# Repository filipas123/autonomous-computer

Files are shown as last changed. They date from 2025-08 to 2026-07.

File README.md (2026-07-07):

# Time to build your own Personal AI Computer

https://github.com/user-attachments/assets/36f7aa02-42ac-4b35-b757-a5dd3b43ef1a

## The future of AI is local

AI in 2026 looks like computing in 1975: the intelligence lives in a few mainframes, owned by a few companies, and you rent it by the token. Everyone knows how that movie ends. The machine moves onto the desk — and the people who own their machines build everything that comes next.

The Personal AI Computer is that machine. The models are good, the GPUs are affordable, and homes and businesses are reaching the same answer: bring it in-house. Three reasons:

1. **No one can switch you off.** In June 2026 the US government took Fable 5 offline for most of a month and gated GPT-5.6 behind an approved-partner list. Weights on your own disk can't be revoked.
2. **Your business is their training data.** Every prompt you send OpenAI or Anthropic carries your product, your process, your edge. They will turn your secret sauce into their product.
3. **Inference becomes free.** Open weights on a cloud API already cut the bill 20–30×. On your own machine there is no bill at all. No API, no meter.

## The end-to-end open-source local AI stack

Open software lets you run and shape your AI; open hardware lets you build, repair, and improve the machine it runs on. With both in your hands — the code, the CAD, the BOM, the BIOS settings — you can build the whole thing end to end. So we open-source both:

- **Open Source Hardware — this repo.** Your Personal AI Computer in four sizes, below: every part, every bracket, every BIOS setting, every assembly photo.
- **Open Source Software — your choice.** The easiest way is [Grid](https://github.com/autonomous-ai/autonomous-grid), the open orchestrator for local AI — but any local AI engine works: vLLM, Ollama, llama.cpp.

## 2× NVIDIA RTX 5090

The entry-level build, for personal use. Enough for Llama, Qwen, and DeepSeek with quantization — run OpenClaw, Hermes Agent, or your own LangChain stack locally.

- **2× NVIDIA RTX 5090** — 64 GB VRAM · 3,584 GB/s · 419 FP32 TFLOPS
- **Intel Xeon W5** (ASUS W790 ACE) · 96 GB RAM · 1 TB NVMe
- **PCIe Gen 5 ×16** per GPU · 10 GbE + 2.5 GbE
- **1,550 W draw** · 1,600 W PSU
- **12.5″ × 12.5″ × 16″** · 33 lb

**[Build the 2× 5090 →](2x-5090/README.md)**

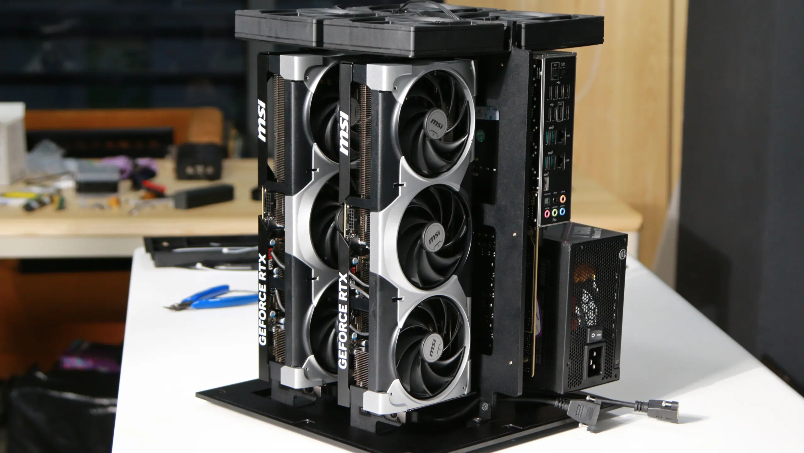
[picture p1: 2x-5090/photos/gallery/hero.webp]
The 2× 5090 build — two RTX 5090s on the open frame


<table>
<tr>
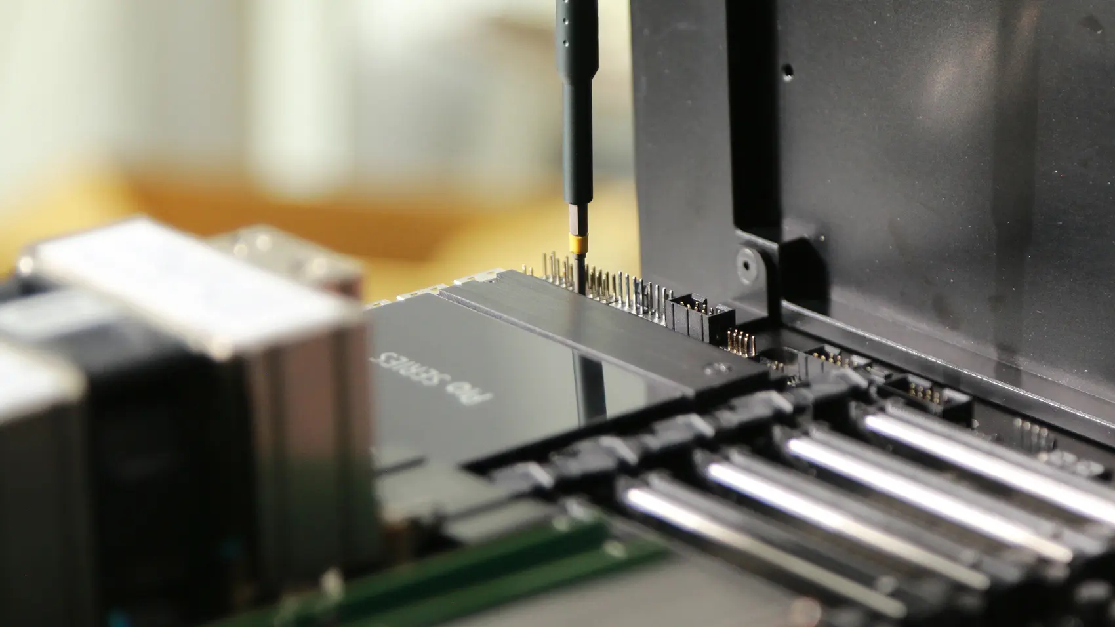
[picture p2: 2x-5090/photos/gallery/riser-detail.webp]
Seating the PCIe riser
<td width="50%"></td>
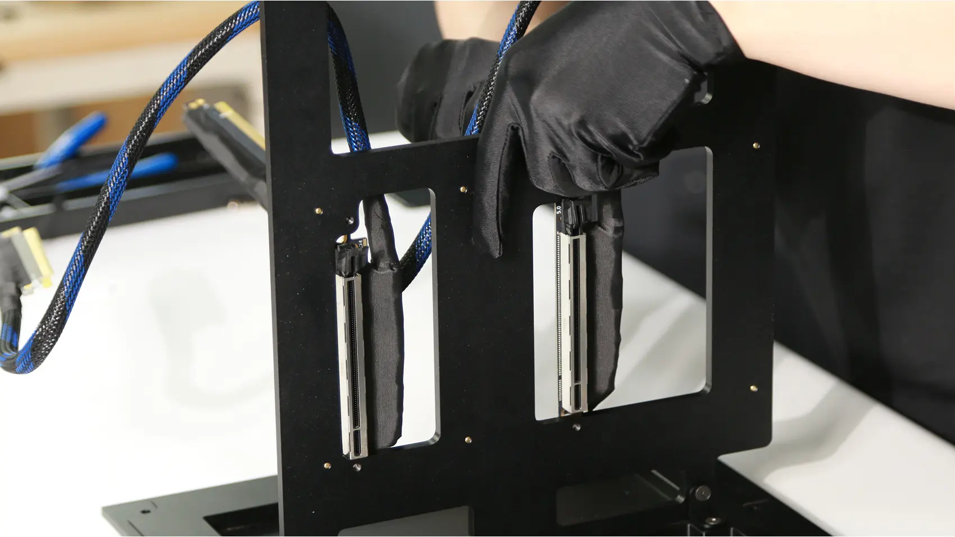
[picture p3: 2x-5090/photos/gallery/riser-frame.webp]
Mounting the PCIe 5.0 risers
<td width="50%"></td>
</tr>
<tr>
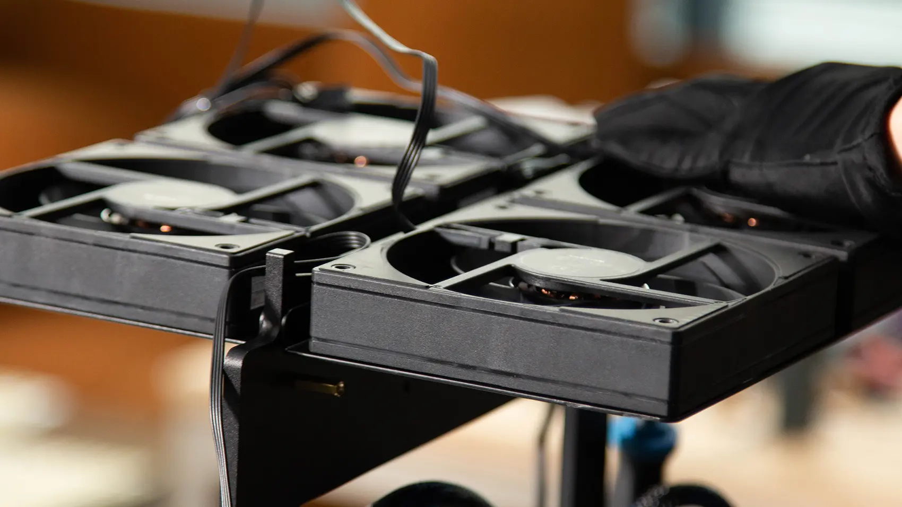
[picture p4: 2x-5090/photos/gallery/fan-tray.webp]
The fan tray
<td width="50%"></td>
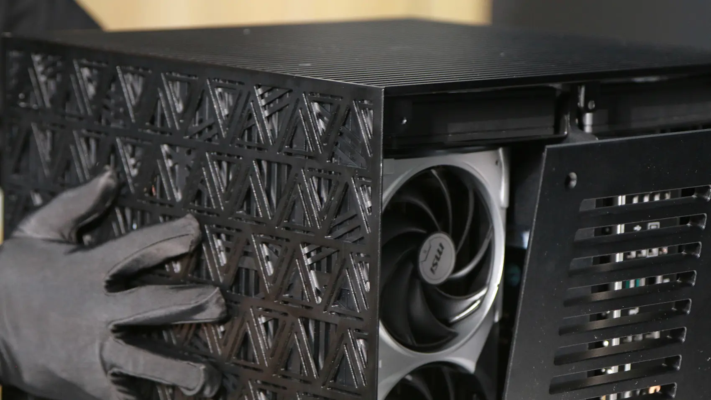
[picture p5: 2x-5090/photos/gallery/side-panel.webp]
Closing the side panel
<td width="50%"></td>
</tr>
</table>

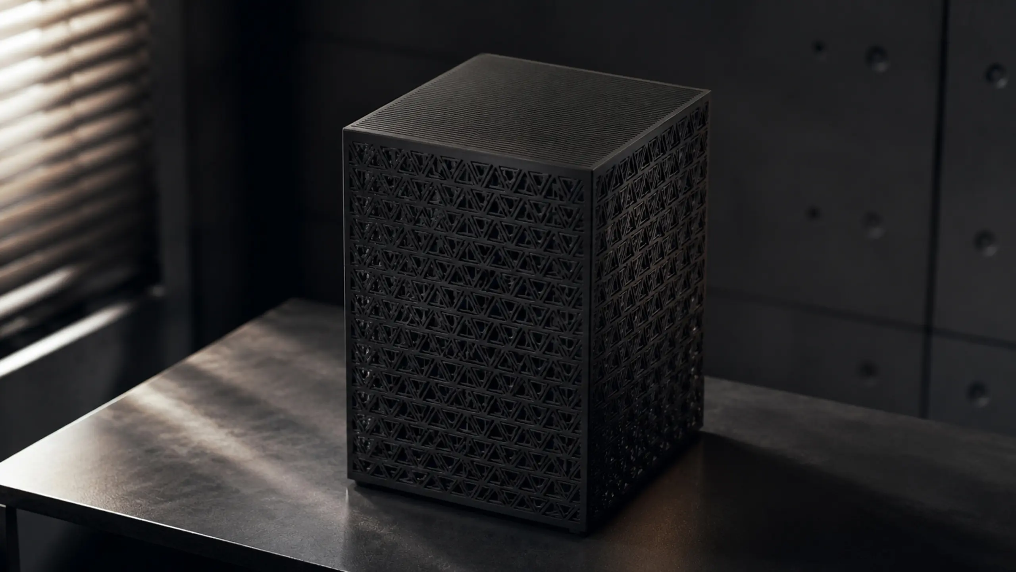
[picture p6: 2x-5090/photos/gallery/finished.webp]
The finished 2× 5090


## 4× NVIDIA RTX 5090

The team build. Larger open models like Kimi, MiniMax, and GLM. No API bills. Low latency. Private data.

- **4× NVIDIA RTX 5090** — 128 GB VRAM · 7,168 GB/s · 838 FP32 TFLOPS
- **AMD Ryzen Threadripper Pro** · 96 GB RAM · 1 TB NVMe
- **PCIe Gen 5 ×16** per GPU · 2× 10 GbE · BMC
- **2,750 W draw** · 4,000 W PSU
- **20″ × 20″ × 24″** · 66 lb

**[Build the 4× 5090 →](4x-5090/README.md)**

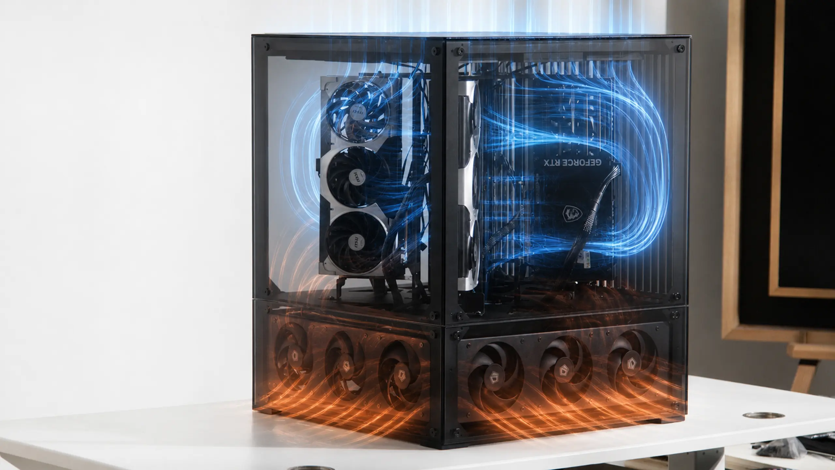
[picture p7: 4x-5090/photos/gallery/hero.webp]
The 4× 5090 build — four RTX 5090s in the cube housing


<table>
<tr>
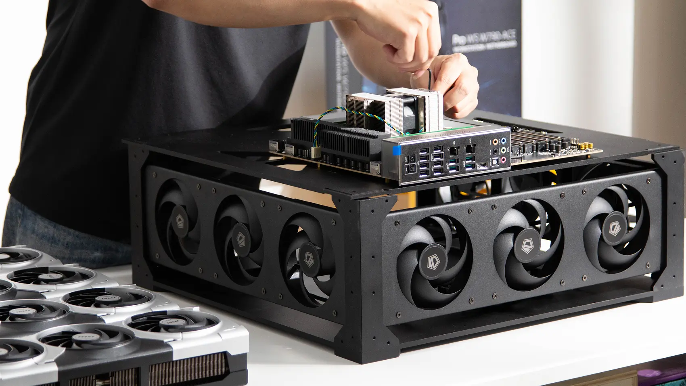
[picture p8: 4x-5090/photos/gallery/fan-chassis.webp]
Motherboard on the fan chassis
<td width="50%"></td>
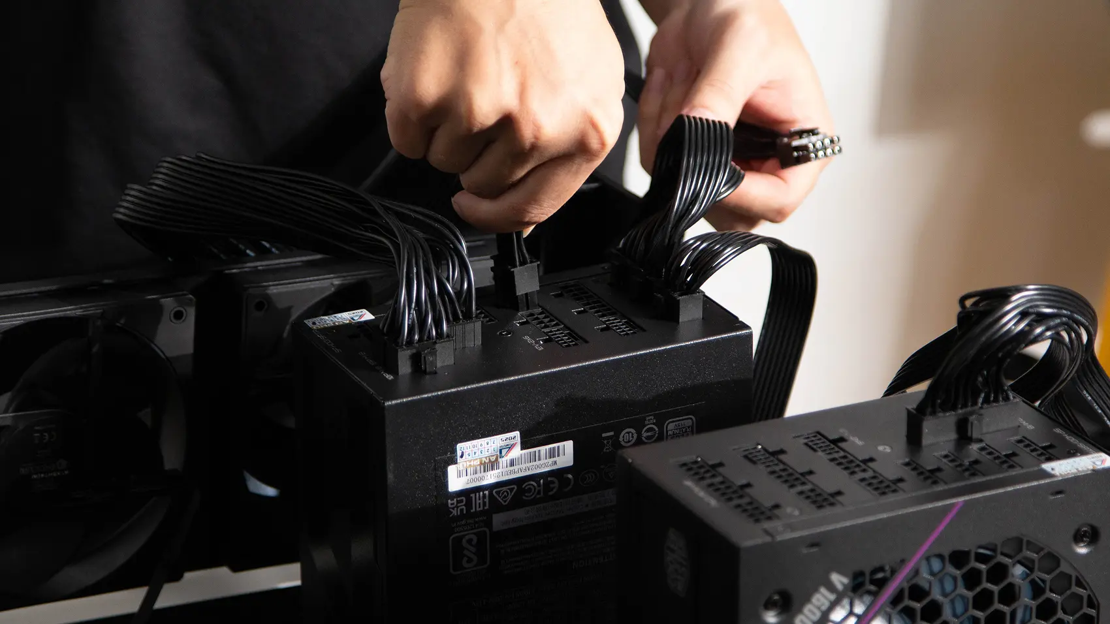
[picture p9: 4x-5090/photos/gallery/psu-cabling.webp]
Cabling the power supplies
<td width="50%"></td>
</tr>
<tr>
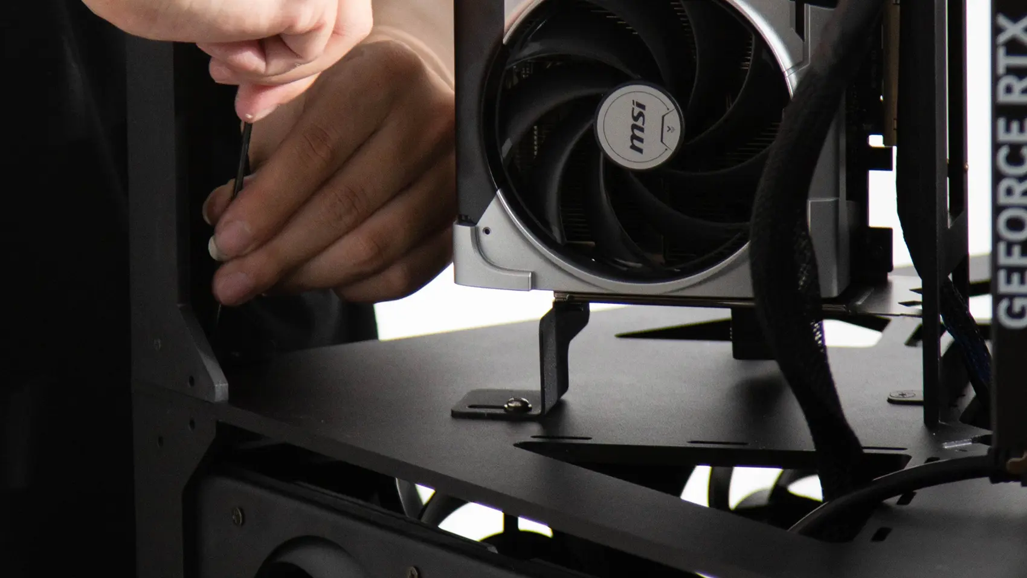
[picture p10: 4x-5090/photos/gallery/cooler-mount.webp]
Mounting a GPU to the frame
<td width="50%"></td>
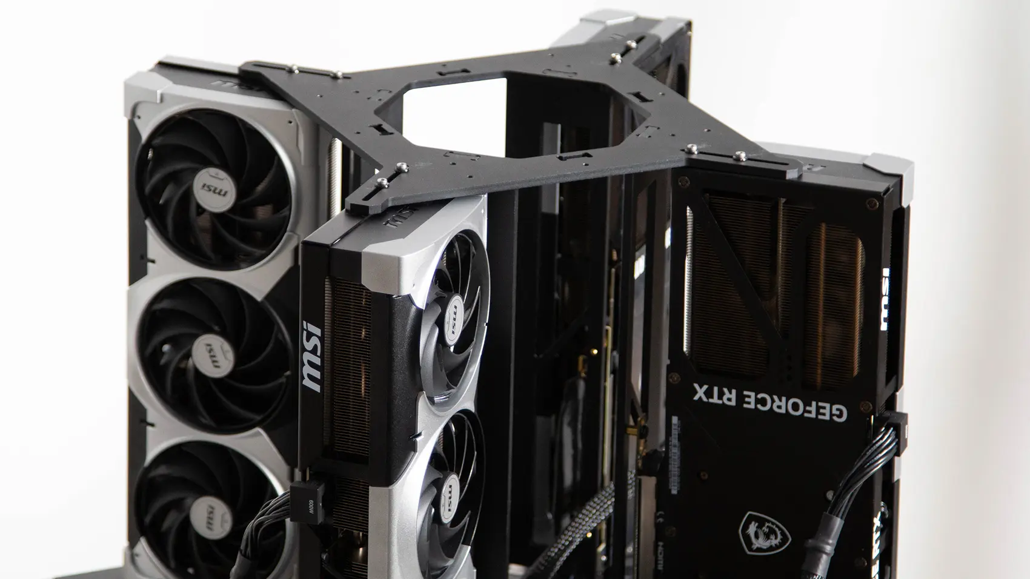
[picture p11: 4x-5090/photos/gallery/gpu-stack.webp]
All four RTX 5090s on the frame
<td width="50%"></td>
</tr>
</table>

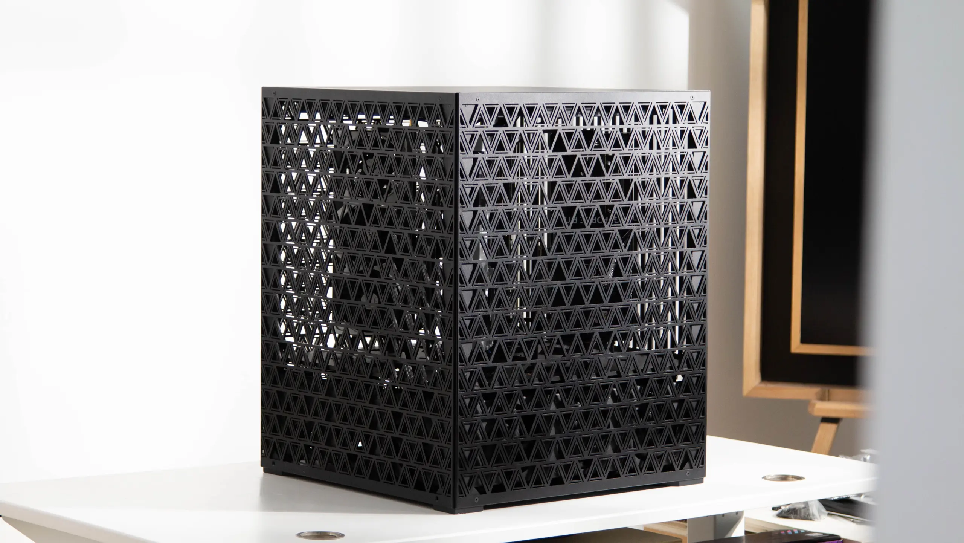
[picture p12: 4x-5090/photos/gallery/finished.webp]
The finished 4× 5090


## 8× NVIDIA RTX 5090

The on-prem build, for business. Develop, serve, and fine-tune with open models — the work that should never leave your floor.

- **8× NVIDIA RTX 5090** — 256 GB VRAM · 14,336 GB/s · 1,676 FP32 TFLOPS
- **2× AMD EPYC 9004** (ASRock Rack GENOA2D24G-2L+) · 192 GB RAM · 1 TB NVMe
- **PCIe Gen 5 ×16** per GPU, over MCIO · 2× 1 GbE · BMC
- **5,100 W draw** · 8,000 W PSU
- **15.5″ × 15.5″ × 24″** · 110 lb · CNC-milled anodized aluminum housing

**[Build the 8× 5090 →](8x-5090/README.md)**

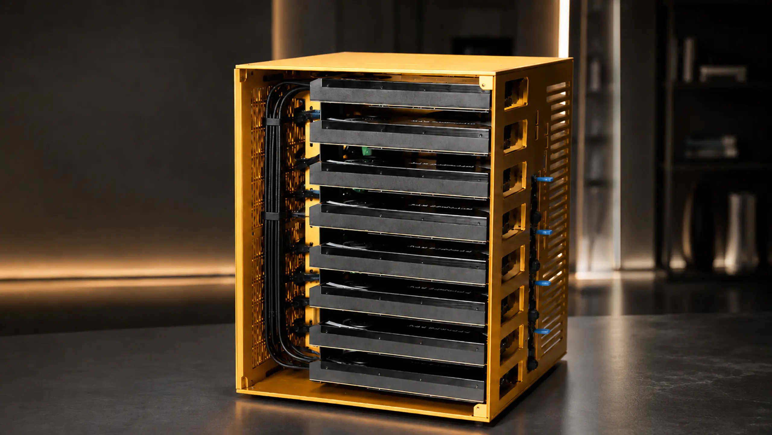
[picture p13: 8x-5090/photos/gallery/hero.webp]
The 8× 5090 build — eight GPUs in the anodized aluminum housing


<table>
<tr>
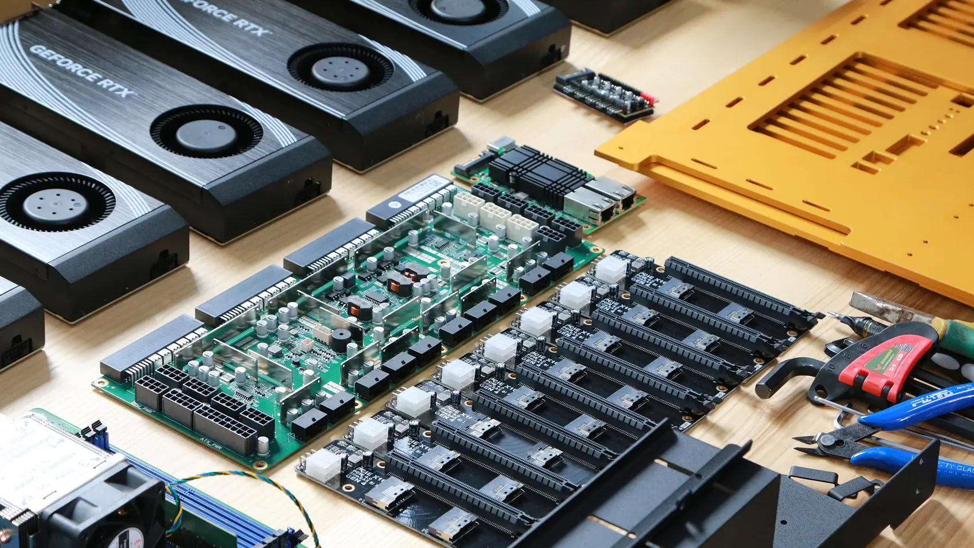
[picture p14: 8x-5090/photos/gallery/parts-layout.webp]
Every part laid out before assembly
<td width="50%"></td>
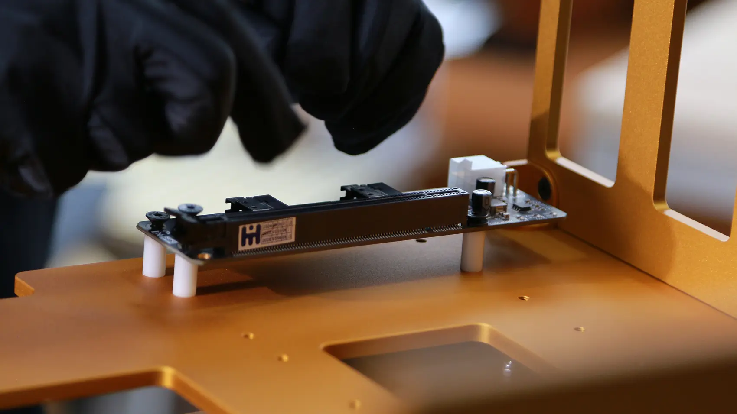
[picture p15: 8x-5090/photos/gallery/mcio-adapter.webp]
Placing an MCIO adapter
<td width="50%"></td>
</tr>
<tr>
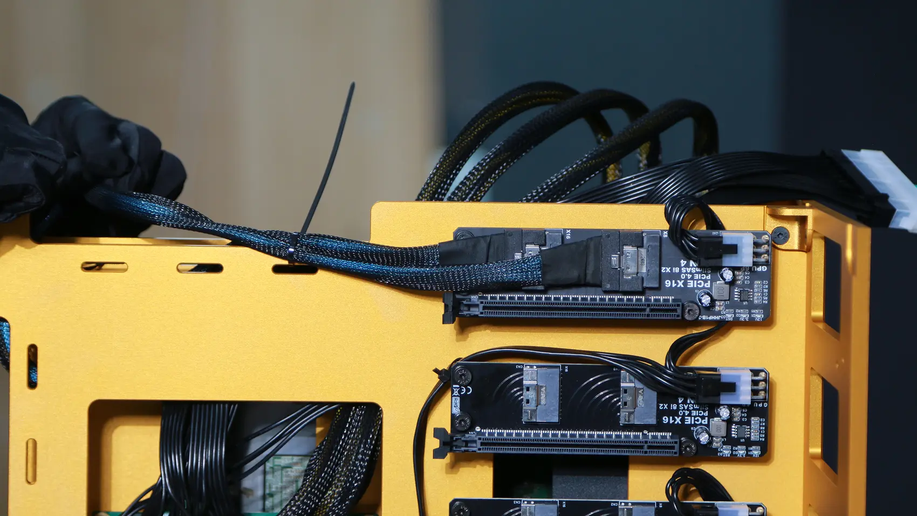
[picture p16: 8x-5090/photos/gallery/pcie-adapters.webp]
Cabling the PCIe adapters
<td width="50%"></td>
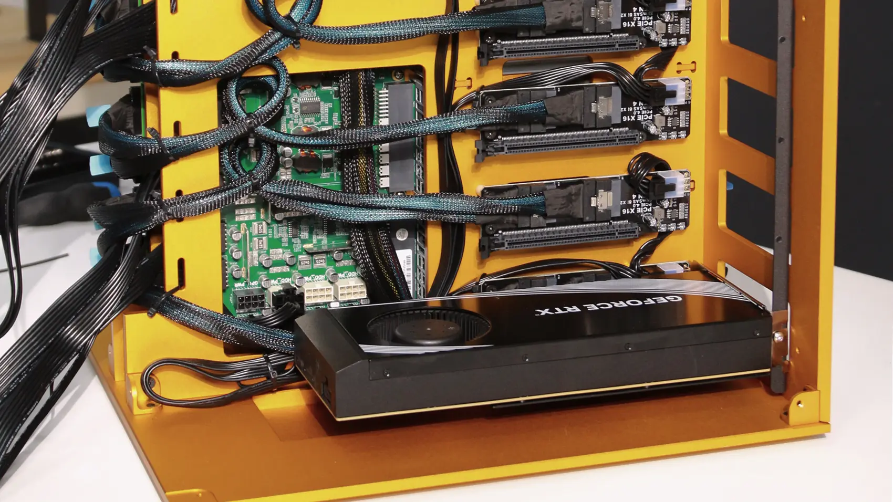
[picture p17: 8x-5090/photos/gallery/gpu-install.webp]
Installing the GPUs
<td width="50%"></td>
</tr>
</table>

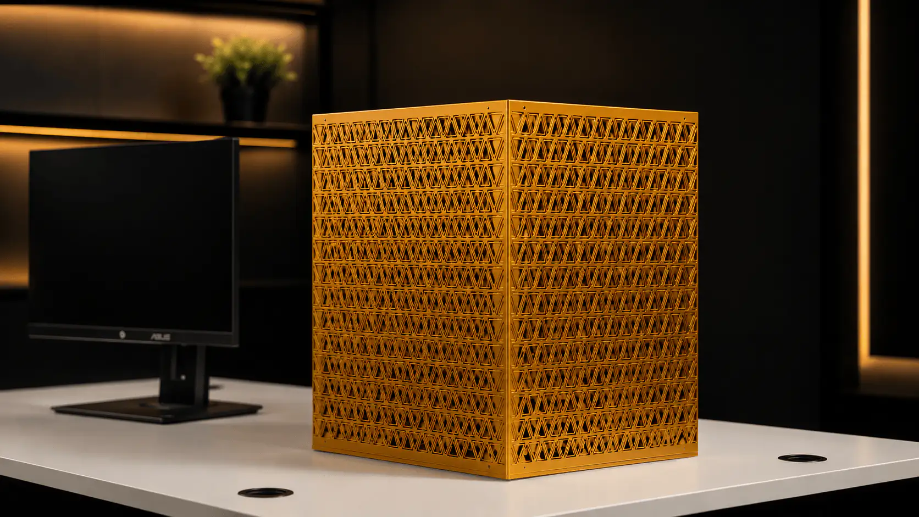
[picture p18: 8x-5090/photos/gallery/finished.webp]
The finished 8× 5090


## 4× NVIDIA RTX PRO 6000

The server build — rack-ready for on-prem and the data center. 384 GB of VRAM: fine-tune and serve the biggest open models.

- **4× NVIDIA RTX PRO 6000 Blackwell** — 384 GB GDDR7 ECC · 7,168 GB/s (96 GB per card)
- **AMD EPYC 9124** (ASRock Rack TURIN2D24G-2L+) · 384 GB DDR5 ECC · 1 TB NVMe
- **PCIe Gen 5 ×16** per GPU, over MCIO · BMC
- **3× 2,000 W** CRPS
- **5U rack chassis**

**[Build the 4× 6000 →](4x-6000/README.md)**

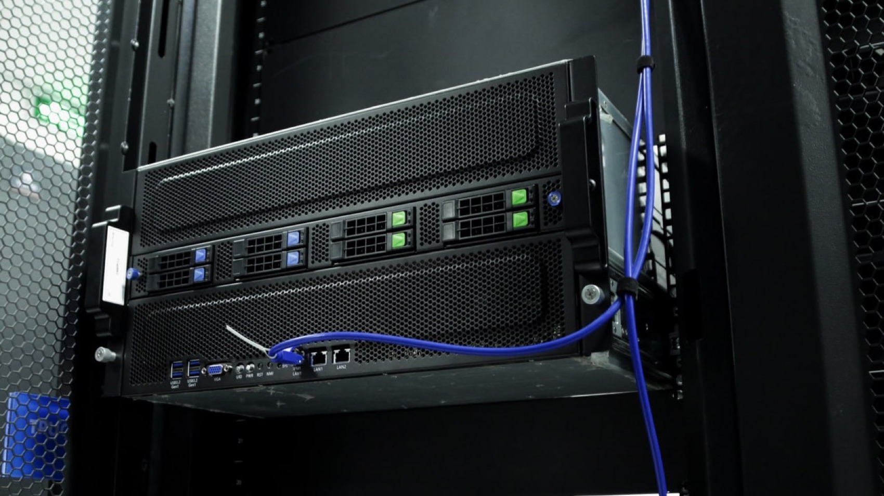
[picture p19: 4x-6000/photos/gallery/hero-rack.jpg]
The 4× 6000 build racked — 5U chassis in the server rack


<table>
<tr>
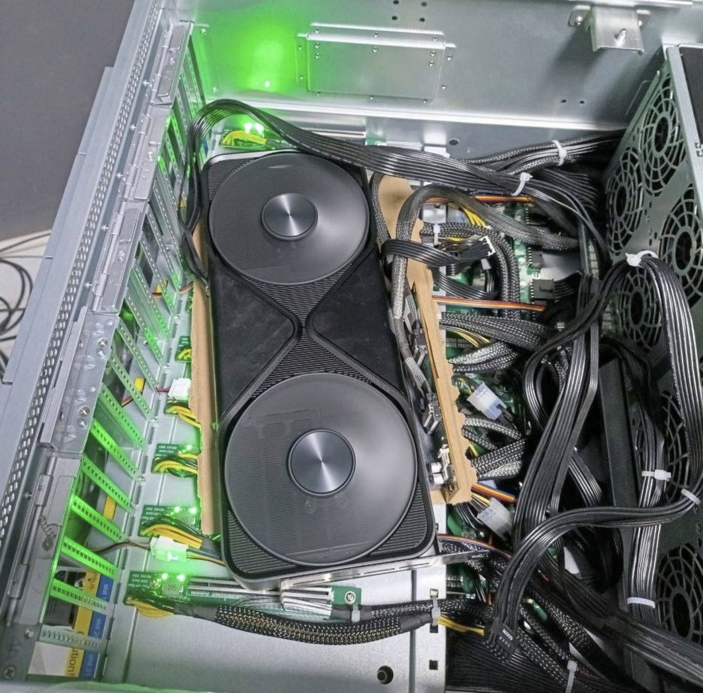
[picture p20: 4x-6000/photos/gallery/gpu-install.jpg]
Installing the RTX PRO 6000s
<td width="50%"></td>
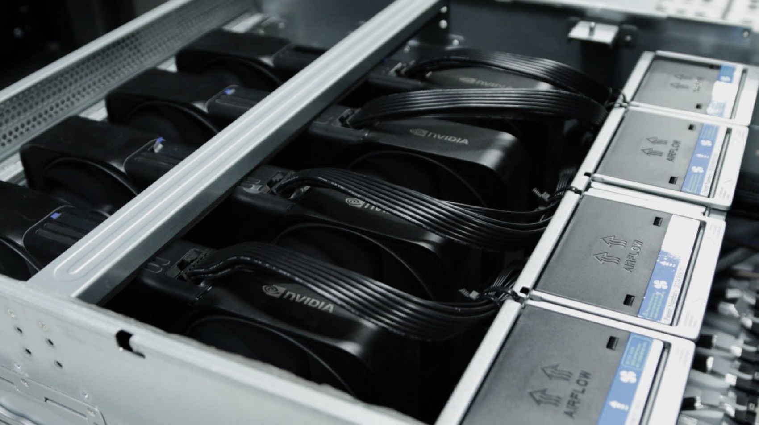
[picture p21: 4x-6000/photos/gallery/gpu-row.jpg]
Four flow-through RTX PRO 6000s over the airflow modules
<td width="50%"></td>
</tr>
<tr>
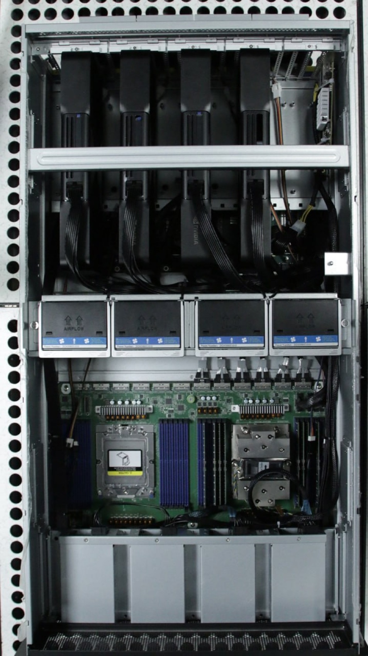
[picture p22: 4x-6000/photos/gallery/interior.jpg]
Full chassis interior — GPUs, fan wall, dual-SP5 board
<td width="50%"></td>
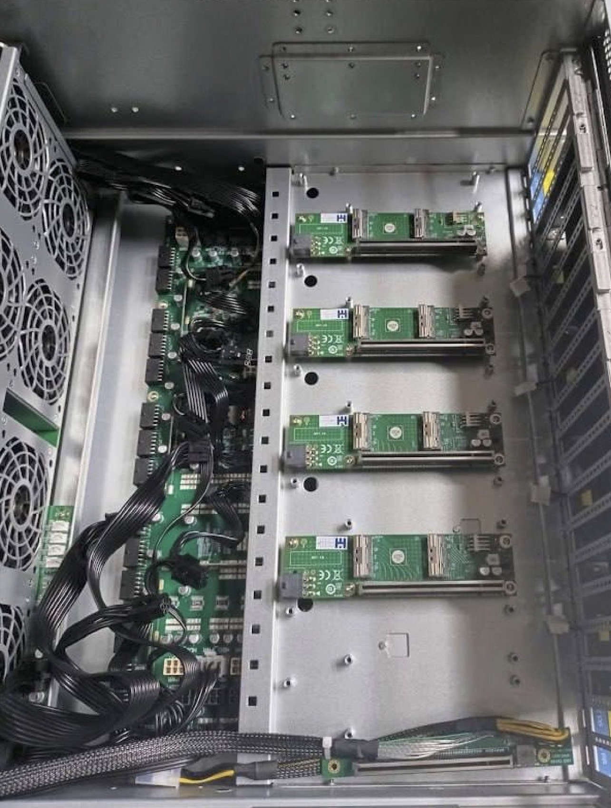
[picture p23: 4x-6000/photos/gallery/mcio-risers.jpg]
MCIO riser boards before the GPUs go in
<td width="50%"></td>
</tr>
</table>

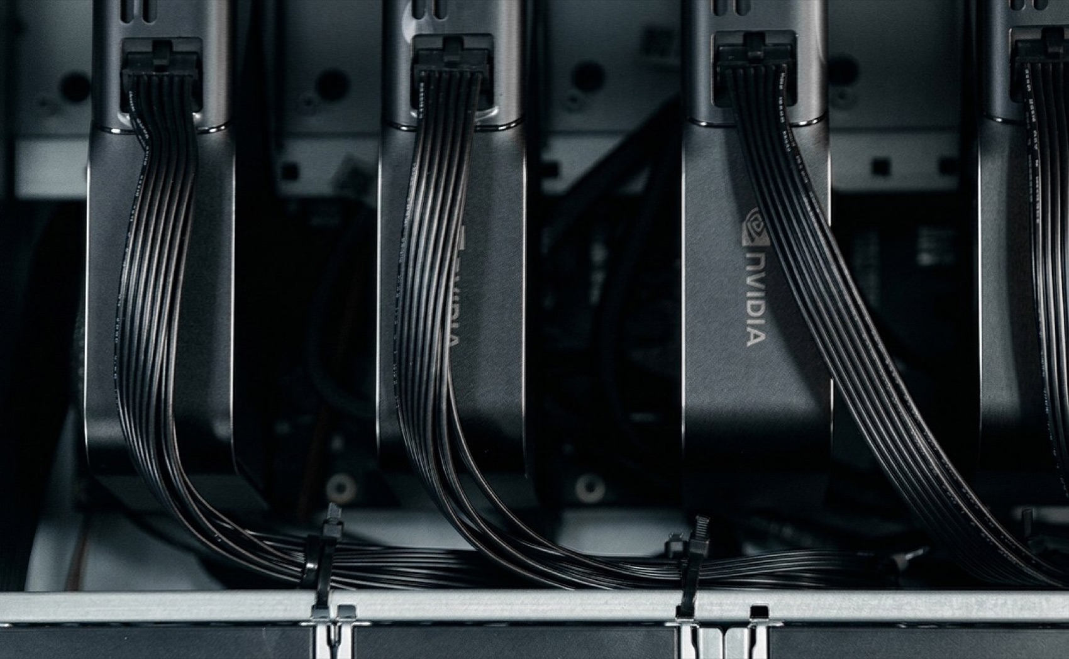
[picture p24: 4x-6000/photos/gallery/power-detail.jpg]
GPU power cabling detail


## Software

1. **[BIOS tuning and GPU testing](setup.md)** — after you build the rig, run this to make sure it actually works: BIOS settings for multi-GPU, NVIDIA drivers, then confirm every GPU is detected, linked at full PCIe width, and stable under load.

gpu-testing

2. **Serve your models** — the rig runs, now put it to work. The easiest way is [Grid](https://github.com/autonomous-ai/autonomous-grid), the open orchestrator for local AI: it pools your machines into one local AI network. Or run any local AI engine — vLLM, Ollama, llama.cpp.

   ```bash
   curl -fsSL https://grid.autonomous.ai/install.sh | bash
   ```

home-grid (1)

## Contributing

Built one? Improved a part? Found a better component? See [**CONTRIBUTING.md**](CONTRIBUTING.md) — and [share your build](https://github.com/autonomous-ai/autonomous-computer/issues/new?template=share-your-build.md). The best community builds get featured.

## License

Open source under the [MIT License](LICENSE). Fork it, change it, build your own and sell it — we just want it built.

---

<div align="center">
<b>Autonomous</b> — the AI hardware company.<br>
Questions? <a href="https://github.com/autonomous-ai/autonomous-computer/issues">Open an issue.</a>
</div>

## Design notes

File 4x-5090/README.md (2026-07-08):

# 4× NVIDIA RTX 5090

The 4× 5090 build — four RTX 5090s in the cube housing

The team build: four RTX 5090s in a cube housing on an AMD Ryzen Threadripper PRO platform. Built for larger open models like Kimi, MiniMax, and GLM. No API bills. Low latency. Private data.

- **4× NVIDIA RTX 5090** — 128 GB VRAM · 7,168 GB/s · 838 FP32 TFLOPS
- **AMD Ryzen Threadripper PRO** · 96 GB RAM · 1 TB NVMe
- **PCIe Gen 5 ×16** per GPU · 2× 10 GbE · BMC
- **2,750 W draw** · 4,000 W PSU
- **20″ × 20″ × 24″** · 66 lb

> **Draft guide** — component photos are representative and a few specs are still being confirmed; the real build photos, the board manual, and a testing screenshot are landing soon.

## Build it

1. **Parts** — the [bill of materials](bom/bom.md), with a [photo of every part](docs/prepare-ee.md); lay them all out and check them off.
2. **Housing** — the [STL files](stl-models) and the [STEP files](step_models).
3. **Assemble** — the [step-by-step assembly guide](docs/assembly.md), 23 steps from bare housing to closed box.
4. **BIOS, drivers, testing** — the shared [BIOS tuning and GPU testing](../setup.md) guide. Board-specific notes below.
5. **Serve your models** — [Grid](https://github.com/autonomous-ai/autonomous-grid), the open orchestrator for local AI, or any local AI engine: vLLM, Ollama, llama.cpp.

<table>
<tr>
<td width="50%">Motherboard on the fan chassis</td>
<td width="50%">Cabling the power supplies</td>
</tr>
<tr>
<td width="50%">Mounting a GPU to the frame</td>
<td width="50%">All four RTX 5090s on the frame</td>
</tr>
</table>

## BIOS notes and testing

The 4× runs on an AMD Ryzen Threadripper PRO (WRX90) board. The settings that matter (the general list is in [the setup guide](../setup.md)):

```
Enable Above 4G Decoding
Enable Re-size BAR support
Set every GPU slot to PCIe Gen 5 (with bifurcation as the board requires)
```

Exact menu paths depend on the motherboard — the board model and manual are being finalized.

Then make sure all four cards are detected, report full VRAM, and link at full PCIe width — the checklist is in [the setup guide](../setup.md#gpu-testing). A verification screenshot from this build is coming.

## Serve your models

The rig runs, now put it to work. The easiest way is [Grid](https://github.com/autonomous-ai/autonomous-grid), the open orchestrator for local AI: it pools your machines into one local AI network. Or run any local AI engine — vLLM, Ollama, llama.cpp.

```bash
curl -fsSL https://grid.autonomous.ai/install.sh | bash
```

Grid — your machines pooled into one local AI network

## The finished machine

The finished 4× 5090

## Other builds

The [2× 5090](../2x-5090/README.md) (start tonight), the [4× 6000](../4x-6000/README.md) (384 GB VRAM), and the [8× 5090](../8x-5090/README.md) (on-prem scale) round out the family.

## License

Open source under the [MIT License](../LICENSE).

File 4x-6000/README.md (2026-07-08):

# 4× NVIDIA RTX PRO 6000

GPU power cabling detail on the 4× 6000

The server build — rack-ready for on-prem and the data center: four RTX PRO 6000 Blackwell GPUs on an AMD EPYC platform in a 5U chassis. 384 GB of VRAM: fine-tune and serve the biggest open models to a whole team.

- **4× NVIDIA RTX PRO 6000 Blackwell** — 384 GB GDDR7 ECC · 7,168 GB/s (96 GB per card)
- **AMD EPYC 9124** (ASRock Rack TURIN2D24G-2L+) · 384 GB DDR5 ECC · 1 TB NVMe
- **PCIe Gen 5 ×16** per GPU, over MCIO · BMC
- **3× 2,000 W** CRPS
- **5U rack chassis**

## Build it

1. **Parts** — the [bill of materials](bom/bom.md), with a photo of every part; lay them all out and check them off.
2. **Housing** — the [5U chassis kit](docs/prepare-me.md) ships complete.
3. **Assemble** — the [step-by-step assembly guide](docs/assembly.md), 13 steps from bare chassis to first boot.
4. **BIOS, drivers, testing** — the shared [BIOS tuning and GPU testing](../setup.md) guide. Board-specific notes below.
5. **Serve your models** — [Grid](https://github.com/autonomous-ai/autonomous-grid), the open orchestrator for local AI, or any local AI engine: vLLM, Ollama, llama.cpp.

<table>
<tr>
<td width="50%">Installing the RTX PRO 6000s</td>
<td width="50%">Four flow-through RTX PRO 6000s over the airflow modules</td>
</tr>
<tr>
<td width="50%">Full chassis interior — GPUs, fan wall, dual-SP5 board</td>
<td width="50%">MCIO riser boards before the GPUs go in</td>
</tr>
</table>

## Inside the machine

<table>
<tr>
<td width="50%">An RTX PRO 6000 Blackwell Workstation card — flow-through cooler, 'RTX PRO 6000' shroud</td>
<td width="50%">Top-down — the dual-SP5 board, populated socket, RAM, the AIRFLOW fan wall, and the four GPUs</td>
</tr>
<tr>
<td width="50%">The four GPUs over the airflow modules, power cabling routed to the board</td>
<td width="50%">12VHPWR power cabling into the RTX PRO 6000s</td>
</tr>
</table>

## BIOS notes and testing

The TURIN2D24G-2L+ feeds the GPUs over MCIO, so link width is the setting that matters most (the general list is in [the setup guide](../setup.md)):

```
Advanced -> Chipset Configuration -> PCIE link width
  -> set the MCIO pairs feeding the 4 GPUs to Gen5 x16
Advanced -> PCI Subsystems Settings -> Enable Re-size BAR support
```

Above 4G Decoding is typically enabled by default on this platform — verify it. For exact menu locations, see ASRock Rack's motherboard and BMC manuals for the TURIN2D24G-2L+.

Then make sure all four cards are detected, report full VRAM, and link at full PCIe width — the checklist is in [the setup guide](../setup.md#gpu-testing).

## Serve your models

The rig runs, now put it to work. The easiest way is [Grid](https://github.com/autonomous-ai/autonomous-grid), the open orchestrator for local AI: it pools your machines into one local AI network. Or run any local AI engine — vLLM, Ollama, llama.cpp.

```bash
curl -fsSL https://grid.autonomous.ai/install.sh | bash
```

Grid — your machines pooled into one local AI network

## The finished machine

<table>
<tr>
<td width="50%">The 4× 6000 build racked — 5U chassis in the server rack</td>
<td width="50%">Racked in the data center — on-prem, where the data never leaves the building</td>
</tr>
</table>

## Discussion

Alternative build options brainstormed before settling on this baseline — Turin upgrade path, single-socket variants, and a 3× H100 PCIe alternative — with verification notes: [brainstorm & discussion](docs/discussion.md).

## Other builds

The [2× 5090](../2x-5090/README.md) (start tonight), the [4× 5090](../4x-5090/README.md) (the team build), and the [8× 5090](../8x-5090/README.md) (on-prem scale) scale the same idea down and up.

## License

Open source under the [MIT License](../LICENSE).

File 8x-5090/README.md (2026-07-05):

# 8× NVIDIA RTX 5090

https://github.com/user-attachments/assets/36f7aa02-42ac-4b35-b757-a5dd3b43ef1a

The on-prem build, for business: eight GPUs on a dual-EPYC (Genoa) platform in a CNC-milled, anodized aluminum housing. A team's AI on your own floor, where your IP and data never leave the building.

- **8× NVIDIA RTX 5090** — 256 GB VRAM · 14,336 GB/s · 1,676 FP32 TFLOPS
- **2× AMD EPYC 9004** (ASRock Rack GENOA2D24G-2L+) · 192 GB RAM · 1 TB NVMe
- **PCIe Gen 5 ×16** per GPU, over MCIO · 2× 1 GbE · BMC
- **5,100 W draw** · 8,000 W PSU
- **15.5″ × 15.5″ × 24″** · 110 lb

## Build it

1. **Parts** — the [bill of materials](bom/bom.md).
2. **Housing** — the [STEP files](step_models) (STL versions in [stl-models](stl-models)).
3. **Lay out the electronics** — the [component checklist](docs/prepare-ee.md), with a photo of every part.
4. **Assemble** — the [photo-by-photo assembly guide](docs/assembly.md), 39 steps from bare plates to a running machine.
5. **BIOS, drivers, testing** — the shared [BIOS tuning and GPU testing](../setup.md) guide. Board-specific notes below.
6. **Serve your models** — [Grid](https://github.com/autonomous-ai/autonomous-grid), the open orchestrator for local AI, or any local AI engine: vLLM, Ollama, llama.cpp.

<table>
<tr>
<td width="50%">Every part laid out before assembly</td>
<td width="50%">Placing an MCIO adapter</td>
</tr>
<tr>
<td width="50%">Cabling the PCIe adapters</td>
<td width="50%">Installing the GPUs</td>
</tr>
</table>

## BIOS notes for this board

The GENOA2D24G-2L+ feeds the GPUs over MCIO, so link width is the setting that matters most (the general list is in [the setup guide](../setup.md)):

```
Advanced -> Chipset Configuration -> PCIE link width
  -> set MCIO2/1, MCIO4/3, MCIO6/5, MCIO8/7, MCIO12/11, MCIO14/13, MCIO16/15, MCIO18/17 to x16
Advanced -> PCI Subsystems Settings -> Enable Re-size BAR support
```

Above 4G Decoding is typically enabled by default on this platform — verify it.

Board references: [motherboard manual](docs/um-motherboard.pdf) · [BMC manual](docs/um-bmc.pdf)

## Testing

Make sure all eight cards are detected, report full VRAM, and link at full PCIe width — the checklist is in [the setup guide](../setup.md#gpu-testing).

<table>
    <tr>
        <td align="center">
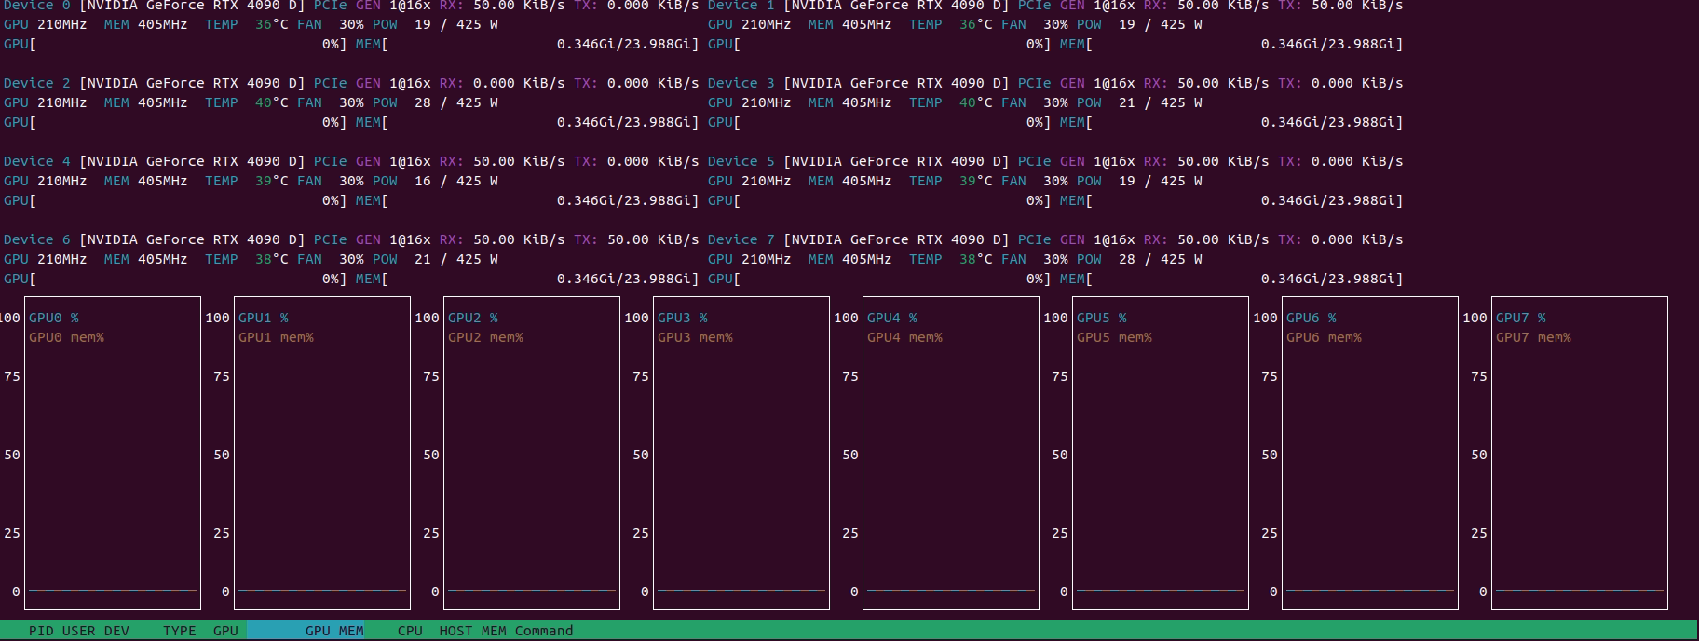
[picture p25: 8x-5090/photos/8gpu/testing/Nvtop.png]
nvtop with all eight GPUs live
            
        </td>
        <td align="center">
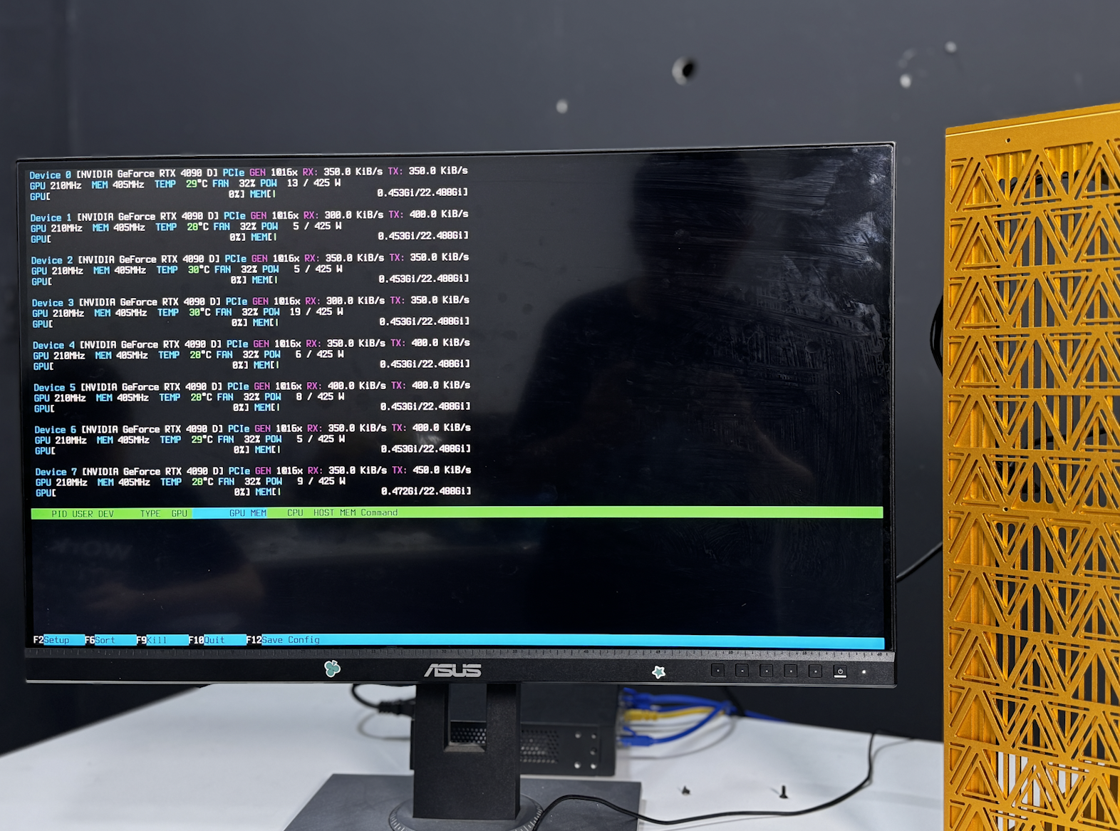
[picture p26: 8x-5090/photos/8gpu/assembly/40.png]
The assembled 8× 5090
            
        </td>
    </tr>
</table>

## Serve your models

The rig runs, now put it to work. The easiest way is [Grid](https://github.com/autonomous-ai/autonomous-grid), the open orchestrator for local AI: it pools your machines into one local AI network. Or run any local AI engine — vLLM, Ollama, llama.cpp.

```bash
curl -fsSL https://grid.autonomous.ai/install.sh | bash
```

Grid — your machines pooled into one local AI network

## The finished machine

The finished 8× 5090 on a desk

## Other builds

Smaller footprint? The [2× 5090](../2x-5090/README.md) (start tonight), the [4× 5090](../4x-5090/README.md), and the [4× 6000](../4x-6000/README.md) (384 GB VRAM) use the same playbook.

## License

Open source under the [MIT License](../LICENSE).

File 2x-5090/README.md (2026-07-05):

# 2× NVIDIA RTX 5090

The 2× 5090 build — two RTX 5090s on the open frame

The entry-level Personal AI Computer: two RTX 5090s on an Intel Xeon W platform. Desk-sized, runs on a normal wall outlet, and enough VRAM for Llama, Qwen, and DeepSeek with quantization — run OpenClaw, Hermes Agent, or your own LangChain stack with zero API spend.

- **2× NVIDIA RTX 5090** — 64 GB VRAM · 3,584 GB/s · 419 FP32 TFLOPS
- **Intel Xeon W5** (ASUS W790 ACE) · 96 GB RAM · 1 TB NVMe
- **PCIe Gen 5 ×16** per GPU · 10 GbE + 2.5 GbE
- **1,550 W draw** · 1,600 W PSU
- **12.5″ × 12.5″ × 16″** · 33 lb

## Build it

1. **Parts** — the [bill of materials](bom/bom.md).
2. **Housing** — the [STL files](stl-models) and the [STEP files](step_models).
3. **Lay out the electronics** — the [component checklist](docs/prepare-ee.md), with a photo of every part.
4. **Assemble** — the [photo-by-photo assembly guide](docs/assembly.md), 23 steps from bare housing to closed box.
5. **BIOS, drivers, testing** — the shared [BIOS tuning and GPU testing](../setup.md) guide. Board-specific notes below.
6. **Serve your models** — [Grid](https://github.com/autonomous-ai/autonomous-grid), the open orchestrator for local AI, or any local AI engine: vLLM, Ollama, llama.cpp. Details below.

<table>
<tr>
<td width="50%">Seating the PCIe riser</td>
<td width="50%">Mounting the PCIe 5.0 risers</td>
</tr>
<tr>
<td width="50%">The fan tray</td>
<td width="50%">Closing the side panel</td>
</tr>
</table>

## BIOS notes for this board

The two settings that matter on the W790 (the general list is in [the setup guide](../setup.md)):

```
Advanced -> PCI Subsystems Settings -> Enable Above 4G Decoding
Advanced -> PCI Subsystems Settings -> Enable Re-size BAR support
```

Board references: [motherboard manual](docs/um-motherboard.pdf) · [BIOS manual](docs/um-bios.pdf)

## Testing

Both cards detected, full VRAM, full PCIe width — the checklist is in [the setup guide](../setup.md#gpu-testing).

<p align="center">
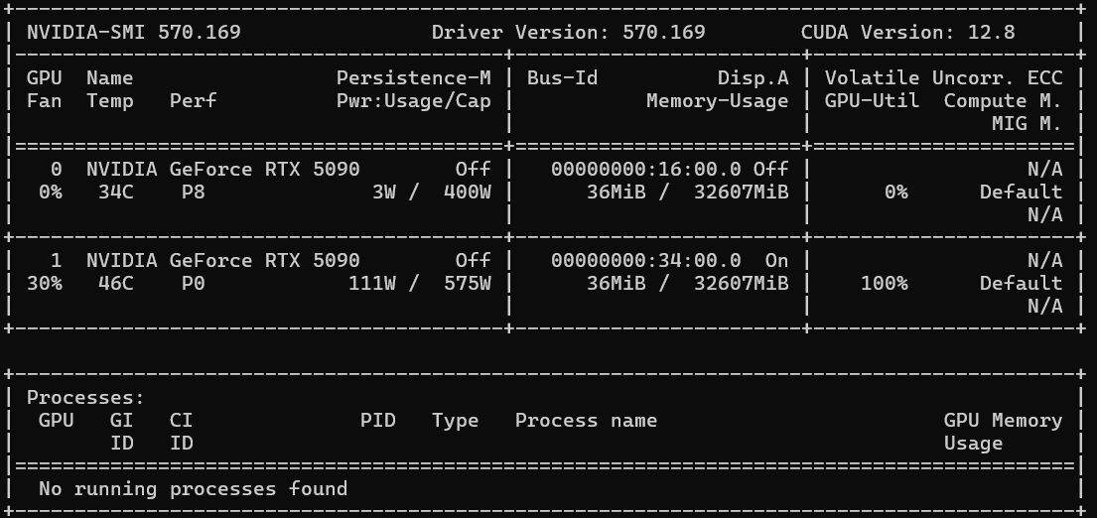
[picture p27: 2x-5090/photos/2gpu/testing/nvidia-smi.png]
nvidia-smi with both RTX 5090s detected
    
</p>

## Serve your models

The rig runs, now put it to work. The easiest way is [Grid](https://github.com/autonomous-ai/autonomous-grid), the open orchestrator for local AI: it pools your machines into one local AI network. Or run any local AI engine — vLLM, Ollama, llama.cpp.

```bash
curl -fsSL https://grid.autonomous.ai/install.sh | bash
```

Grid — your machines pooled into one local AI network

## The finished machine

The finished 2× 5090 on a desk

## Other builds

Need more? The [4× 5090](../4x-5090/README.md), the [4× 6000](../4x-6000/README.md) (384 GB VRAM, full precision), and the [8× 5090](../8x-5090/README.md) scale the same idea up.

## License

Open source under the [MIT License](../LICENSE).

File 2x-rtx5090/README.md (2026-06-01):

<p align="center">
    <a href="https://git.io/typing-svg">
        Typing SVG
    </a>
</p>

<p align="center">
    
</p>

<div align="center">










</div>

---

<div align="center">
    <b><i>
        This guide shows you how to build a cutting-edge AI server with 2x GPUs. From hardware selection to software setup, follow each step to create a high-performance platform for deep learning, data science, and GPU-intensive workloads.
    </i></b>
</div>

---

## 📚 Table of Contents
- 🏁 Introduction 
- 🛠️ Preparation 
- 🤖 Assembly 
- ⚙️ Setup
- 🧪 Testing 
- 📦 BOM
- 📝 License

---

# 🏁 Introduction &ensp; [🔝](#-table-of-contents)

<table>
    <tr>
        <td align="center" width="55%">
            <b><i>
                This tutorial guides you through building a high-performance AI server equipped with two GPUs. Whether you're a researcher, developer, or enthusiast, you'll learn everything from selecting and assembling the right hardware to configuring your system and performing initial tests. By the end, you'll have a powerful platform ready for demanding AI workloads.
            </i></b>
        </td>
        <td align="center" width="45%">
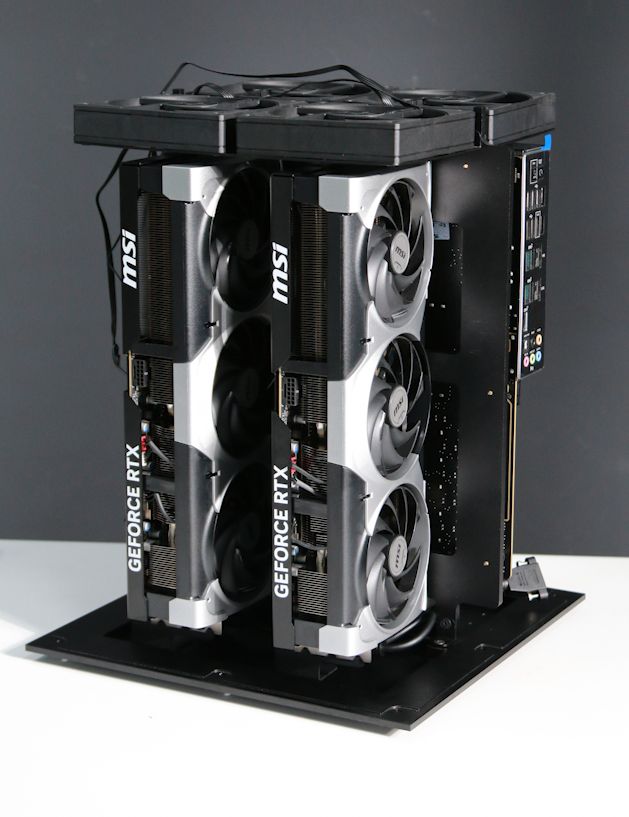
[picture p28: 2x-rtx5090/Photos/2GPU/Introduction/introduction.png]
            
        </td>
    </tr>
</table>

---

# 🛠️ Preparation &ensp; [🔝](#-table-of-contents)

### 1. [**Electronic & Electrical**](docs/Prepare_EE.md)

### 2. [**Mechanical & Housing**](step_models/)

---

# 🤖 Assembly &ensp; [🔝](#-table-of-contents)
[See detailed steps](docs/Assembly.md)

---

# ⚙️ Setup &ensp; [🔝](#-table-of-contents)
### BIOS Optimization for GPU Performance

> **Tip:** The default BIOS settings may not deliver optimal performance for multi-GPU workloads. Adjust these parameters for best results:

- **Above 4G Decoding** <br>
    🚨📢🔔⚠️
    Enable "Above 4G Decoding" to address large GPU memory.<br>
    ```
    Advanced -> PCI Subsystems Settings -> Enable Above 4G Decoding
    ```

- **Resizable BAR** <br>
    🚨📢🔔⚠️
    Activate "Resizable BAR" for improved CPU-GPU data transfer.<br>
    ```
    Advanced -> PCI Subsystems Settings -> Enable Re-size BAR support
    ```

- **Power Management**  
    Disable unnecessary power-saving features (C-states, ASPM) that may throttle GPU performance.<br>
    `Optional`

- **Memory Configuration**  
    Set RAM to rated speed and enable XMP/DOCP profiles for max bandwidth.<br>
    `Optional`

- **Fan and Thermal Controls**  
    Adjust fan curves and thermal limits for optimal cooling.<br>
    `Optional`

After saving changes, reboot and monitor GPU performance and stability.

**References:**  
- [Motherboard User Manual 💻🖱️](docs/UM_Motherboard.pdf)  
- [BMC Documents 🤖](docs/UM_BIOS.pdf)

<p align="center">
    <video src=""></video>
</p>

---

# 🧪 Testing &ensp; [🔝](#-table-of-contents)

Boot with WinPE from USB to verify hardware, or install Linux, NVIDIA drivers, and check with `nvidia-smi or nvtop`. Once confirmed, install your OS and start your AI work.

<table>
        <td align="center">
            <br>
        </td>
</table>

<p align="center">
    <video src=""></video>
</p>

---

# 📦 Bill of Materials (BOM) &ensp; [🔝](#-table-of-contents)

- [𝄜 Bill of Materials](bom/BoM.md)

---

# 📝 License &ensp; [🔝](#-table-of-contents)

This project is open source under the [MIT License](LICENSE).

---

<p align="center">
  <a href="https://git.io/typing-svg">Typing SVG</a>
</p>

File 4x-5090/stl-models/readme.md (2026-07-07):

Printable STL files for the 4× housing. CNC-ready STEP versions of the same parts are in [`../step_models`](../step_models).

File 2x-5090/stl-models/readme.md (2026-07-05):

Printable STL files for the 2× housing. CNC-ready STEP versions of the same parts are in [`../step_models`](../step_models).

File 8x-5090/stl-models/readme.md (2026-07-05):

Printable STL files for the 8× housing. CNC-ready STEP versions of the same parts are in [`../step_models`](../step_models).

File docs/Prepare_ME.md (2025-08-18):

<table>
    <tr>
        <td valign="top" align="center" width="50%">
            <b>1. CNC Mill</b><br>
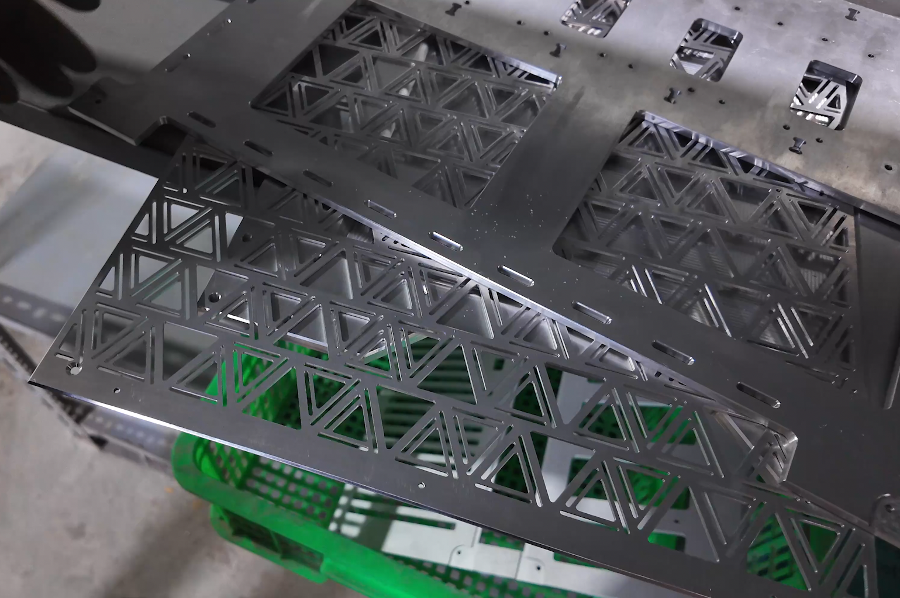
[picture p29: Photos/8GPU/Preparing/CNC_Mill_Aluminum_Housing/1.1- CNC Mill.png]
            <br>
            <b>3. Anodized</b><br>
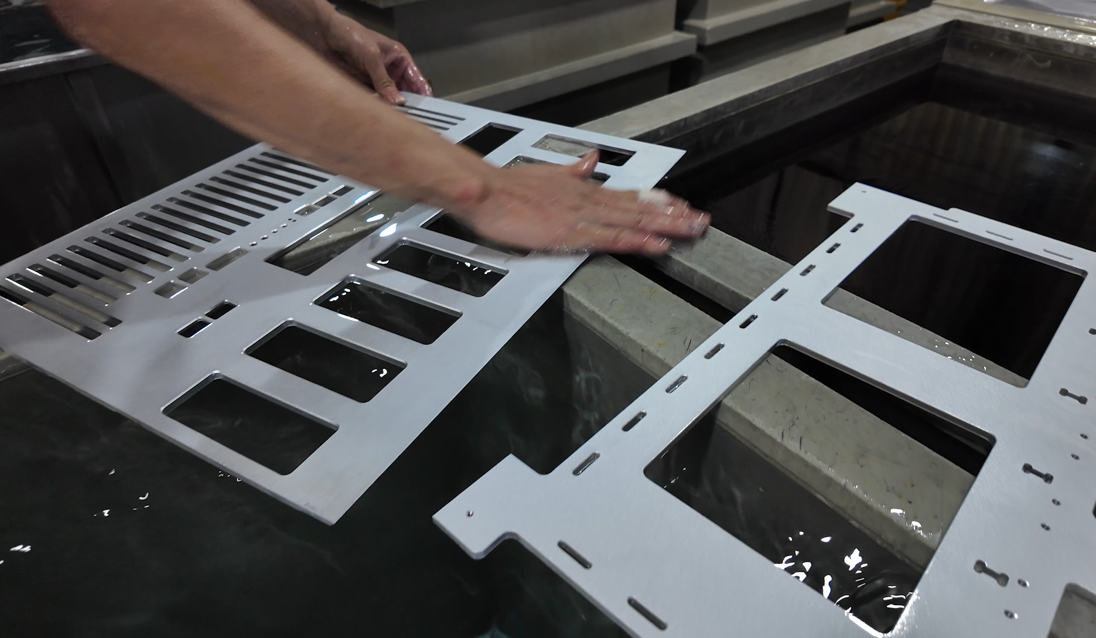
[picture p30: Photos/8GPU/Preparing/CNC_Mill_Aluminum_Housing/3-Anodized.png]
            <br>
        </td>
        <td valign="top" align="center" width="50%">
            <b>2. Sand blasting</b><br>
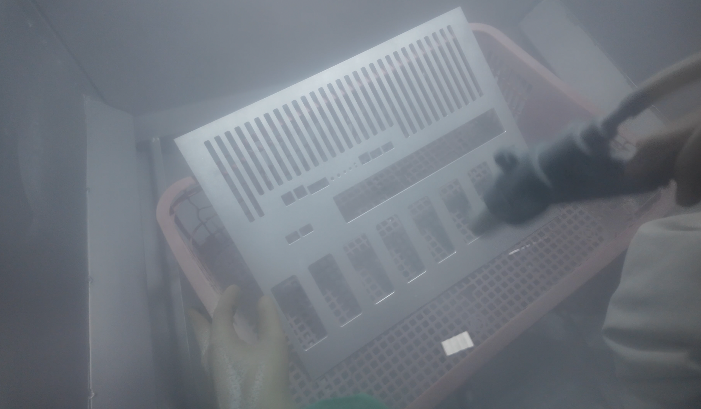
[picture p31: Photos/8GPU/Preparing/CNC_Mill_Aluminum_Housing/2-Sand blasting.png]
            <br>
            <b>4. Anodized</b><br>
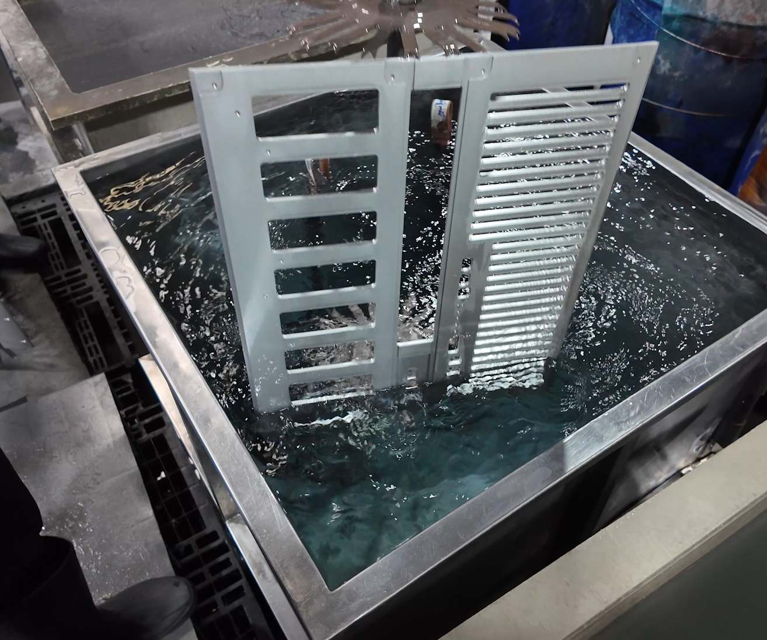
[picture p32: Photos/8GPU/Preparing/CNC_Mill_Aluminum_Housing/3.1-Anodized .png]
            <br>
        </td>
    </tr>
</table>

<p align="center">
    <video src="https://github.com/user-attachments/assets/05ee937c-a871-4809-914b-d98930b31777"></video>
</p>

---

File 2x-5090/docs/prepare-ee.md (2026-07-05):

# Preparation — Electronic & Electrical

Every part in the [bill of materials](../bom/bom.md), photographed. Lay them all out before you start assembly.

<table>
    <tr>
        <td valign="top" align="center" width="50%">
            <b>1. Motherboard — ASUS W790 ACE</b><br>
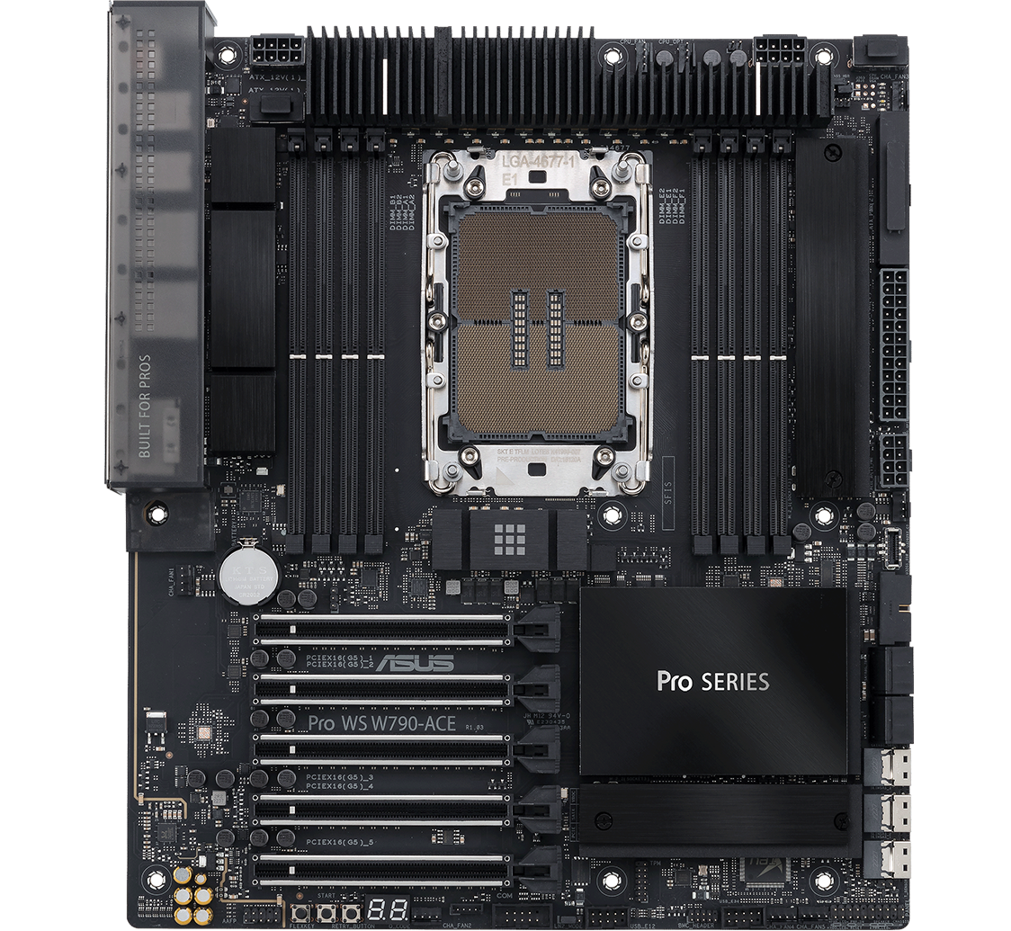
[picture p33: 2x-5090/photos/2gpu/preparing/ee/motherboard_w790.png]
            <br>
            <b>3. CPU — Intel Xeon W5</b><br>
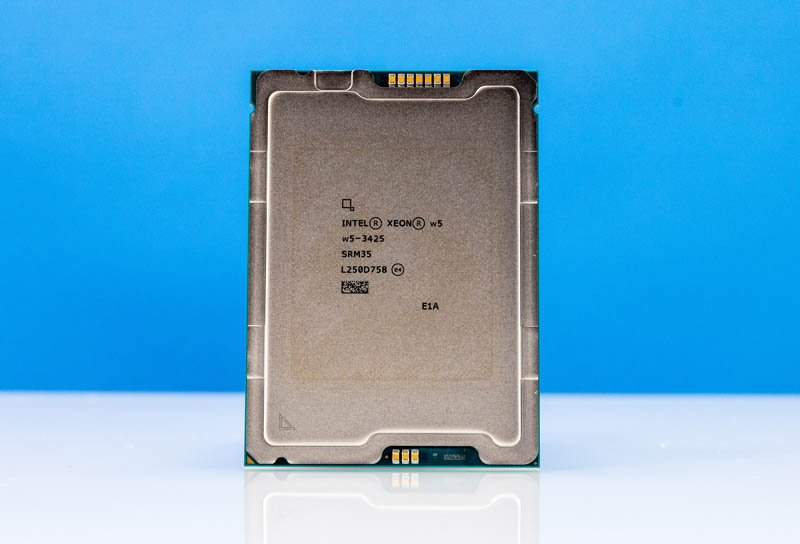
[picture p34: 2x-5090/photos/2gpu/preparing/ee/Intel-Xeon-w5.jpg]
            <br>
            <b>5. SSD — NVMe 1 TB</b><br>
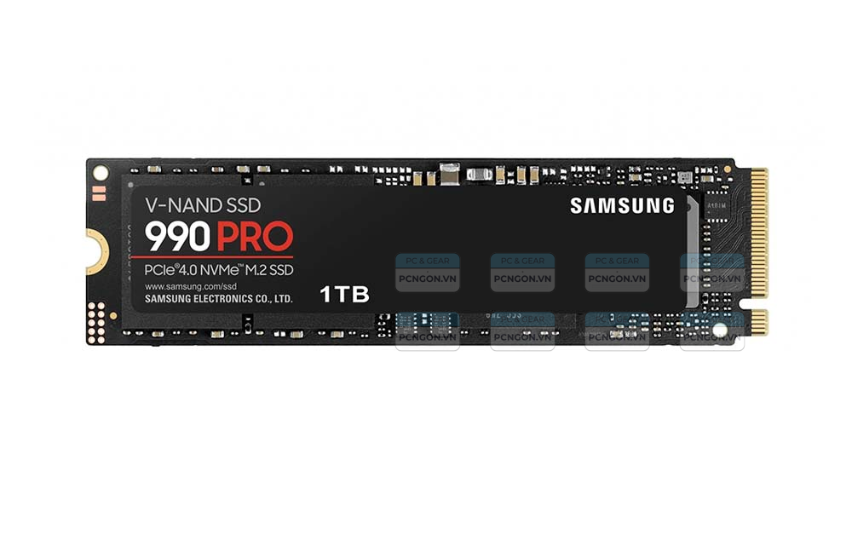
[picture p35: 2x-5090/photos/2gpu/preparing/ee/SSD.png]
            <br>
            <b>7. RAM — DDR5 48 GB</b><br>
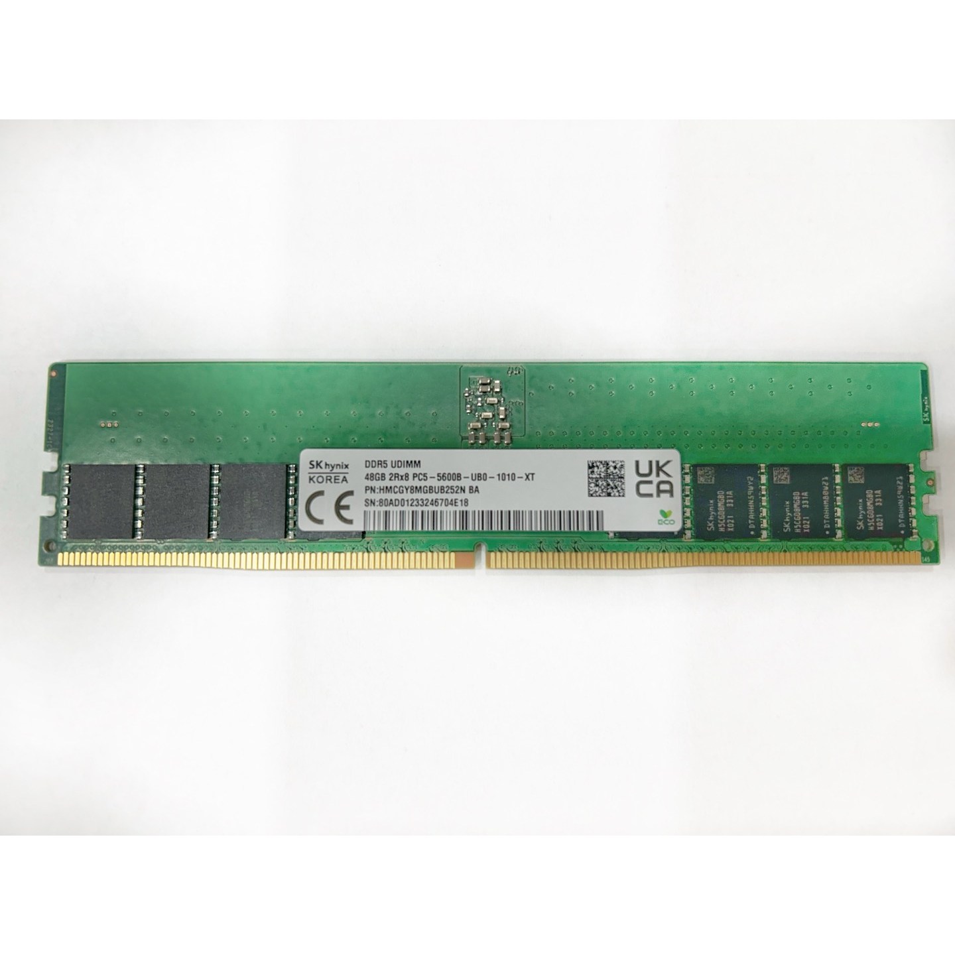
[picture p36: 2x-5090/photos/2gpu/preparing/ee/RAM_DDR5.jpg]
            <br>
            <b>9. PCIe 5.0 riser cable</b><br>
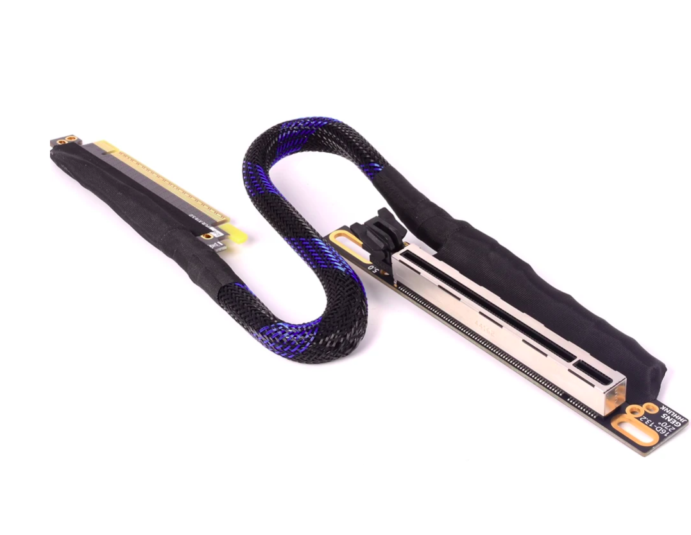
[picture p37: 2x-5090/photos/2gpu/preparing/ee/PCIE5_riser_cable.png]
            <br>
            <b>11. Fan</b><br>
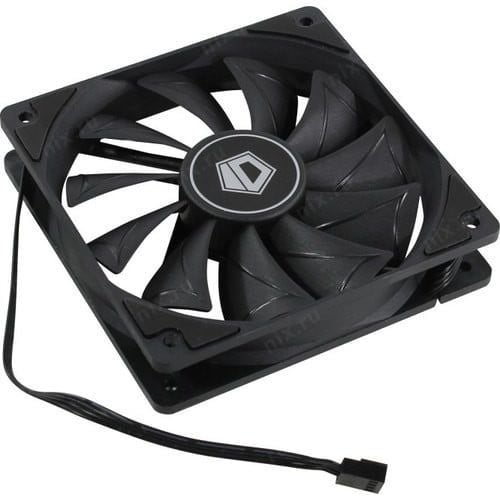
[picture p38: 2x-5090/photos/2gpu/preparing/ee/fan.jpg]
            <br>
        </td>
        <td valign="top" align="center" width="50%">
            <b>2. CPU heatsink</b><br>
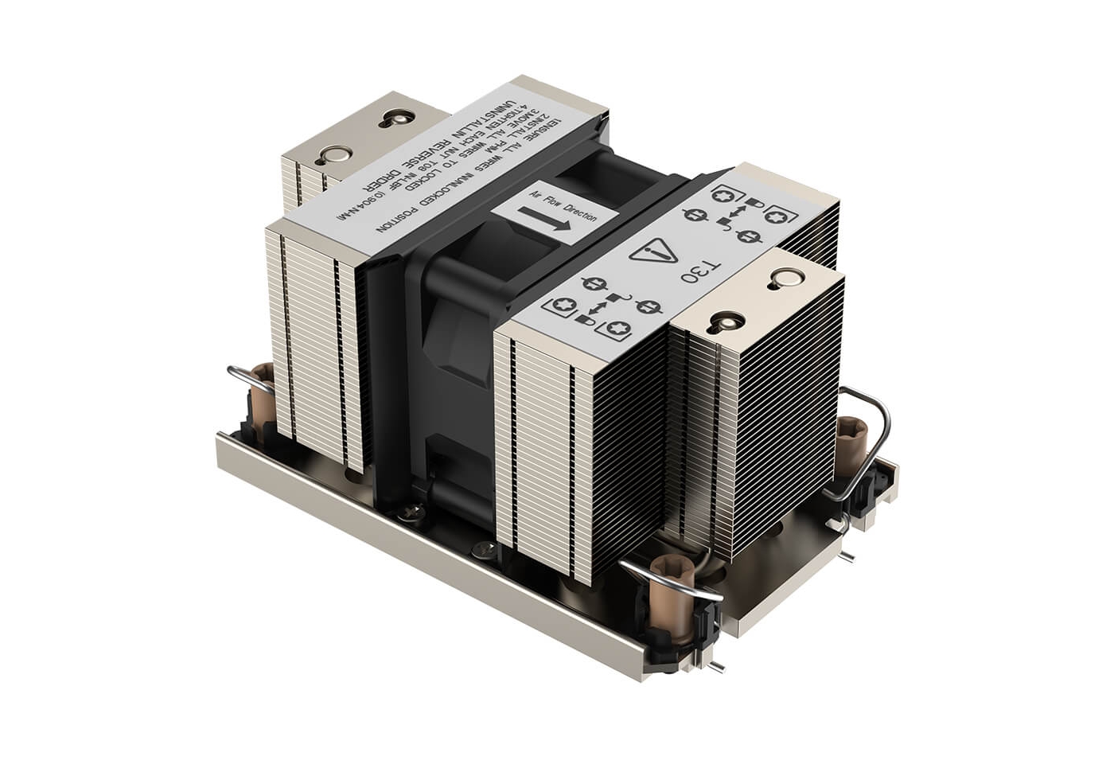
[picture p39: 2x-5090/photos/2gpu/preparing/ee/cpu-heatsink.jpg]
            <br>
            <b>4. PSU</b><br>
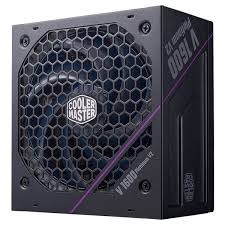
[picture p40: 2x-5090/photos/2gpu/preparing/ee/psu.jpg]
            <br>
            <b>6. Power cord</b><br>
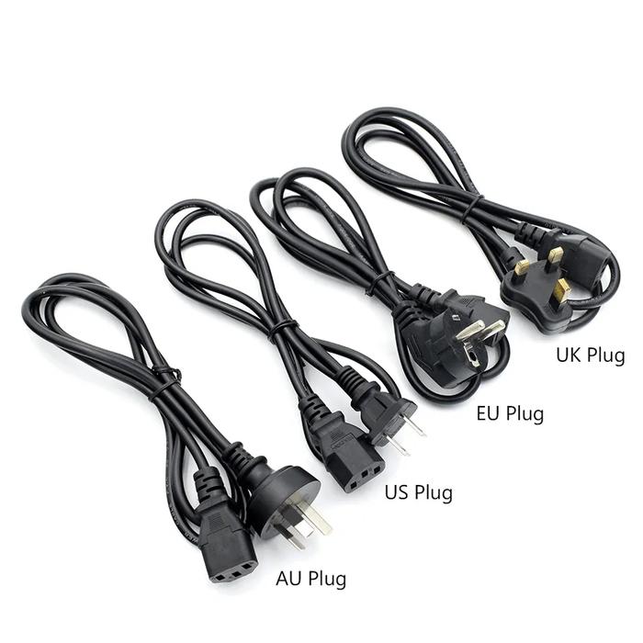
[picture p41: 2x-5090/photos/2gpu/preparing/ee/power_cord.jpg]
            <br>
            <b>8. GPU — NVIDIA RTX 5090</b><br>
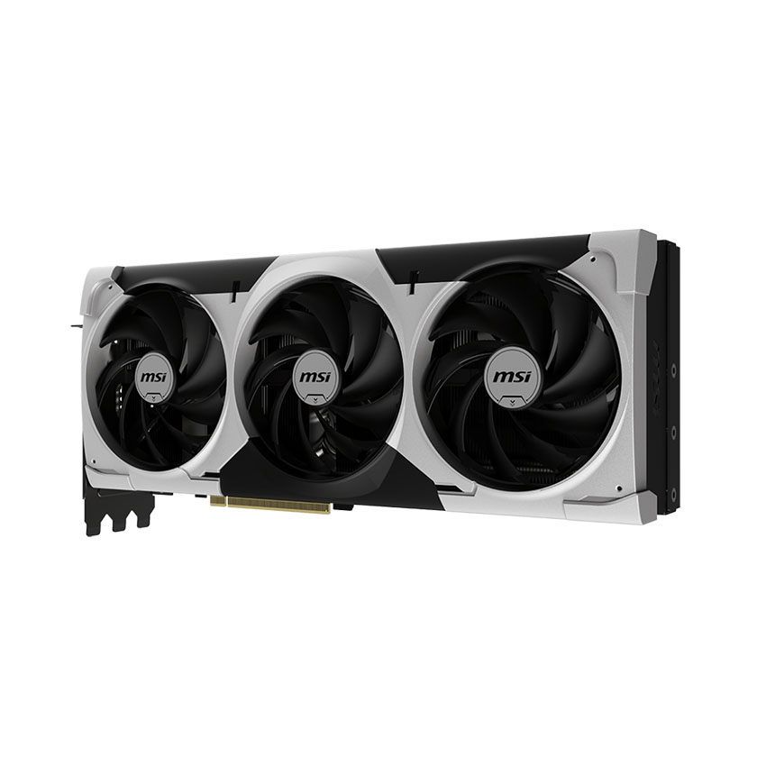
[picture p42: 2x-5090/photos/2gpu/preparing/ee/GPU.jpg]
            <br>
            <b>10. GPU power cable</b><br>
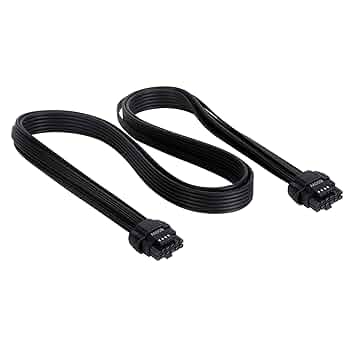
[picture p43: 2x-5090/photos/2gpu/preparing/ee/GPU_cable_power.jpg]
            <br>
        </td>
    </tr>
</table>

Next: [assembly](assembly.md).

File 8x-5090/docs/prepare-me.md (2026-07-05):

# Preparation — Mechanical & Housing

The housing is CNC-milled aluminum from the [STEP files](../step_models), then sand-blasted and anodized.

<table>
    <tr>
        <td valign="top" align="center" width="50%">
            <b>1. CNC milling</b><br>
            <br>
            <b>3. Anodizing</b><br>
            <br>
        </td>
        <td valign="top" align="center" width="50%">
            <b>2. Sand blasting</b><br>
            <br>
            <b>4. Anodized parts</b><br>
            <br>
        </td>
    </tr>
</table>

<p align="center">
    <video src="https://github.com/user-attachments/assets/05ee937c-a871-4809-914b-d98930b31777"></video>
</p>

Next: [assembly](assembly.md).

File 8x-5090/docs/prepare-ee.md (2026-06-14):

<table>
    <tr>
        <td valign="top" align="center" width="50%">
            <b>1. Motherboard GENOA2D24G-2L+</b><br>
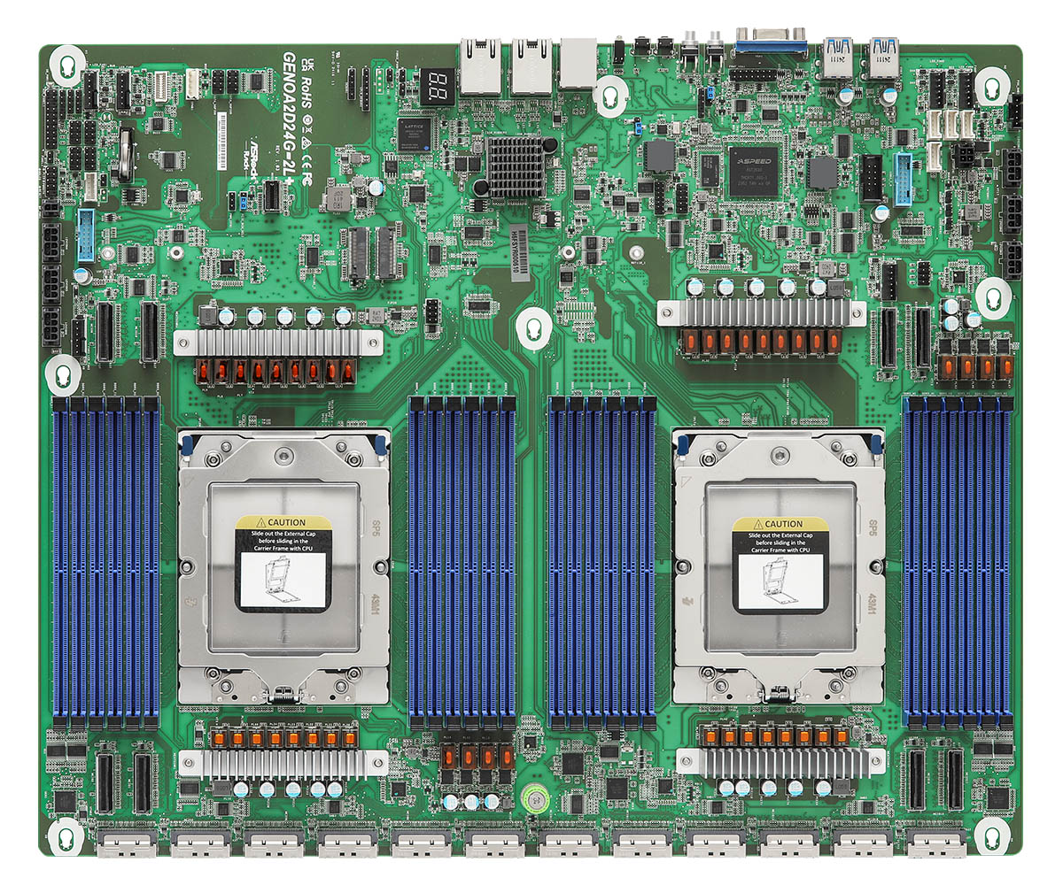
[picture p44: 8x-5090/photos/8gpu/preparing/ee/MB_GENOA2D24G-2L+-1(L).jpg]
            <br>
            <b>3. CPU AMD EPYC 9004</b><br>
            <br>
            <b>5. SSD NVME 1TB</b><br>
            <br>
            <b>7. RAM DDR5 48GB</b><br>
            <br>
            <b>9. MCIO Adapter</b><br>
            <br>
            <b>11. MCIO cable</b><br>
            <br>
            <b>13. Fan</b><br>
            <br>
            <b>15. Motherboard power cable</b><br>
            <br>
        </td>
        <td valign="top" align="center" width="50%">
            <b>2. PSU board</b><br>
            <br>
            <b>4. CPU heat sink</b><br>
            <br>
            <b>6. SSD heat sink</b><br>
            <br>
            <b>8. PSU</b><br>
            <br>
            <b>10. Power cord</b><br>
            <br>
            <b>12. GPU</b><br>
            <br>
            <b>14. Hub fan</b><br>
            <br>
            <b>16. GPU power cable</b><br>
            <br>
        </td>
    </tr>
</table>

---

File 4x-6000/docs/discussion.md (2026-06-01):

# Brainstorm & Discussion — Alternative Build Options

Three alternative builds explored before settling on the 4× RTX PRO 6000 Blackwell + EPYC 9124 baseline. Each table lists the proposed swap, the rationale, and a verification note.

---

## Option 1 — Higher-Speed Variant (RTX 5090)

| Component  | Proposed Swap | Rationale |
|:---|:---|:---|
| Mainboard  | ASRock Rack GENOAD12M-2Q (or equivalent single-socket) | Single-socket but keeps all 12 DIMM slots |
| CPU | AMD EPYC 9354 (32C) or 9454 (48C) | 2–3× the core count of 9124; higher clock to feed RTX 5090 without bottlenecking |
| RAM | 12× 64 GB DDR5-4800 / 5600 ECC RDIMM | Unchanged |
| GPU | RTX 5090 | Unchanged |
| SSD | Crucial T705 1 TB, or Samsung 990 Pro in RAID 0 | Move to PCIe 5.0 (T705) → ~14,500 MB/s read vs 7,450 MB/s on 990 Pro |
| PSU | 2000W Changcheng | Unchanged |

### Verification

| Claim | Verdict | Note |
|:---|:---:|:-----|
| `GENOAD12M-2Q` exists as ASRock Rack part number | ⚠️ | Single-socket SP5 boards from ASRock Rack exist (e.g. `GENOAD8X-2T`, `GENOAD8UD-2T/X550`). Verify the exact `GENOAD12M-2Q` SKU on ASRock Rack's site before ordering. |
| EPYC 9354 base clock (3.25 GHz) > 9124 (3.0 GHz) | ✅ | |
| EPYC 9454 has higher clock than 9124 | ❌ | 9454 base is **2.75 GHz**, *lower* than 9124. Core count is higher (48C), but the "higher clock" framing is wrong. |
| DDR5-5600 on EPYC 9004 (Genoa) | ⚠️ | Genoa is officially rated for **DDR5-4800** at 1 DPC. 5600 may run as overclock but is not guaranteed on EPYC server BIOS / QVL. |
| Crucial T705 ~14,500 MB/s vs 990 Pro ~7,450 MB/s | ✅ | Matches manufacturer specs. |

---

## Option 2 — Optimal (Single-Socket Turin + PCIe 5.0 RAID 0)

| Component  | Proposed Optimum | Why It's Faster & Cheaper |
|:---|:---|:---|
| CPU | AMD EPYC 9355 (Turin) | 32C/64T Zen 5; ~15–20% IPC uplift over Genoa; higher clock than 9354 → keeps RTX 5090 from bottlenecking |
| Mainboard  | Supermicro H13SSL-NT or Gigabyte ME03-CE0 | Dedicated single-socket SP5; Supermicro's stability is well known and pricing is friendlier than dual-socket boards |
| RAM | 12× 64 GB DDR5-6000 ECC RDIMM | **Key point:** Turin supports DDR5-6000 (vs 4800 on Genoa). Memory bandwidth improves by ~25%. |
| GPU | RTX 5090 | Unchanged |
| SSD | 2× Crucial T705 1 TB in RAID 0 | Two PCIe 5.0 drives in RAID 0 → ~28,000 MB/s sequential read. Feeds the 768 GB of RAM almost instantly. |
| Heatsink | Dynatron L31 or Noctua NH-D9 TR5-SP6 4U | Dynatron is server-grade and quieter than Coolserver; Noctua runs cooler and silent for focused work |
| PSU | FSP Cannon Pro 2000W Platinum | 80+ Platinum efficiency beats Changcheng → lower power bill and less waste heat |

### Verification

| Claim | Verdict | Note |
|:---|:---:|:-----|
| EPYC 9355 — 32C/64T Zen 5, base 3.55 GHz | ✅ | TDP 280 W. |
| Zen 5 IPC +15–20% vs Genoa | ✅ | AMD's published average is ~17% IPC. |
| 9355 clock (3.55 GHz) > 9354 (3.25 GHz) | ✅ | |
| Supermicro H13SSL-NT — single-socket SP5 | ✅ | Real product. |
| Gigabyte ME03-CE0 — single-socket SP5 | ✅ | Real product. |
| Turin supports DDR5-6000 (vs Genoa 4800), ~25% bandwidth uplift | ✅ | 6000/4800 = 1.25. |
| 2× T705 RAID 0 ~28,000 MB/s | ✅ (theoretical) | **No redundancy** — a single drive failure loses all data. Acceptable for scratch / dataset cache, not for OS / persistent state. |
| Noctua `NH-D9 TR5-SP6 4U` | ✅ | Real Noctua SKU for SP5/SP6 sockets (4U form factor). |
| Dynatron L31 for SP5 | ✅ | Real product. |
| FSP Cannon Pro 2000W Platinum | ✅ | Real; Platinum efficiency > typical Changcheng tier. |

---

## Option 3 — 3× H100 PCIe (LLM-First Build)

| Component  | Proposed Optimum | Reason |
|:---|:---|:---|
| CPU | AMD EPYC 9355 (Turin, 32C) | 2026-class build → Zen 5. Plenty of PCIe 5.0 lanes to feed 3× H100. |
| Mainboard  | Supermicro H13SSL-NT | PCIe slot spacing is wide enough for 3 thick cards |
| GPU | 3× NVIDIA H100 80GB (PCIe) | 240 GB HBM3 total. Fewer cards = fewer failure points and lower power draw than 8× RTX 5090. |
| RAM | 12× 64 GB DDR5-6000 ECC RDIMM | Keep the 768 GB RAM to stream data into the H100s |
| SSD | 2× Crucial T705 1 TB (RAID 0) | ~28 GB/s so data is never the bottleneck |
| PSU | FSP Cannon Pro 2000W Platinum | 3× H100 ≈ 1050 W + CPU/board ~400 W → 2000 W is very safe |
| Case | 4U / 7U Rackmount | H100 PCIe is **passively cooled** — needs a chassis with strong Delta/Sanyo front-to-back airflow. |

### Verification

| Claim | Verdict | Note |
|:---|:---:|:-----|
| H100 PCIe 80 GB, 350 W, HBM3, passive cooled | ✅ | |
| 3 × 80 GB = 240 GB total VRAM | ✅ | |
| Power: 3×350 + ~400 = 1450 W on a 2000 W PSU | ✅ | ~28% headroom — safe. |
| H100 PCIe requires chassis airflow (passive heatsink) | ✅ | Mandatory rackmount with high-static-pressure fans. |
| H13SSL-NT slot pitch fits 3 thick cards | ⚠️ | H13SSL-NT has 3× PCIe 5.0 x16 slots, but slot spacing isn't ideal for 3 dual-slot cards with long heatsinks. OK on paper for H100 PCIe's 2-slot passive shroud; confirm against datasheet slot pitch and chassis riser layout. |
| 4U is enough for 3× H100 + cooling | ⚠️ | 4U is tight. **5U+** or a dedicated GPU chassis is the safer envelope for sustained thermal load. |
| Fewer cards / lower power than 8× RTX 5090 | ✅ | 3×350 = 1050 W vs 8×575 = 4600 W. Also far higher memory bandwidth per dollar for LLM serving. |

---

## Summary

- **Option 1** is a moderate refresh — keep DDR5-4800, swap to a faster Genoa CPU and PCIe 5.0 SSD. Cheapest of the three. Verify the exact ASRock Rack SKU and don't claim higher clock for 9454.
- **Option 2** is the strongest single-node workstation: Turin gives both clock and a real ~25% memory bandwidth jump, RAID 0 PCIe 5.0 hits ~28 GB/s, and Platinum PSU pays itself back over time. Watch the RAID 0 redundancy story and double-check the Noctua part number.
- **Option 3** is the LLM-serving build: 3× H100 PCIe gives 240 GB of HBM3 with far better memory bandwidth than any consumer GPU stack. Plan chassis airflow carefully; 5U is the safer floor.

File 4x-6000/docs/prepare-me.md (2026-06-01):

# Preparation — Mechanical & Housing

The 5U chassis kit (case, internal cables, and power board) is supplied as a complete unit, so no separate CNC / sheet-metal preparation is required for this build.

| No  | Step | Notes |
|:---:|:---|:---|
|  1  | Unbox 5U chassis  | Verify case, cable harness, power board |
|  2  | Inspect fittings  | Standoffs, screws, fan brackets |
|  3  | Stage chassis | Place on anti-static workbench |

---

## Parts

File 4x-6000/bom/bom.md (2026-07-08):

# Bill of Materials

Quantities are **per server** — one 5U chassis with 4× RTX PRO 6000 GPUs. Lay every part out and check it off before assembly.

> Component photos are from this build; the SSD and PSU are still representative product images. Click a thumbnail to enlarge.

| No  | Item | Image | Detail | Qty | Category | Notes |
|:---:|:---|:-----:|:---|:---:|:---|:---|
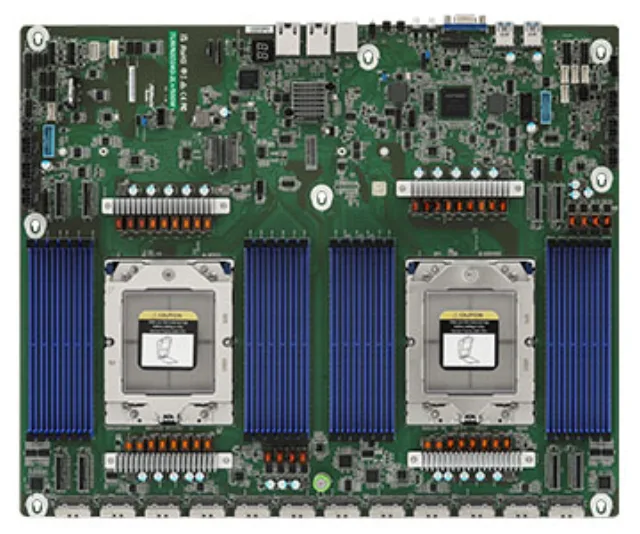
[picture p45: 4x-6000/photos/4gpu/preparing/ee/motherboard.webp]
|  1  | Mainboard |  | ASRock Rack TURIN2D24G-2L+ / 500W |  1  | Mainboard | Dual SP5; designed for EPYC 9005 (Turin) — confirm 9004 (Genoa) BIOS support for 9124 |
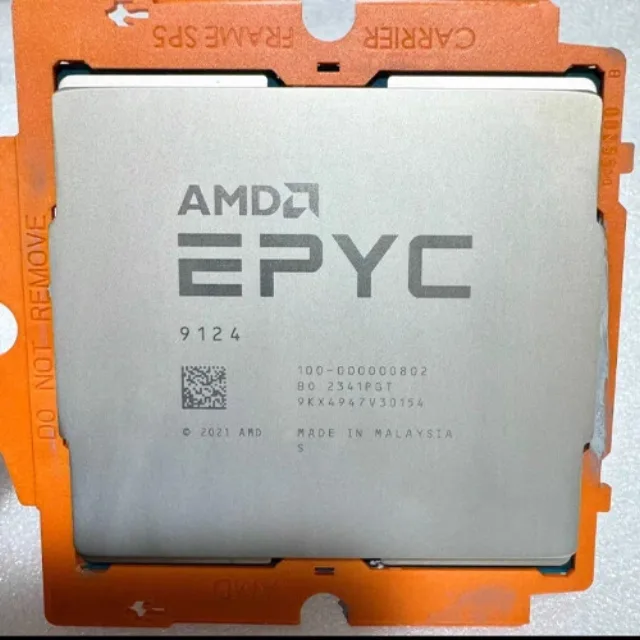
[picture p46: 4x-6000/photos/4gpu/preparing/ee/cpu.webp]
|  2  | CPU |  | AMD EPYC 9124 |  1  | Processor | 16C/32T Zen4, SP5, 200W (single-socket on a dual-socket board) |
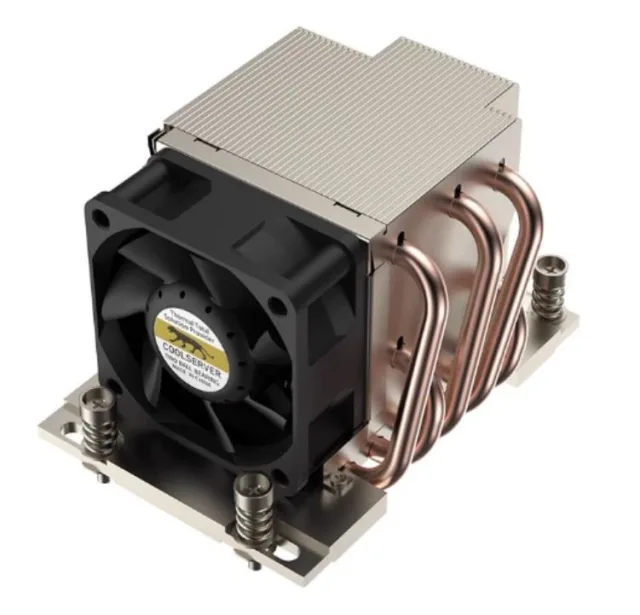
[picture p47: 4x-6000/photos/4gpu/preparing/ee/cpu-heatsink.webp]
|  3  | CPU Heatsink |  | COOLSERVER 2U AMD EPYC SP5 S22 — 6 heat pipes, L118 × W92.4 × H66.3 mm, PWM 2600–8000 RPM, 52.50 dB (max), 47.20 CFM, 4-pin PWM, 380 W |  1  | Cooling | |
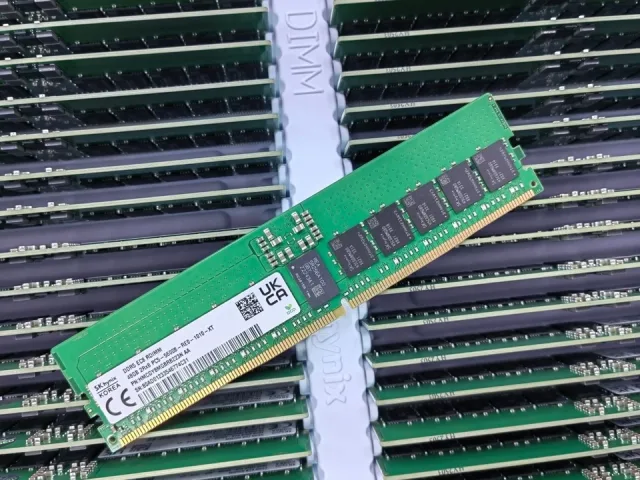
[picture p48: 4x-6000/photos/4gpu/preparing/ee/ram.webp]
|  4  | RAM |  | DDR5 ECC RDIMM 48 GB @ 5600 MT/s |  8  | Memory | 384 GB total |
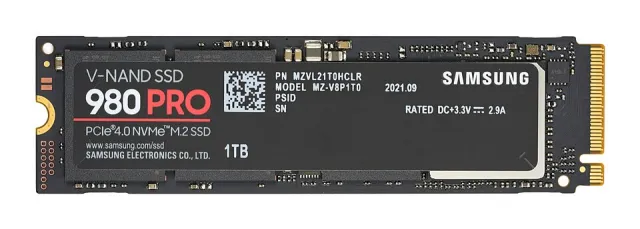
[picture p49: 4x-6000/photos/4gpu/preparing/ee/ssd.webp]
|  5  | SSD |  | Samsung 990 EVO Plus 1TB NVMe |  1  | Storage | |
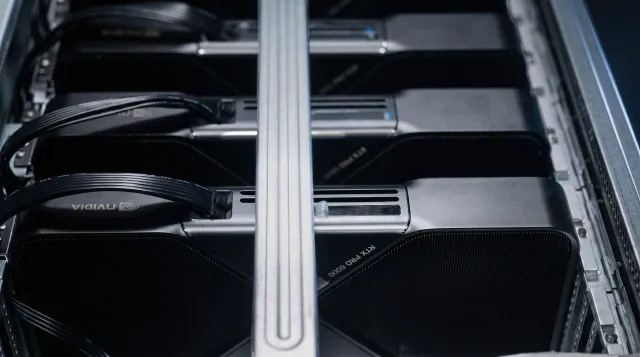
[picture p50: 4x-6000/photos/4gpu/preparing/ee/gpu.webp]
|  6  | GPU |  | NVIDIA RTX PRO 6000 Blackwell Workstation Edition (reference board 900-5G144-2200-000) |  4  | Graphics Card | |
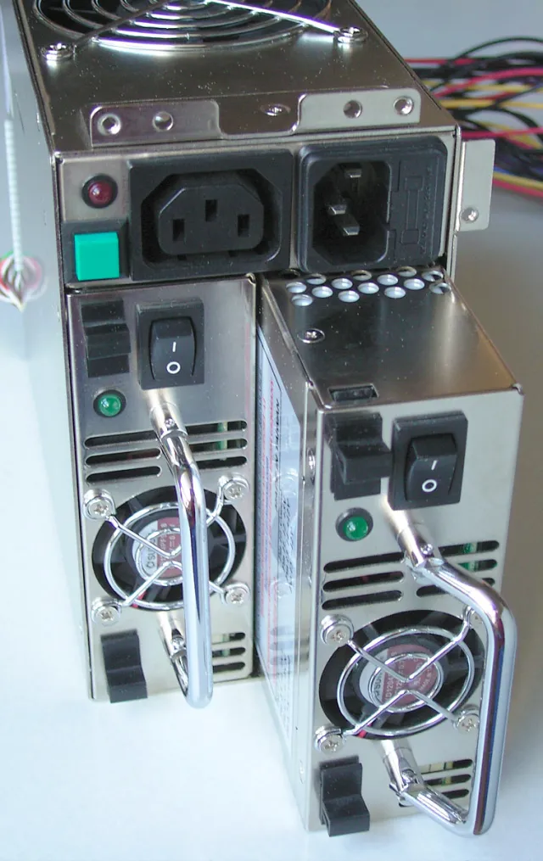
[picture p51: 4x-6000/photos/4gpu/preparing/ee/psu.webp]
|  7  | PSU |  | Changcheng (Great Wall) 2000W CRPS |  3  | Power Supply  | 6000W total |
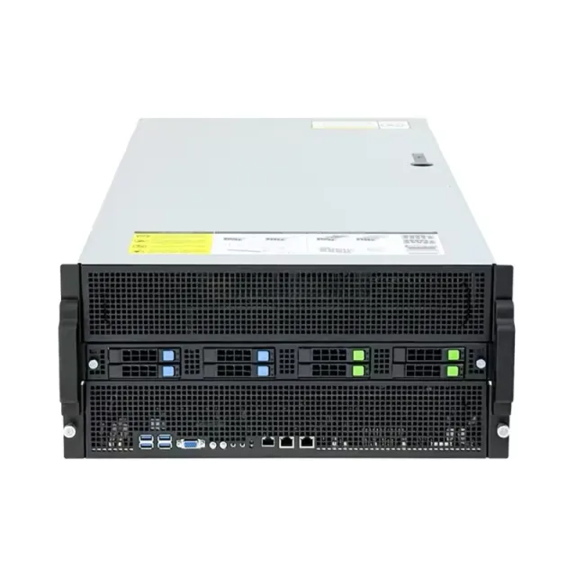
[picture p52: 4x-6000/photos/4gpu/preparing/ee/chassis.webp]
|  8  | 5U Case |  | ASRock 5U850 Gen5 chassis (case, cable harness, power board included) — supports up to 8 GPUs, populated with 4 |  1  | Housing | |

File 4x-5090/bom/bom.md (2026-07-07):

# Bill of Materials

Quantities are per machine — one 4× RTX 5090 build. Part photos are in the [component checklist](../docs/prepare-ee.md).

> Draft — exact models marked **TBD** are pending confirmation from the build team.

| No  | Item | Detail | Qty | Category | Notes |
|:---:|:---|:---|:---:|:---|:---|
|  1  | Mainboard | AMD WRX90 workstation board (model **TBD**)|  1  | Mainboard  | sTR5 socket; 2× 10 GbE + BMC per spec |
|  2  | CPU | AMD Ryzen Threadripper PRO (model **TBD**) |  1  | Processor  | sTR5 socket |
|  3  | CPU heatsink | sTR5-compatible cooler |  1  | Cooling | |
|  4  | RAM | DDR5 96 GB total |  —  | Memory | DIMM count **TBD** (per board's channel layout) |
|  5  | SSD | 1 TB NVMe |  1  | Storage | Capacity configurable |
|  6  | GPU | MSI GeForce RTX 5090 |  4  | Graphics | 32 GB each — 128 GB total |
|  7  | PCIe 5.0 riser | PCIe 5.0 x16 riser cable |  4  | Cable | One per GPU |
|  8  | PSU | 4000 W (e.g. 2× 2000 W — **TBD**) |  1  | Power | 2,750 W draw |
|  9  | GPU power cable | 12V-2x6 / 12VHPWR, 600 W rated |  4  | Cable | One per GPU |
| 10  | Power cord | Wall cord rated for the PSU |  1  | Cable | |
| 11  | Fan | Case fan |  4  | Cooling | |
| 12  | Frame housing | Full housing set (printed or CNC) |  1  | Housing | Print the [STLs](../stl-models) or CNC the [STEPs](../step_models) |

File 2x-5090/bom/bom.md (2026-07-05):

# Bill of Materials

Quantities are per machine — one 2× RTX 5090 build. Part photos are in the [component checklist](../docs/prepare-ee.md).

| No  | Item | Detail | Qty | Category | Notes |
|:---:|:---|:---|:---:|:---|:---|
|  1  | Mainboard | ASUS W790 ACE |  1  | Mainboard  | Intel W790 chipset, LGA 4677 |
|  2  | CPU | Intel Xeon W5 |  1  | Processor  | LGA 4677 socket |
|  3  | CPU heatsink | LGA 4677-compatible cooler |  1  | Cooling | |
|  4  | RAM | DDR5 48 GB |  4  | Memory | 192 GB total; configurable 1–8 DIMMs |
|  5  | SSD | 1 TB NVMe |  1  | Storage | Capacity configurable |
|  6  | GPU | NVIDIA RTX 5090 |  2  | Graphics | 32 GB each — 64 GB total |
|  7  | PCIe 5.0 riser | PCIe 5.0 x16 riser cable |  2  | Cable | One per GPU |
|  8  | PSU | 1600 W |  1  | Power | |
|  9  | GPU power cable | 12V-2x6 / 12VHPWR, 600 W rated |  2  | Cable | One per GPU |
| 10  | Power cord | Wall cord rated for the PSU |  1  | Cable | |
| 11  | Fan | Case fan |  4  | Cooling | |
| 12  | Frame housing | Full housing set |  1  | Housing | Print the [STLs](../stl-models) or CNC the [STEPs](../step_models) |

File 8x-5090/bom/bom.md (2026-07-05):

# Bill of Materials

Quantities are per machine — one 8× GPU build. Part photos are in the [component checklist](../docs/prepare-ee.md).

| No  | Item | Detail | Qty | Category | Notes |
|:---:|:---|:---|:---:|:---|:---|
|  1  | Mainboard | ASRock Rack GENOA2D24G-2L+ |  1  | Mainboard  | Dual SP5, PCIe over MCIO |
|  2  | CPU | AMD EPYC 9004 series (Genoa) |  2  | Processor  | SP5 socket |
|  3  | CPU heatsink | SP5-compatible cooler |  2  | Cooling | |
|  4  | RAM | DDR5 ECC RDIMM |  4  | Memory | Configurable 1–24 DIMMs |
|  5  | SSD | 1 TB NVMe |  1  | Storage | Capacity configurable |
|  6  | M.2 heatsink | — |  1  | Cooling | |
|  7  | GPU | NVIDIA RTX 4090 or 5090 |  8  | Graphics | 24 GB / 32 GB each — 192–256 GB total |
|  8  | MCIO cable | — | 16  | Cable | Two per GPU (x16 = 2× x8) |
|  9  | MCIO→PCIe adapter | — |  8  | Adapter | One per GPU |
| 10  | PSU | 2000 W CRPS |  4  | Power | 8000 W total |
| 11  | PSU board | Power distribution board |  1  | Power | |
| 12  | Motherboard power cable | Power-board-to-motherboard harness |  1  | Cable | 1 set |
| 13  | GPU power cable | 12V-2x6 / 12VHPWR, 600 W rated |  8  | Cable | One per GPU |
| 14  | Fan | Case fan | 12  | Cooling | |
| 15  | Fan hub | Fan control board |  1  | Cooling | |
| 16  | Frame housing | CNC-milled aluminum housing, full set |  1  | Housing | CNC the [STEPs](../step_models); [housing guide](../docs/prepare-me.md) |

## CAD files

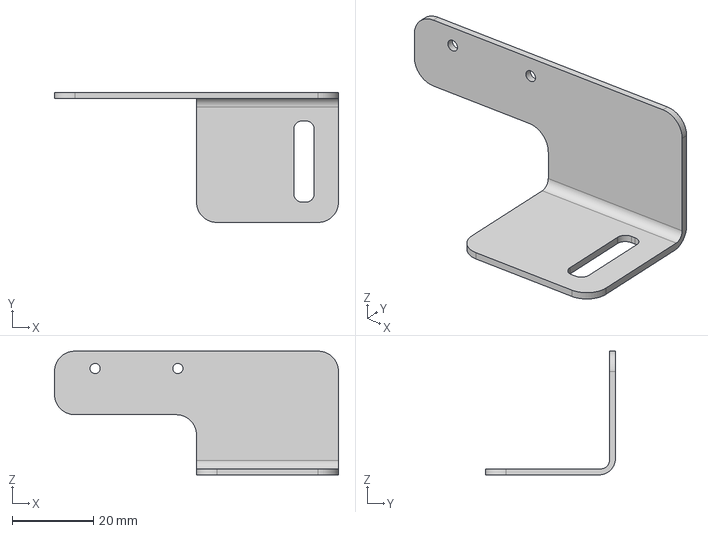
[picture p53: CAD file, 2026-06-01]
2x-5090/step_models/GPU mount 2.step
70.0 x 32.0 x 30.5 mm

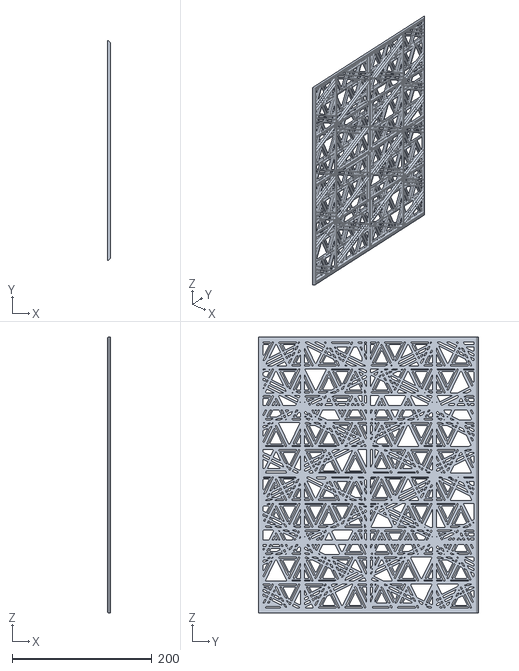
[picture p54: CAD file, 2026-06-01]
2x-5090/stl-models/Part 6 - Side cover.stl
4.00 x 315.0 x 395.0

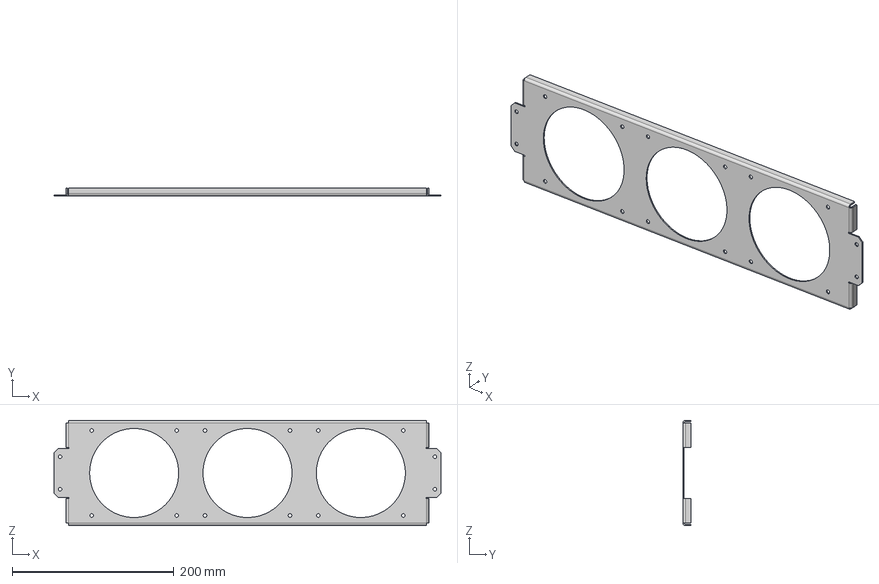
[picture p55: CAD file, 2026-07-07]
4x-5090/step_models/3 Fan mount.step
478.0 x 10.0 x 130.0 mm

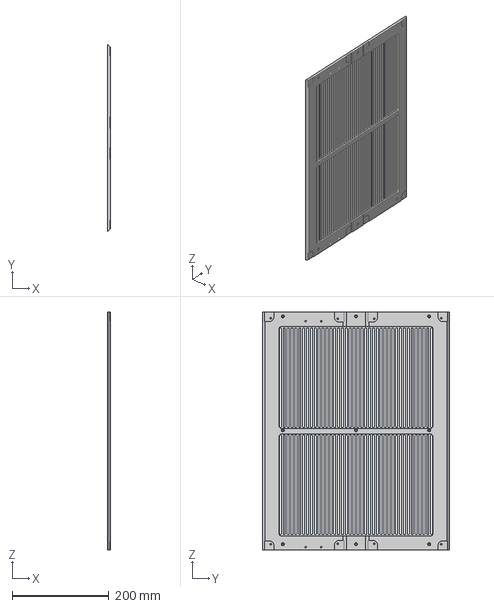
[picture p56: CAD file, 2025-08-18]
8x-5090/step_models/Part 3 - Front.step
6.00 x 386.6 x 491.0 mm

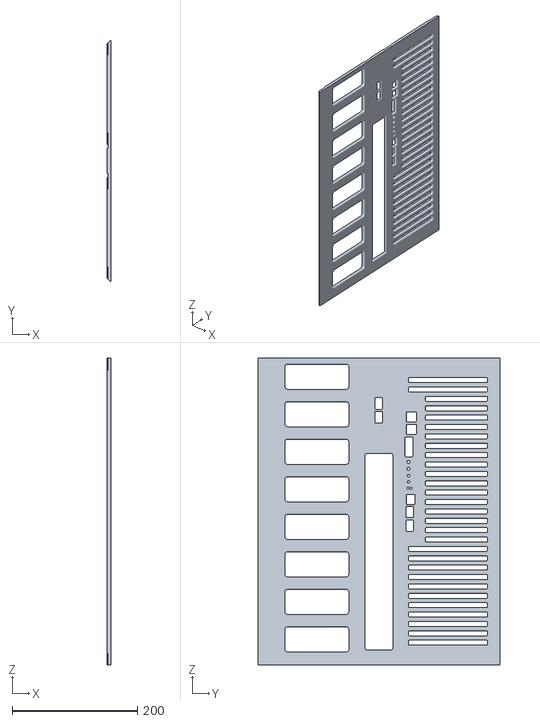
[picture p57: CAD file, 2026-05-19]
8x-5090/stl-models/Part 4 - Back.stl
6.00 x 386.6 x 491.0

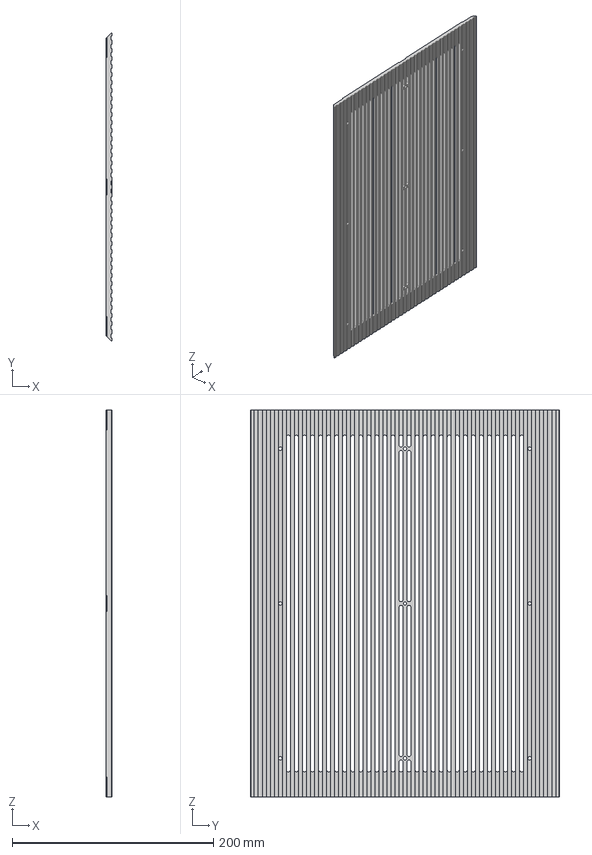
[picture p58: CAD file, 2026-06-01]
2x-5090/step_models/Part 1 - Side.step
6.00 x 307.0 x 385.0 mm

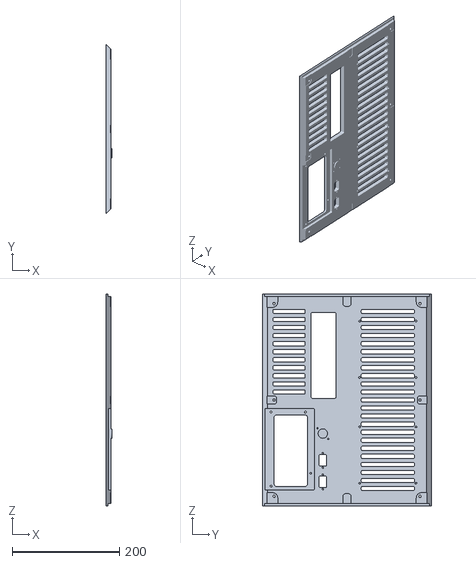
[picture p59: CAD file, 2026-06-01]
2x-5090/stl-models/Part 2 - Back.stl
12.0 x 315.0 x 395.0

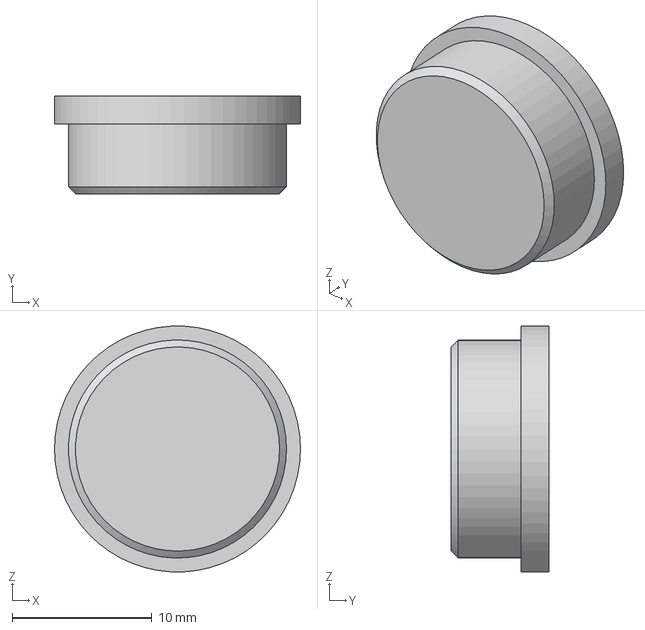
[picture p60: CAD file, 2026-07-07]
4x-5090/step_models/Part 10 - Button.step
17.6 x 7.00 x 17.6 mm

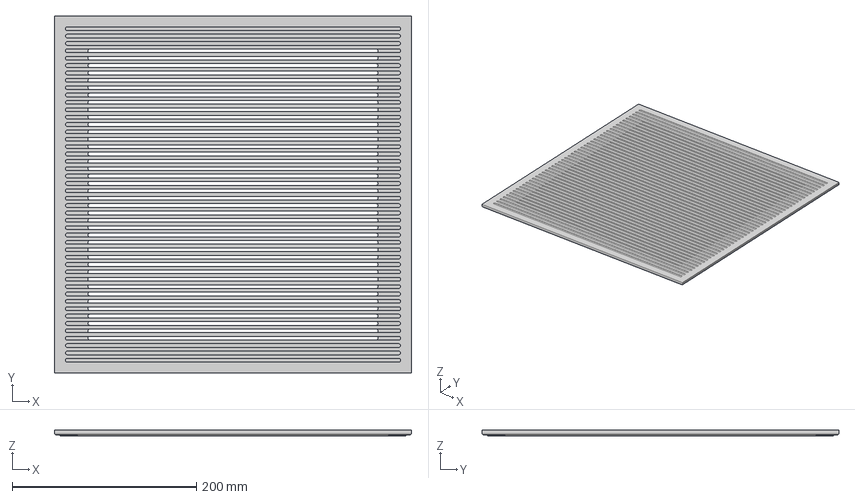
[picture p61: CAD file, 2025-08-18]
8x-5090/step_models/Part 6 - Top v1.step
387.6 x 387.6 x 6.00 mm

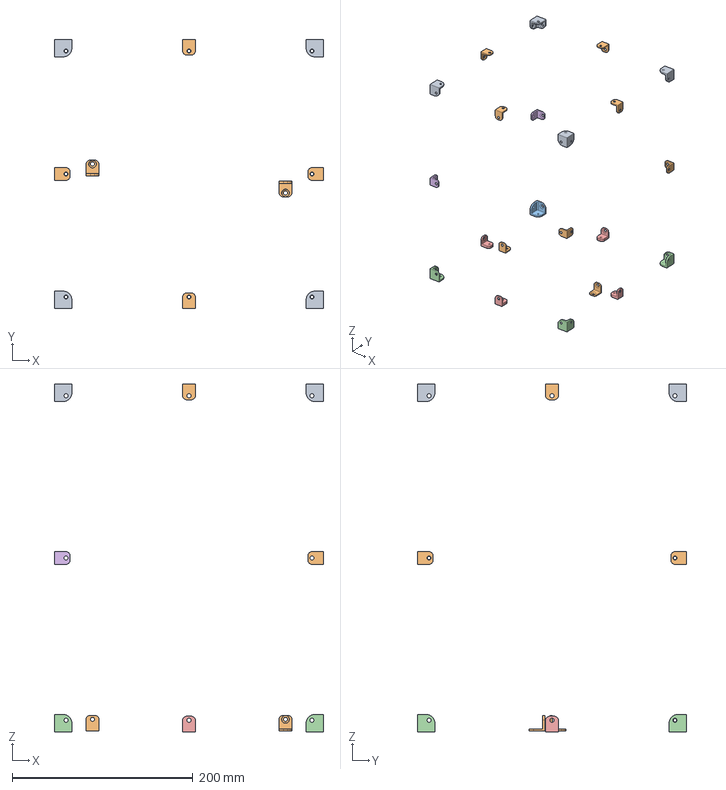
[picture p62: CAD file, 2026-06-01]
2x-5090/step_models/Support.step
298.0 x 298.0 x 385.0 mm

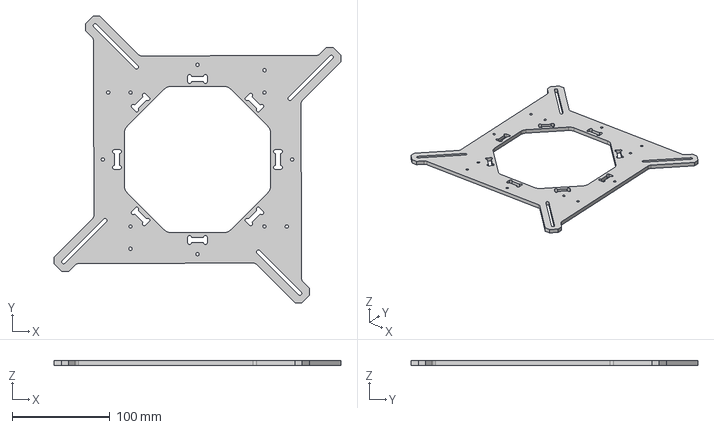
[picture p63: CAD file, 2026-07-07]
4x-5090/step_models/Part 8 - GPU Holder 2.step
294.0 x 294.0 x 5.00 mm

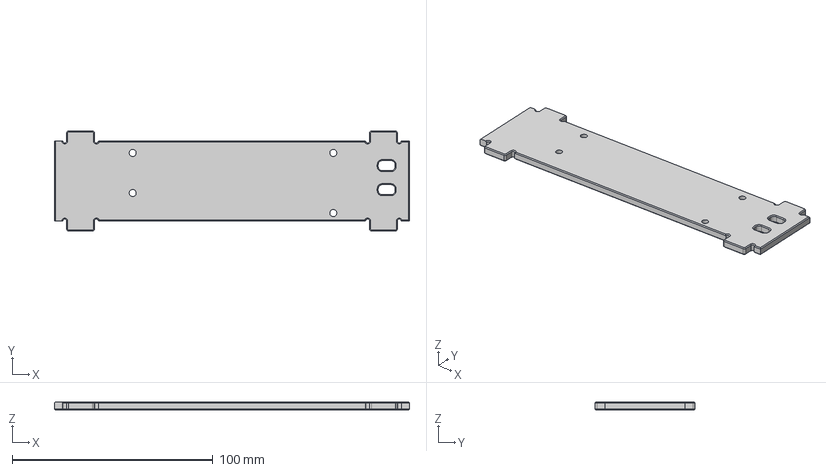
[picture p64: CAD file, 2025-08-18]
8x-5090/step_models/Part 10 - PSU mount.step
177.0 x 50.0 x 4.00 mm

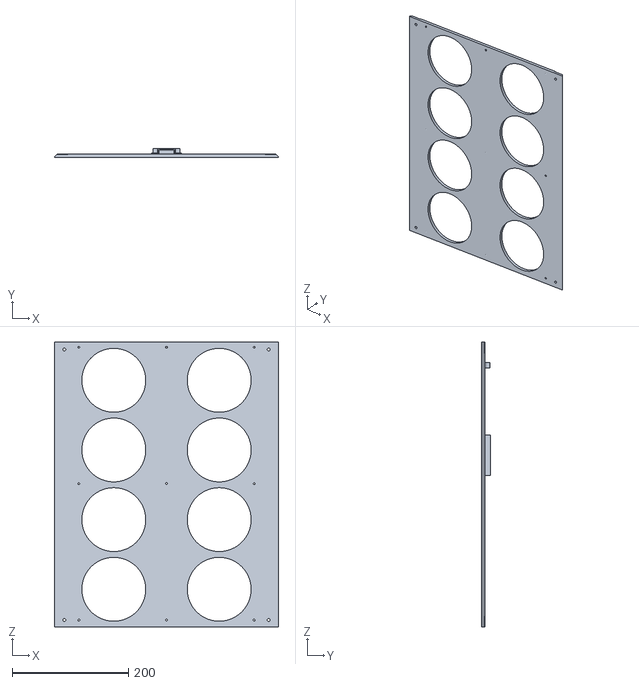
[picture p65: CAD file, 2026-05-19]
8x-5090/stl-models/Part 7 - Side.stl
386.6 x 15.0 x 491.0

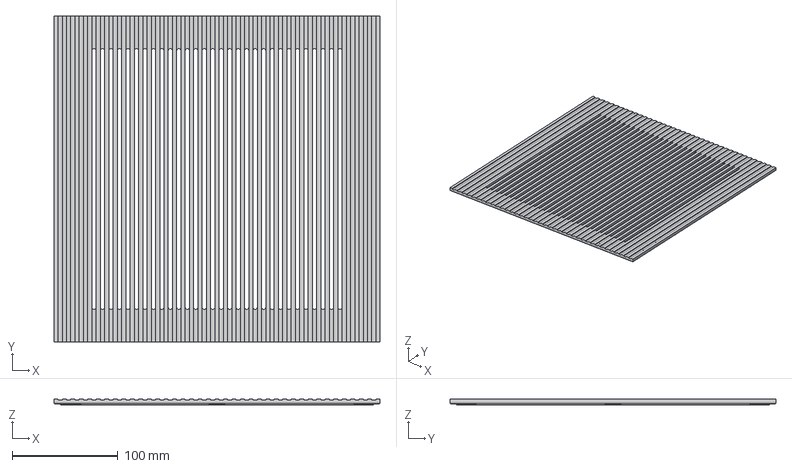
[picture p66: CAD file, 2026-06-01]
2x-5090/step_models/Part 3 - Top.step
307.6 x 307.6 x 6.00 mm

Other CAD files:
8x-5090/stl-models/Part 6 - Top.stl
4x-5090/step_models/Part 1 - Bottom.step
8x-5090/step_models/GPU mount.step
2x-5090/step_models/Part 5 - Middle.step
2x-5090/step_models/GPU mount 1.step
2x-5090/step_models/Part 4 - Bottom.step
2x-5090/stl-models/Part 1 - Side.stl
2x-5090/stl-models/Part 3 - Top.stl
2x-5090/stl-models/Part 4 - Bottom.stl
2x-5090/stl-models/Part 5 - Middle.stl
4x-5090/step_models/9 Fan mount.step
4x-5090/step_models/Corner mount.step
4x-5090/step_models/GPU mount.step
4x-5090/step_models/L mount.step
4x-5090/step_models/Part 2 - Back.step
4x-5090/step_models/Part 3 - Top.step
4x-5090/step_models/Part 4 - Middle.step
4x-5090/step_models/Part 5 - Corner 1.step
4x-5090/step_models/Part 6 - Corner 2.step
4x-5090/step_models/Part 7 - GPU Holder 1.step
4x-5090/stl-models/3 Fan mount.stl
4x-5090/stl-models/9 Fan mount.stl
4x-5090/stl-models/Corner mount.stl
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

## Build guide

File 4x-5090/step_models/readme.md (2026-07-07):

STEP files for CNC-machining the 4× housing. Printable STL versions of the same parts are in [`../stl-models`](../stl-models).

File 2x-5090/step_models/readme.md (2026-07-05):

STEP files for CNC-machining the 2× housing. Printable STL versions of the same parts are in [`../stl-models`](../stl-models).

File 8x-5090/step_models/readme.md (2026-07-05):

STEP files for CNC-machining the 8× housing. [`all-step-files.zip`](all-step-files.zip) contains every part plus the full assembled model (`Edge AI - 8 GPU.step`, 123 MB — too large to publish as a loose file on GitHub). Printable STL versions are in [`../stl-models`](../stl-models).

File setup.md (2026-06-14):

# Setup

Getting the machine ready: BIOS tuning for multi-GPU, NVIDIA drivers, and your OS. Exact BIOS menu paths vary by motherboard — check your build's `docs/` and board manual for specifics.

## BIOS optimization for GPU performance

> The default BIOS settings rarely deliver full performance for multi-GPU workloads. Adjust these:

- **PCIe settings** — *Important.* Set all GPU slots to the highest supported speed (Gen4/Gen5) and configure bifurcation for your GPUs.
  ```
  Advanced -> Chipset Configuration -> PCIE link width -> set the MCIO pairs feeding the GPUs to x16
  ```
- **Above 4G Decoding** — *Important.* Enable so the platform can map the GPUs' large memory.
  ```
  Advanced -> PCI Subsystems Settings -> Enable Above 4G Decoding   (often on by default)
  ```
- **Resizable BAR** — *Important.* Enable for faster CPU↔GPU transfer.
  ```
  Advanced -> PCI Subsystems Settings -> Enable Re-size BAR support
  ```
- **Power management** — *Optional.* Disable power-saving features (C-states, ASPM) that can throttle GPUs.
- **Memory** — *Optional.* Run RAM at rated speed (enable XMP/EXPO) for max bandwidth.
- **Fans & thermals** — *Optional.* Set fan curves and thermal limits for sustained GPU load.

Save, reboot, and confirm stability.

## NVIDIA drivers + OS

- Install Linux (Ubuntu LTS is a safe default) or your OS of choice.
- Install the current NVIDIA driver and CUDA toolkit for your cards.
- Confirm the OS sees every GPU before going further — see [Testing](testing.md).

## Board manuals

Each build ships its motherboard and BMC manuals in its `docs/` folder. Use them for the exact menu locations on your board.

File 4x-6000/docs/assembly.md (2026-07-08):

# Assembly

Order of assembly for one 5U server — the TURIN2D24G-2L+ board, one EPYC 9124, and four RTX PRO 6000 GPUs in the ASRock 5U chassis. Step photos are added as the build is documented.

| Step | Description |
|:----:|:---|
|  1 | Prepare all components — the [bill of materials](../bom/bom.md) and the [housing prep](prepare-me.md). |
|  2 | Install the CPU into the SP5 socket on the TURIN2D24G-2L+ motherboard. |
|  3 | Mount the COOLSERVER 2U SP5 S22 heatsink onto the CPU. |
|  4 | Populate the 8 DDR5 ECC RDIMMs (48 GB each, 384 GB total), following the board's DIMM population order. |
|  5 | Install the Samsung 990 EVO Plus NVMe SSD into the M.2 slot. |
|  6 | Seat the motherboard in the 5U chassis and secure it with the standoffs and screws. |
|  7 | Install the three CRPS PSUs and connect them to the power board. |
|  8 | Route the motherboard and peripheral power cables from the power board. |
|  9 | Install the four NVIDIA RTX PRO 6000 Blackwell GPUs and secure them to the support rail. |
|  10  | Connect the GPU power cables and verify the retention clips. |
|  11  | Connect the MCIO cables between the motherboard and the GPU PCIe risers. |
|  12  | Connect the chassis fans to the fan board and verify the PWM headers. |
|  13  | Close the chassis, connect the AC inlet, and perform first-boot. |

---

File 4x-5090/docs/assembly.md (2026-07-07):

# Assembly

The 4× has its own cube housing — print the [STLs](../stl-models) or CNC the [STEPs](../step_models) — built around four GPUs on a Threadripper PRO board. Step photos are added as the build is documented.

| Step | Description |
|:----:|:---|
|  1 | Prepare the housing parts. |
|  2 | Attach the first side to the base. |
|  3 | Attach the other side to the base. |
|  4 | Attach the top to the housing. |
|  5 | Attach the brass hex standoffs to the back side. |
|  6 | Mount the four PCIe risers to the mount plate. |
|  7 | Attach the fan plate to the mount. |
|  8 | Mount the fans to the fan plate. |
|  9 | Place the motherboard on the mount. |
|  10  | Screw the motherboard down to the mount. |
|  11  | Connect the four PCIe risers to the motherboard. |
|  12  | Seat the four GPUs in the riser slots. |
|  13  | Screw the GPUs down to the mount. |
|  14  | Attach the PSU to the base. |
|  15  | Connect the cables on the PSU side. |
|  16  | Connect the ATX cable to the motherboard. |
|  17  | Connect the EPS / CPU power connectors to the motherboard. |
|  18  | Connect the CPU fan to the motherboard. |
|  19  | Connect the 12VHPWR power cables to the four GPUs. |
|  20  | All electronics installed. |
|  21  | Attach one side panel of the housing. |
|  22  | Attach the other side panel. |
|  23  | Fit the final panel — done. |

---

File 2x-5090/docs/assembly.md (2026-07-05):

| Step | Description | Image |
|---|---|---|
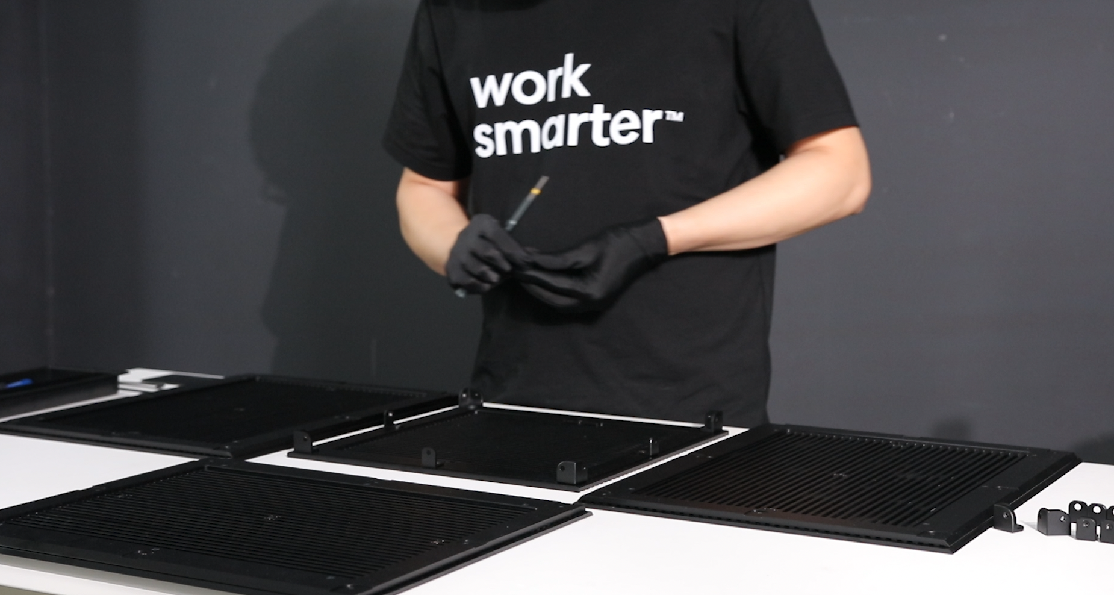
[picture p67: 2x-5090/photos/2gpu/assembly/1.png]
| 1 | Prepare the housing parts. |  |
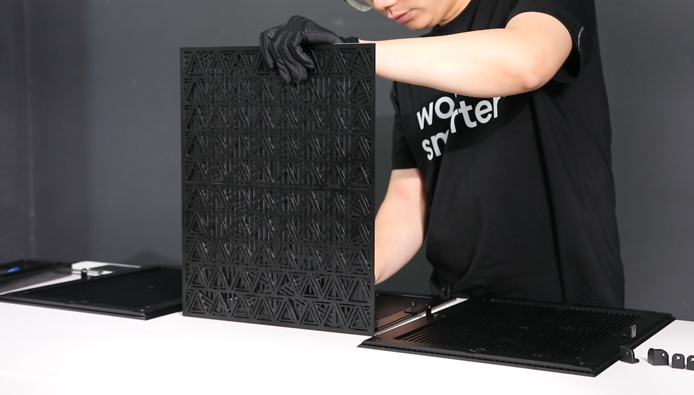
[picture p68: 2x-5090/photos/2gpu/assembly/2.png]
| 2 | Attach the first side to the base. |  |
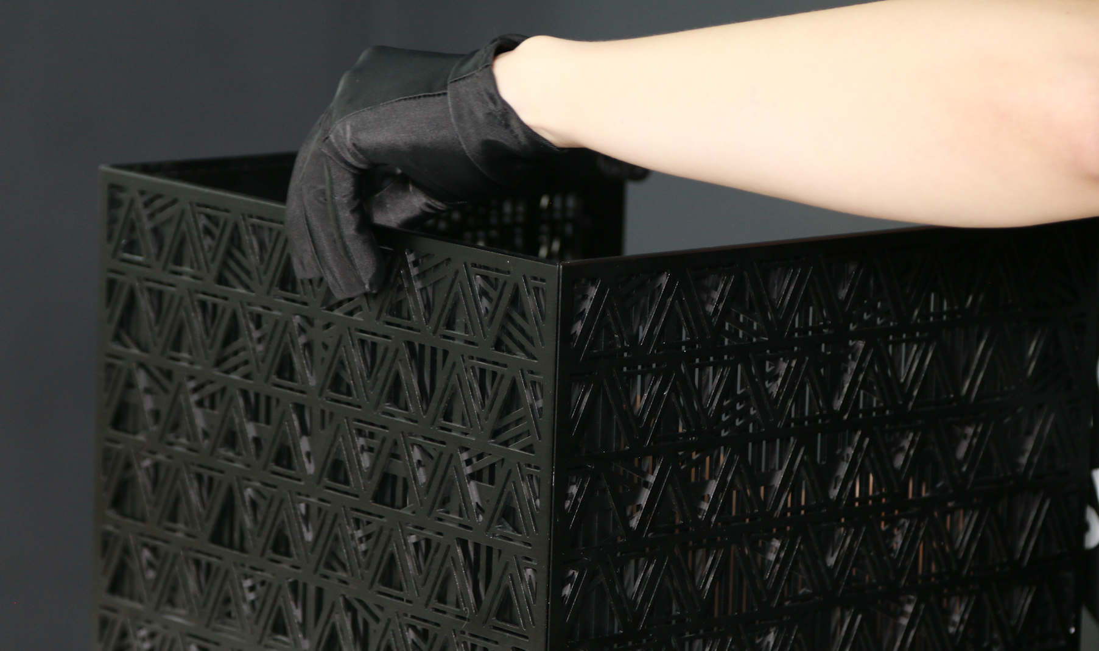
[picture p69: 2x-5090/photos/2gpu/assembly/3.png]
| 3 | Attach the other side to the base. |  |
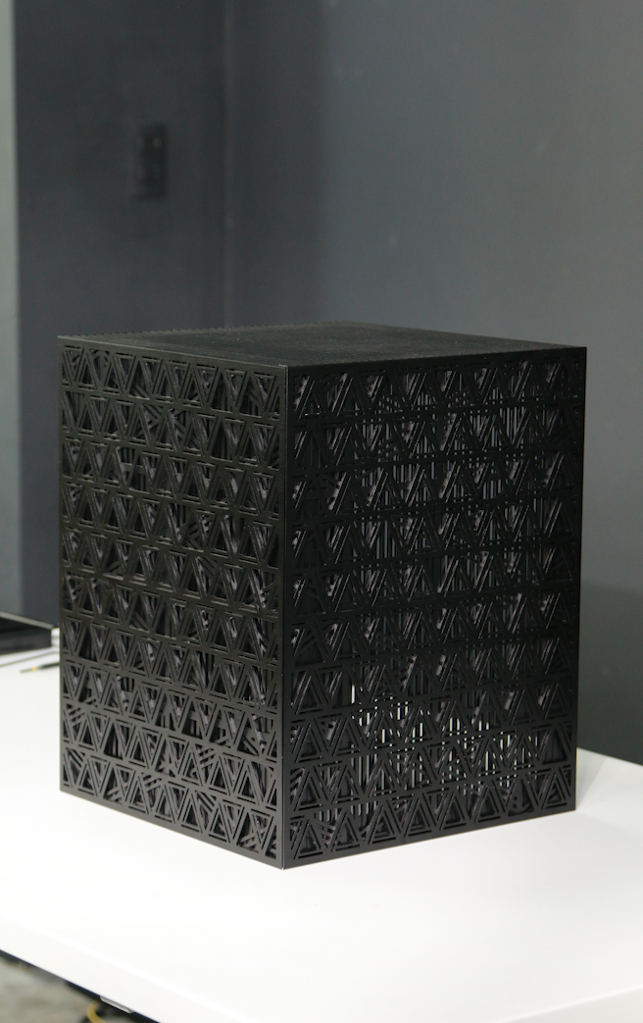
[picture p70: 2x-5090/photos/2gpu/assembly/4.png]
| 4 | Attach the top to the housing. |  |
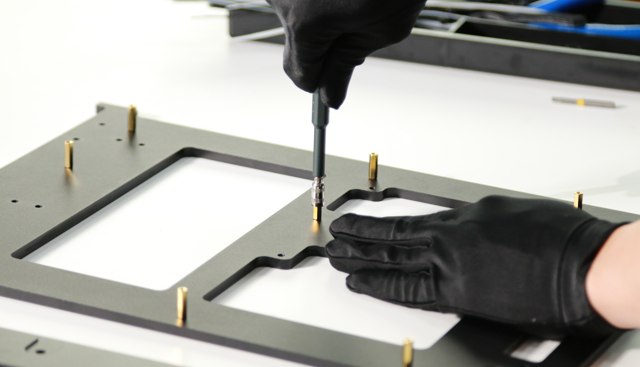
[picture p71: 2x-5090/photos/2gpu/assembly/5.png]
| 5 | Attach the brass hex standoffs to the back side. |  |
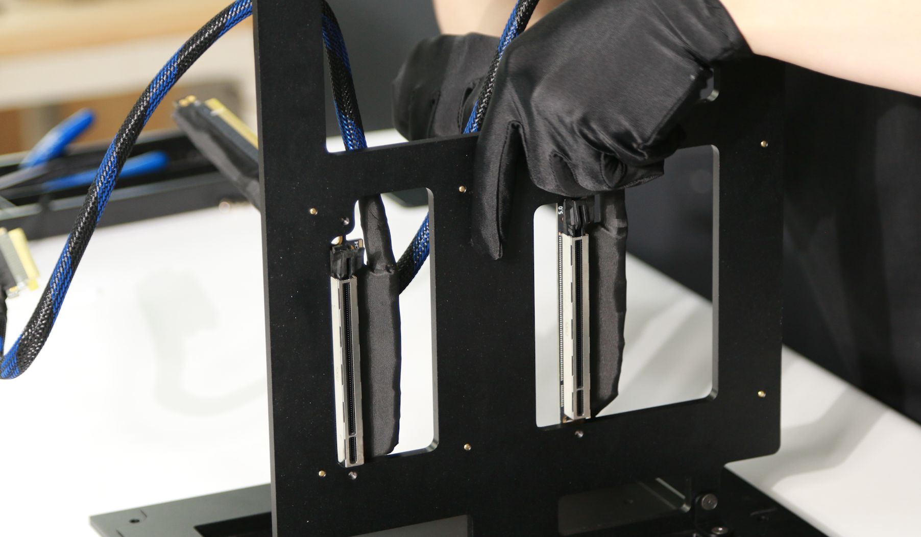
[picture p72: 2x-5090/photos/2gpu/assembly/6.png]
| 6 | Mount the PCIe risers to the mount plate. |  |
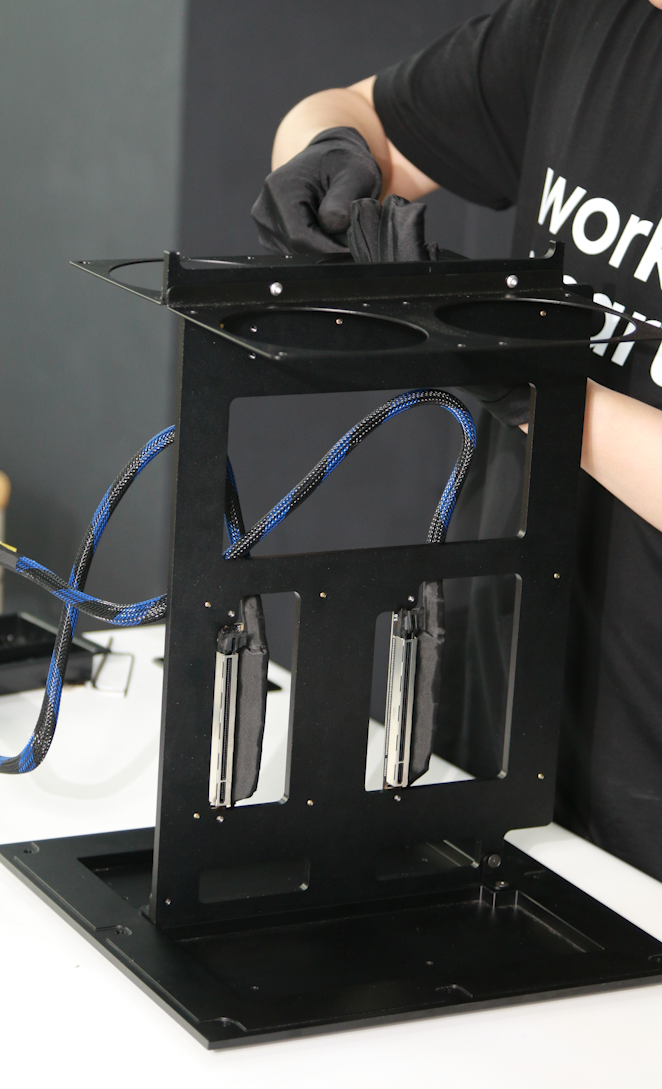
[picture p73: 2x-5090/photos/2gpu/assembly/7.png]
| 7 | Attach the fan plate to the mount. |  |
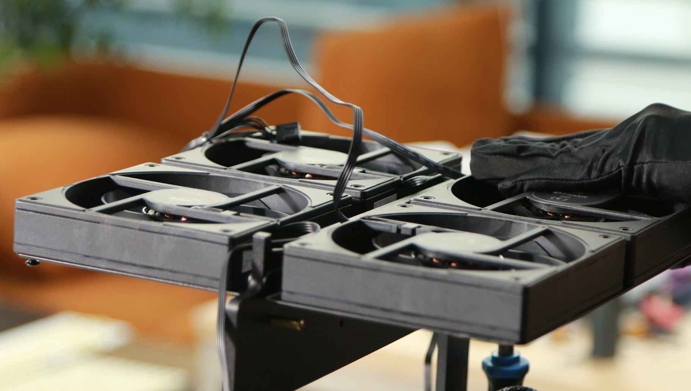
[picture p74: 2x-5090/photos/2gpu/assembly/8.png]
| 8 | Mount the fans to the fan plate. |  |
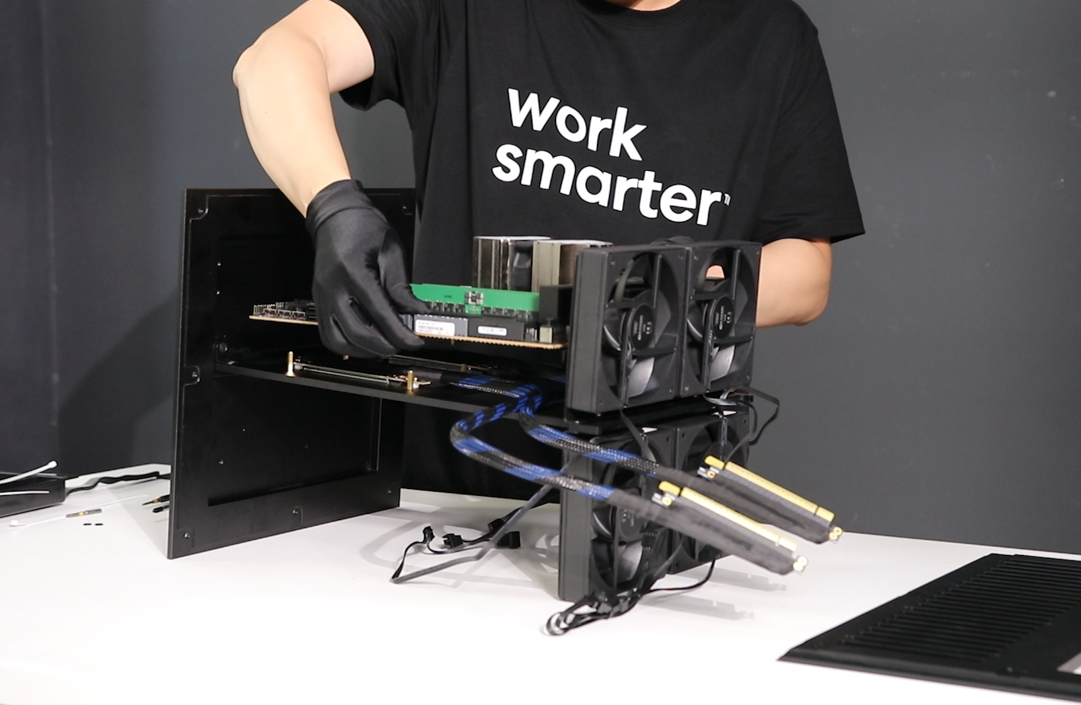
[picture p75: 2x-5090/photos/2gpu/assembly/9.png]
| 9 | Place the motherboard on the mount. |  |
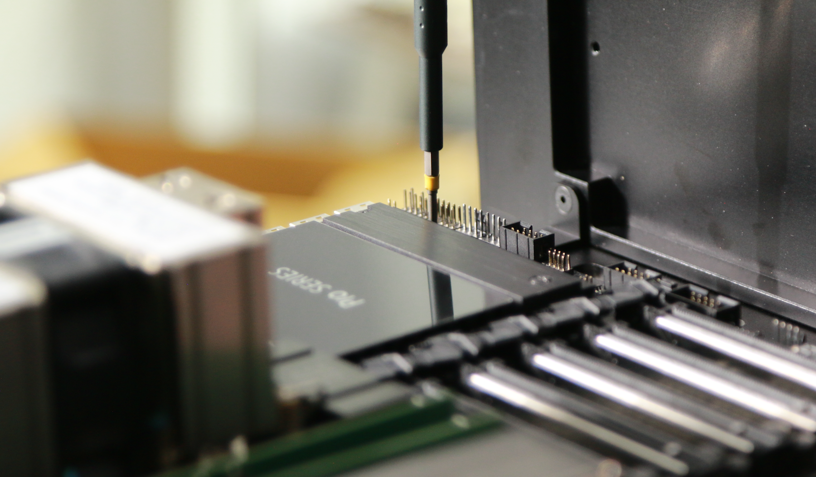
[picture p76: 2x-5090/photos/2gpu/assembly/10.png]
| 10 | Screw the motherboard down to the mount. |  |
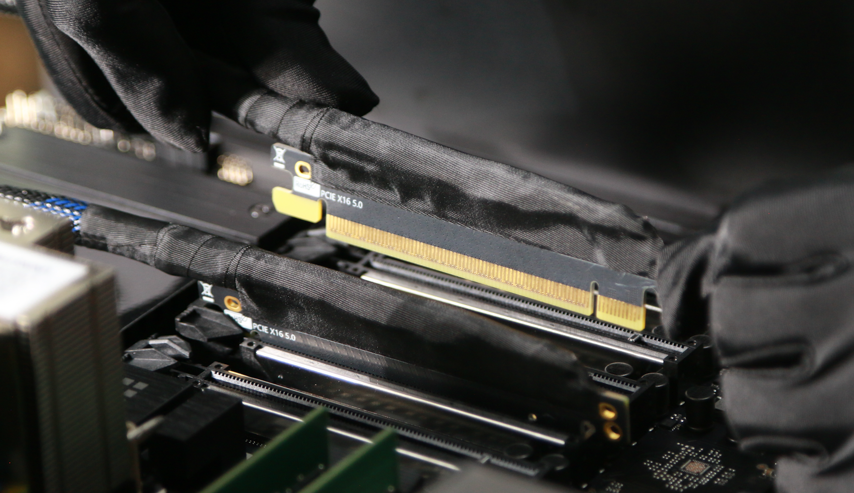
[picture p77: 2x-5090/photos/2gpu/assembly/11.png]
| 11 | Connect the PCIe risers to the motherboard. |  |
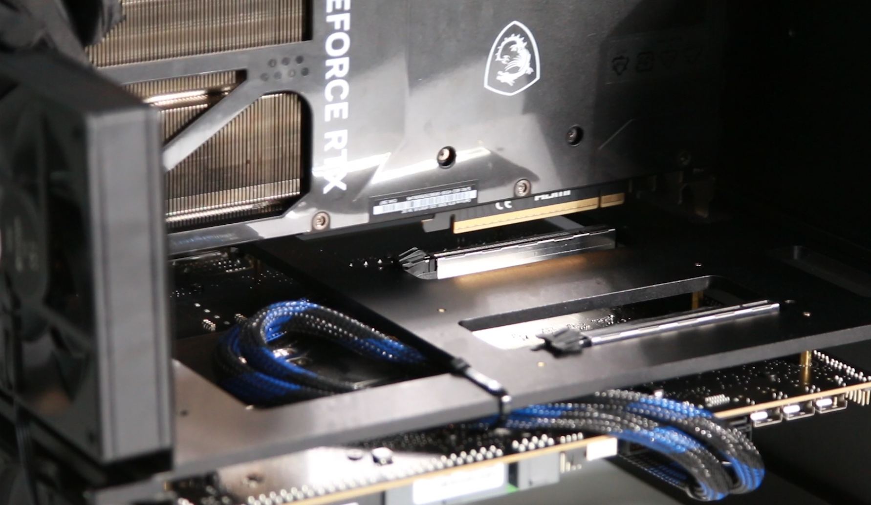
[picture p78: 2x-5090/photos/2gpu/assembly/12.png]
| 12 | Seat the GPUs in the riser slots. |  |
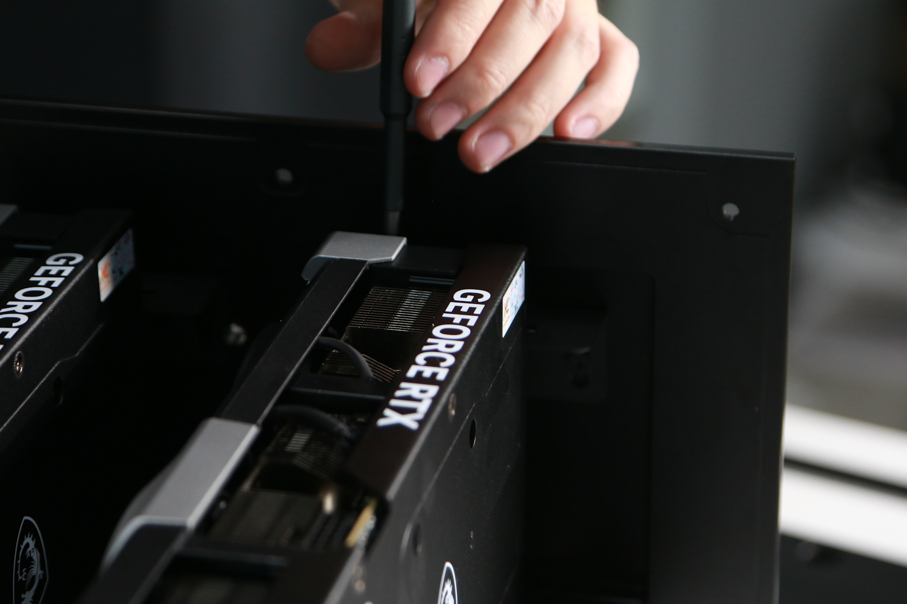
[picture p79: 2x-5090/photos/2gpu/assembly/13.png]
| 13 | Screw the GPUs down to the mount. |  |
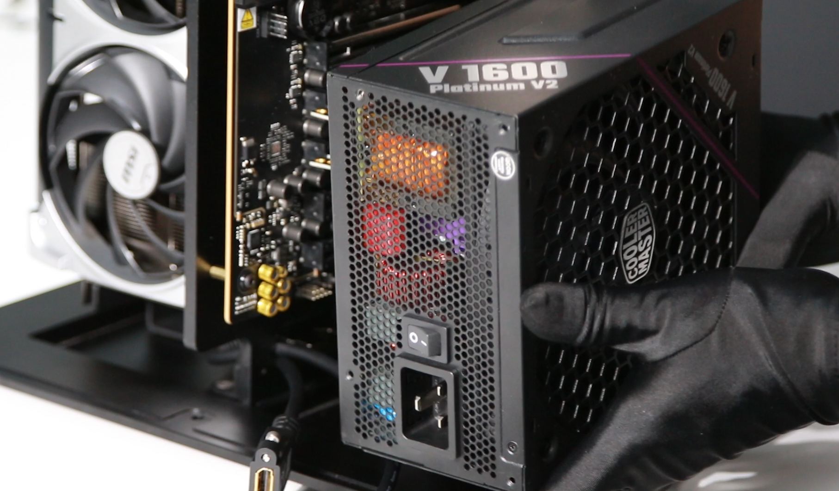
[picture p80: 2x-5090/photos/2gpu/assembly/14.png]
| 14 | Attach the PSU to the base. |  |
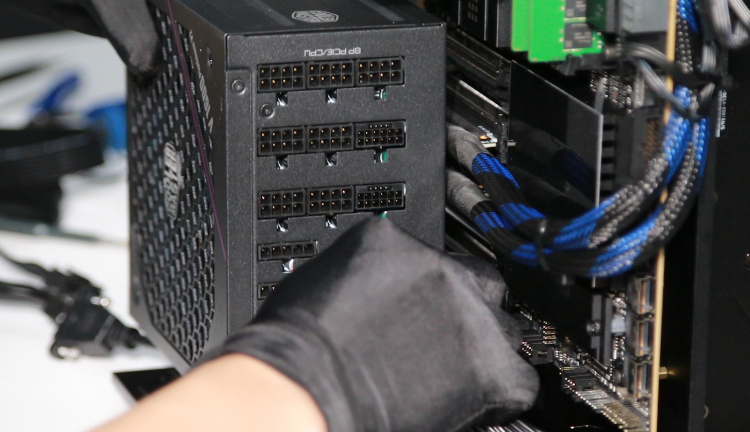
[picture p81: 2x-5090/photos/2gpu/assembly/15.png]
| 15 | Connect the cables on the PSU side. |  |
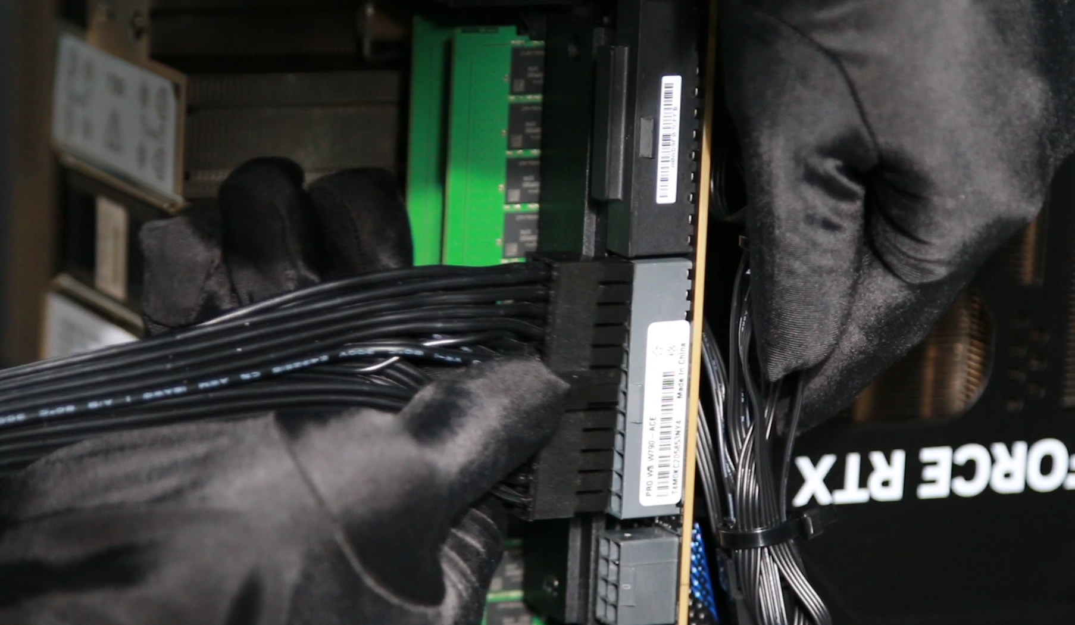
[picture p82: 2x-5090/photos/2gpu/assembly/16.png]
| 16 | Connect the ATX cable to the motherboard. |  |
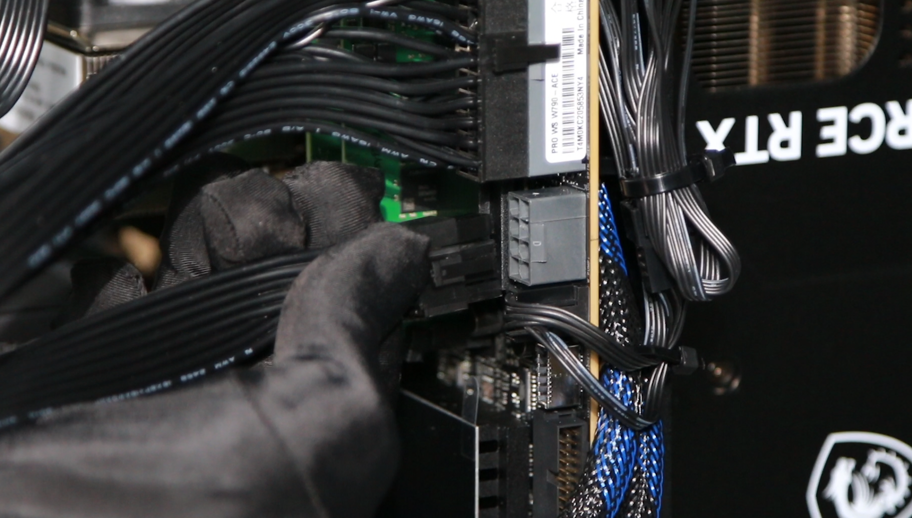
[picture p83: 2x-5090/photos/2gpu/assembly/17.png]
| 17 | Connect the 8-pin connector to the motherboard. |  |
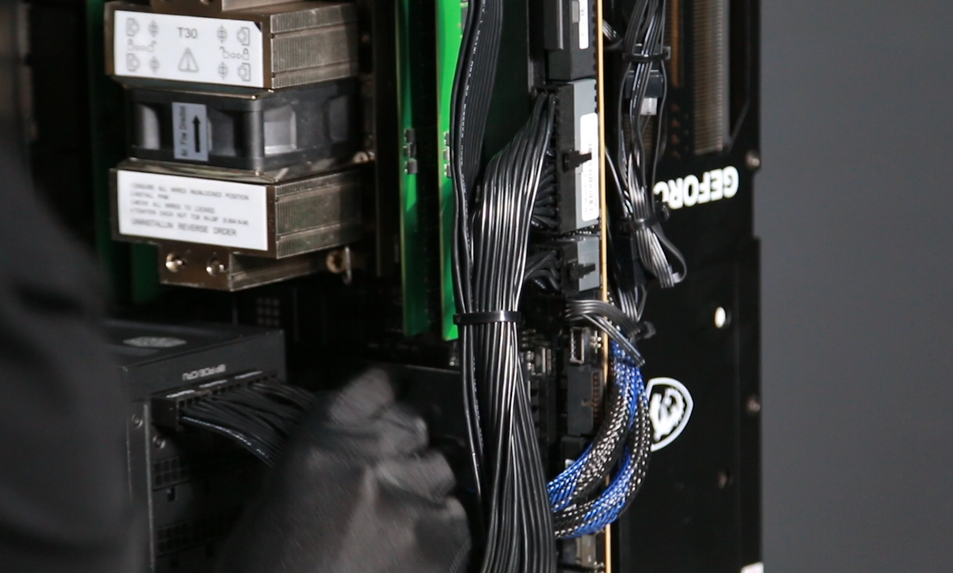
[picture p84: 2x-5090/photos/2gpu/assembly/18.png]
| 18 | Connect the CPU fan to the motherboard. |  |
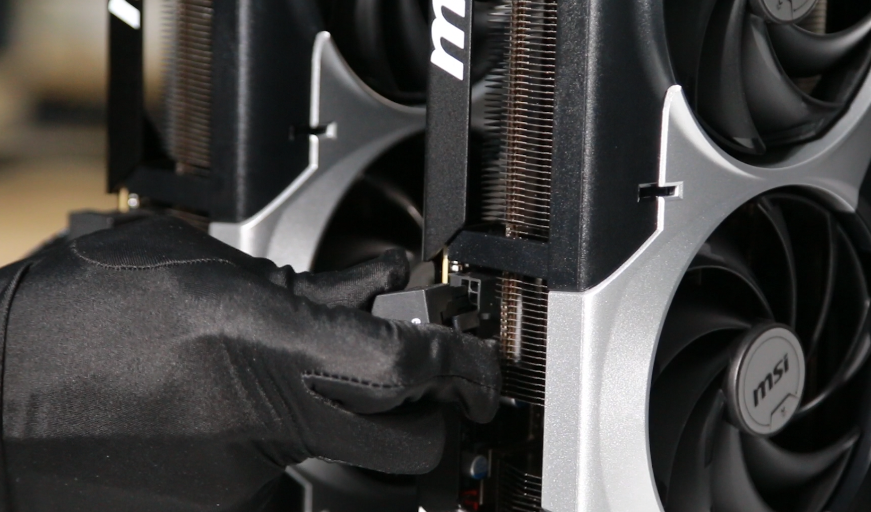
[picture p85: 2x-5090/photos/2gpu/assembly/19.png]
| 19 | Connect the 12-pin power cables to the GPUs. |  |
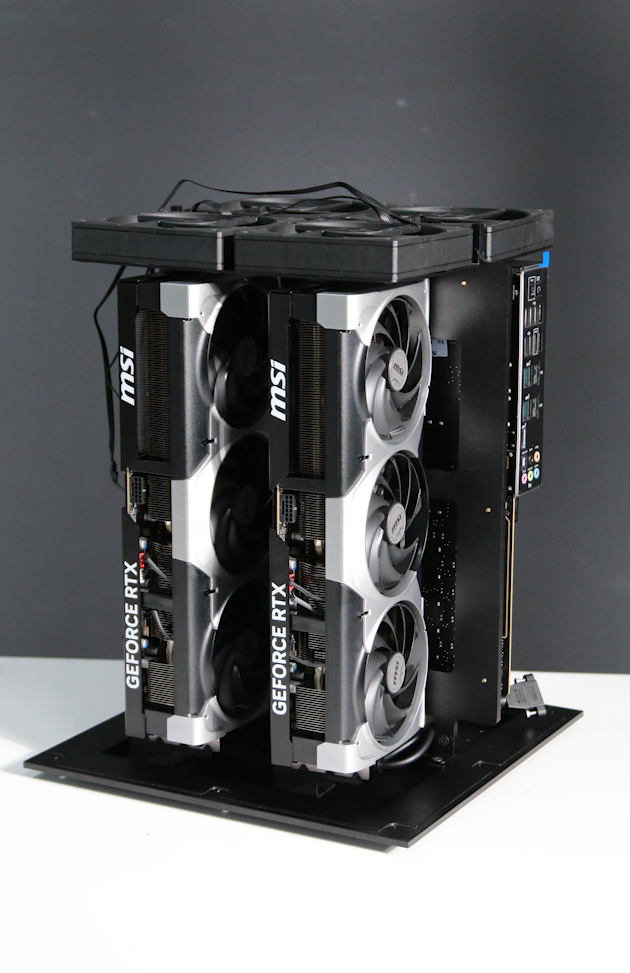
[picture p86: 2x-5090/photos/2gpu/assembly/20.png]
| 20 | All electronics installed. |  |
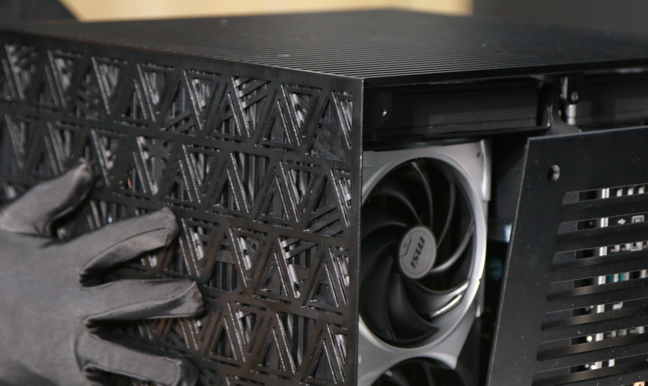
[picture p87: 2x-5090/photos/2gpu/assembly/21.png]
| 21 | Attach one side panel of the housing. |  |
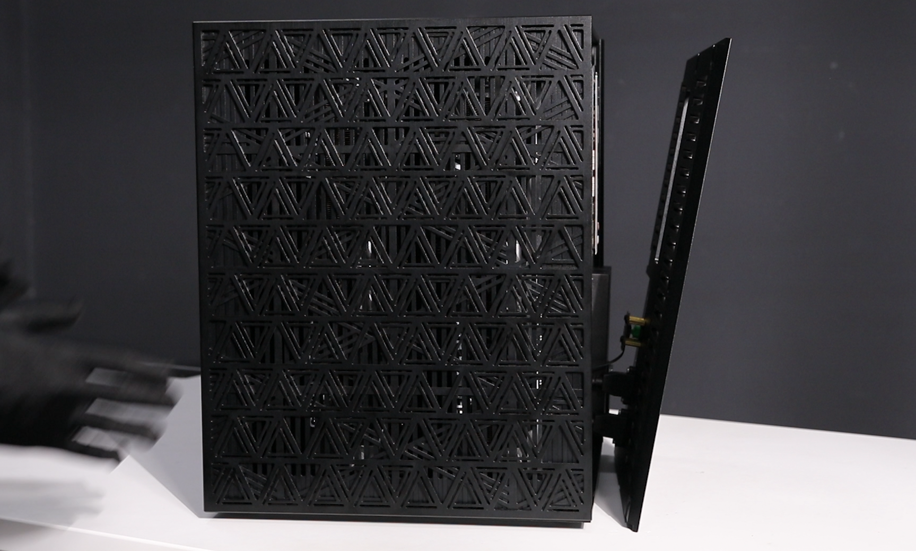
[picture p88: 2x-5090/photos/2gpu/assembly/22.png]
| 22 | Attach the other side panel. |  |
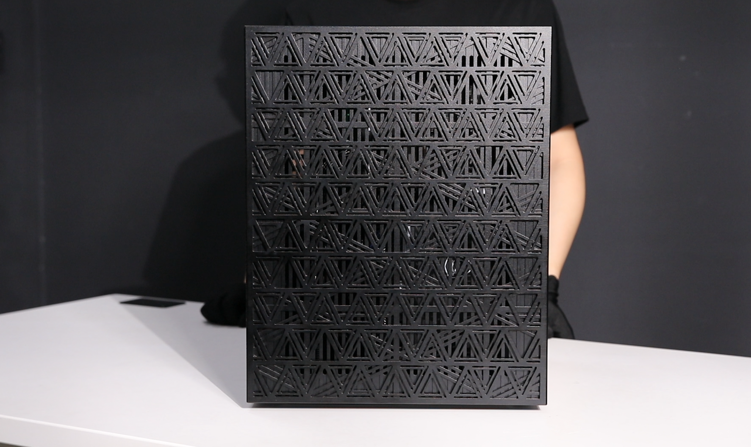
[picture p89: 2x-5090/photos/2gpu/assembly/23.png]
| 23 | Fit the final panel — done. |  |

---

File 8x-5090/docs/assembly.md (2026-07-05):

| Step | Description | Image |
|---|---|---|
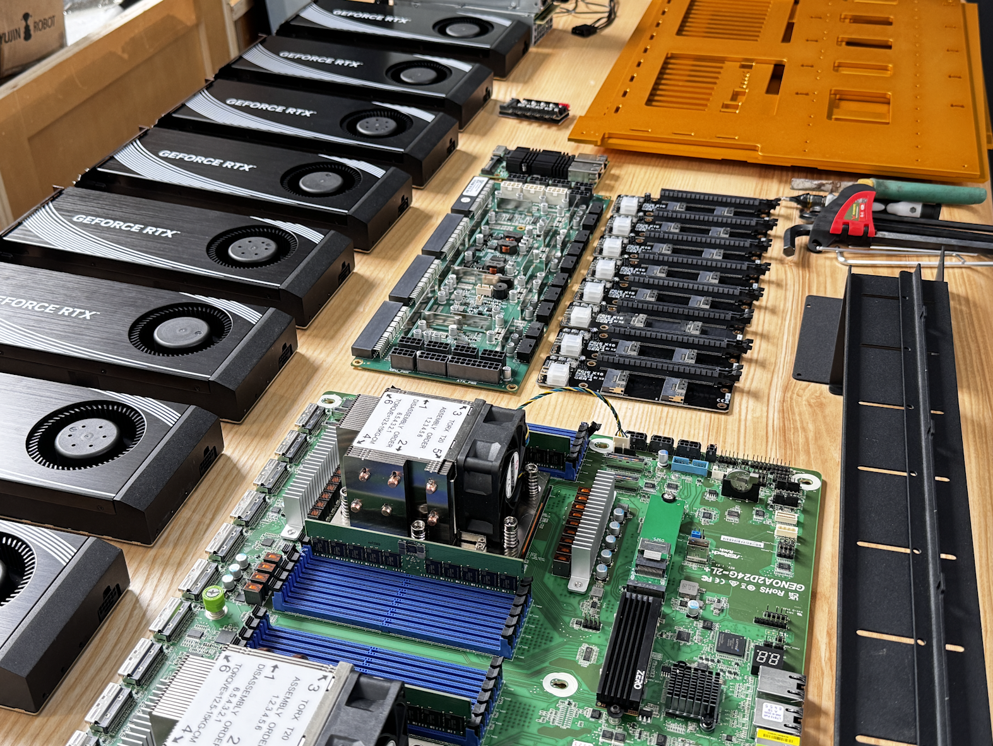
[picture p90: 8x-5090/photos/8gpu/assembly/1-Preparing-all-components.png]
| 1 | Prepare all components. |  |
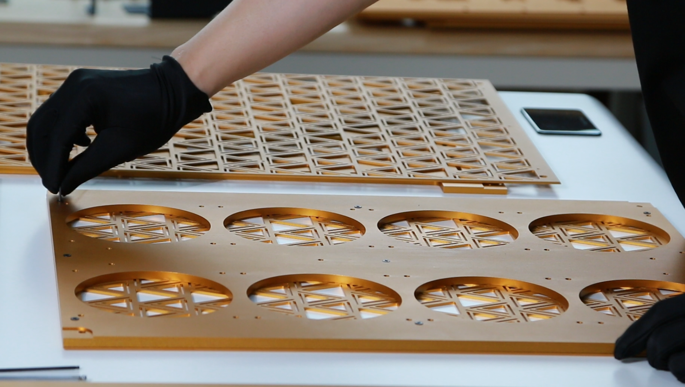
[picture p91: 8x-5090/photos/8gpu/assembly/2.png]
| 2 | Assemble “Part 7 – Side” and “Part 8 – Side Cover” together. Repeat for the other side. |  |
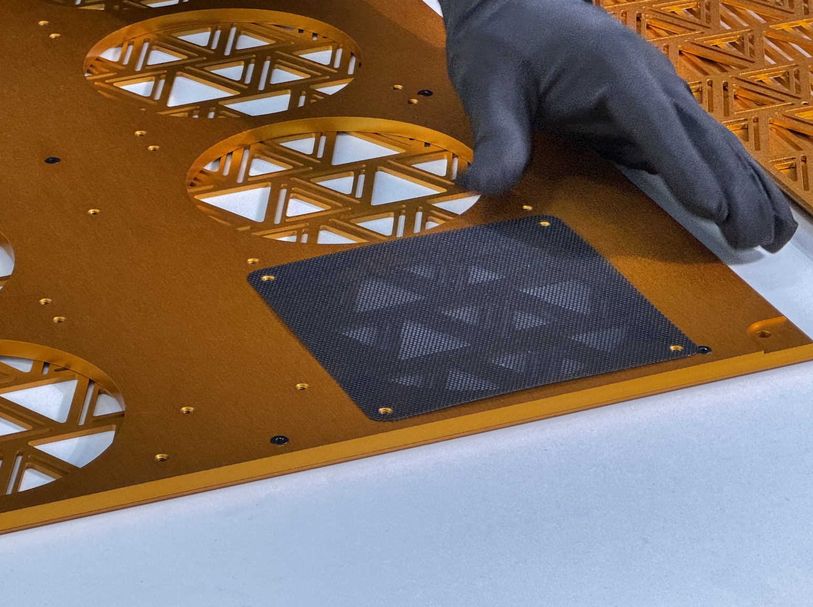
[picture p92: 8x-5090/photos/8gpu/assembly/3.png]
| 3 | Install the dust filter. |  |
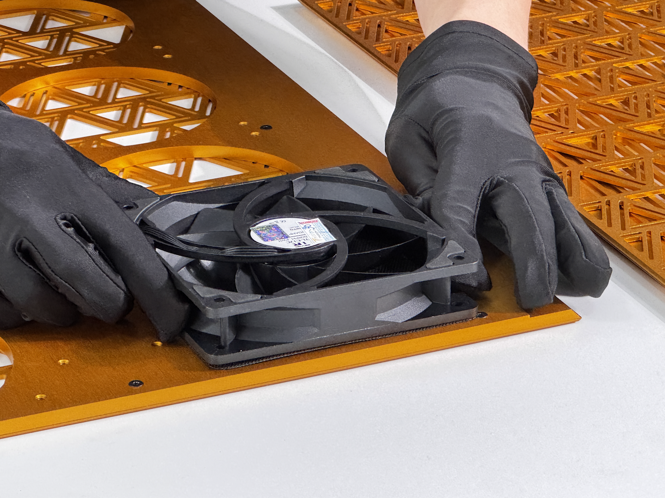
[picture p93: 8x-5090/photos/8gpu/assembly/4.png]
| 4 | Assemble the 120 mm × 120 mm fan. |  |
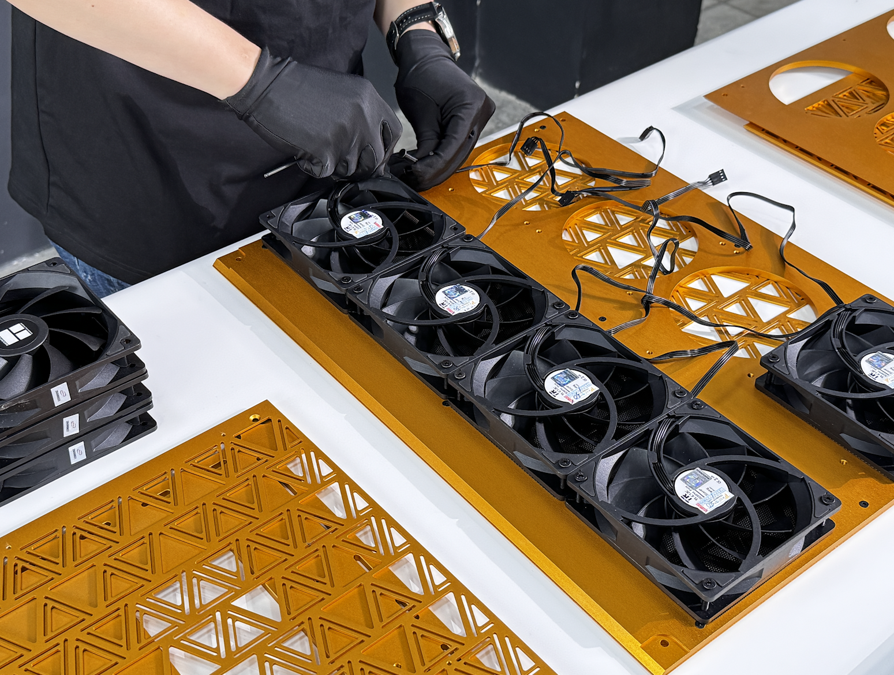
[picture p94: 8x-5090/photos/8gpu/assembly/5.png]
| 5 | Install the remaining fans. |  |
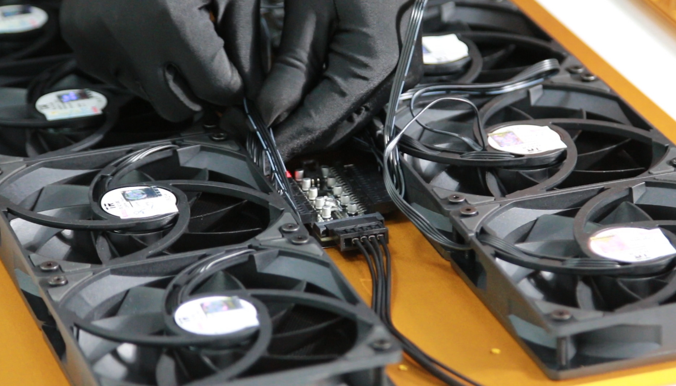
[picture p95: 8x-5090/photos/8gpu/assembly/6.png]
| 6 | Connect all fans to the control board. |  |
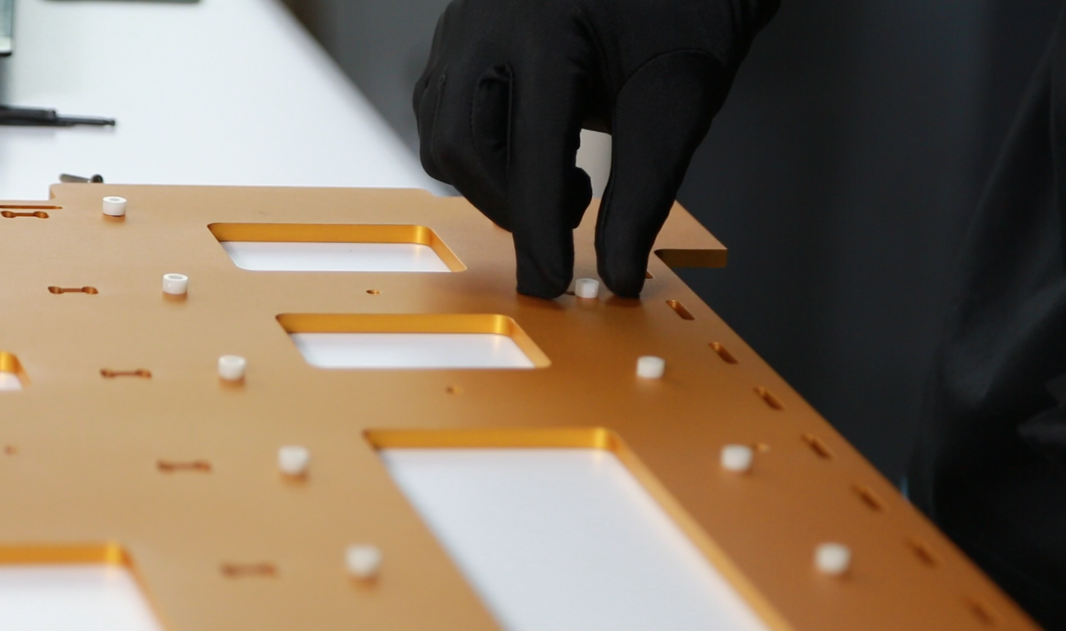
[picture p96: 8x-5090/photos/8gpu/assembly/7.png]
| 7 | Place plastic spacers in position on “Part 2 – CPU Plate”. |  |
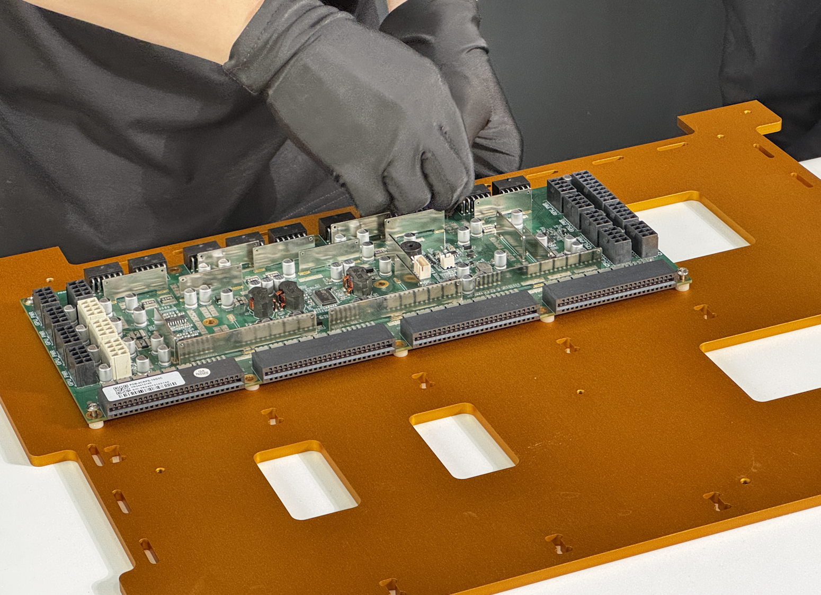
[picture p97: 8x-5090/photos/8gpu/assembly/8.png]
| 8 | Fix the PSU board to “Part 2 – CPU Plate”. |  |
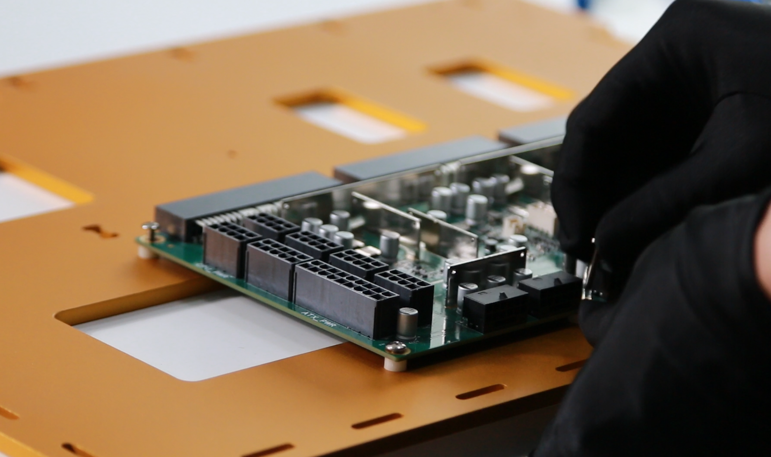
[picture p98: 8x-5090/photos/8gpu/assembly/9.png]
| 9 | Insert all screws, but do not tighten them yet. |  |
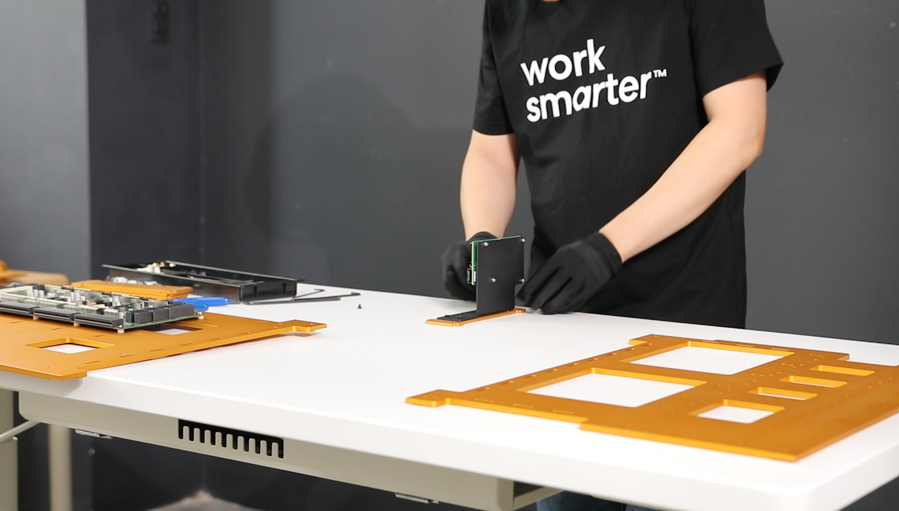
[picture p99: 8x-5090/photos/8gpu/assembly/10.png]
| 10 | Assemble the Ethernet board into “Part 10 – PSU Mount”. |  |
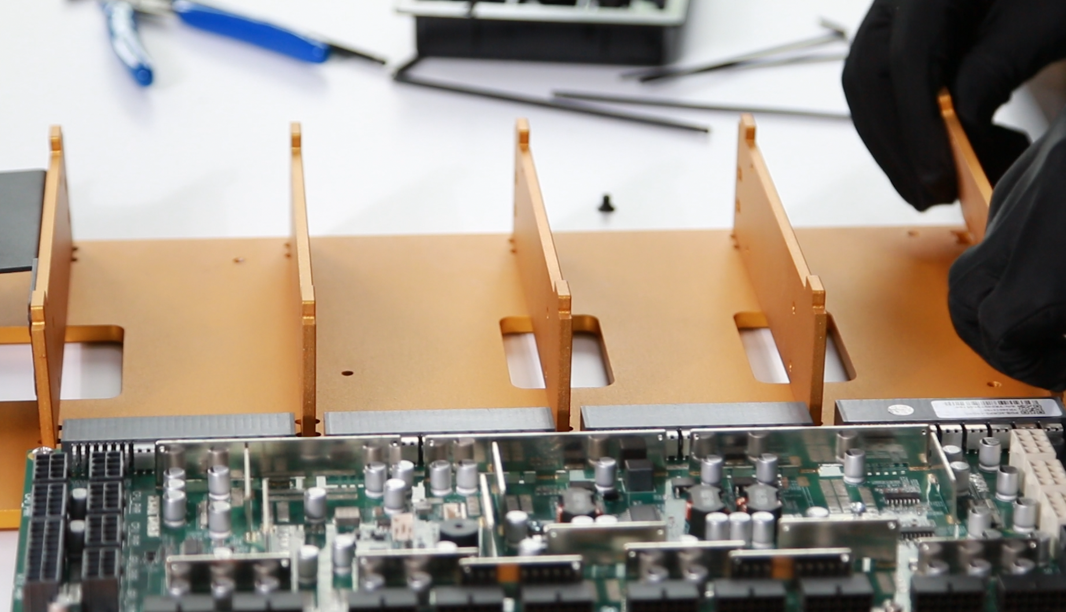
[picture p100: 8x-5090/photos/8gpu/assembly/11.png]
| 11 | Place “Part 10 – PSU Mount” into position. |  |
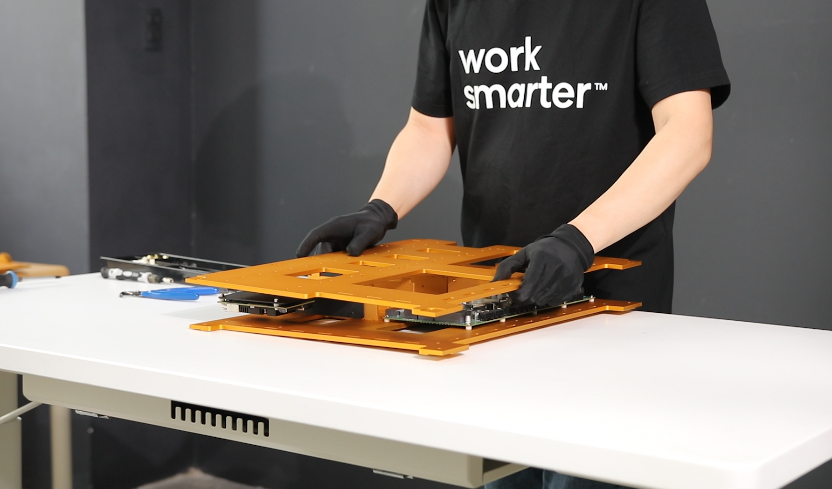
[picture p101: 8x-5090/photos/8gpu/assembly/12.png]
| 12 | Place “Part 1 – GPU Plate” on top. |  |
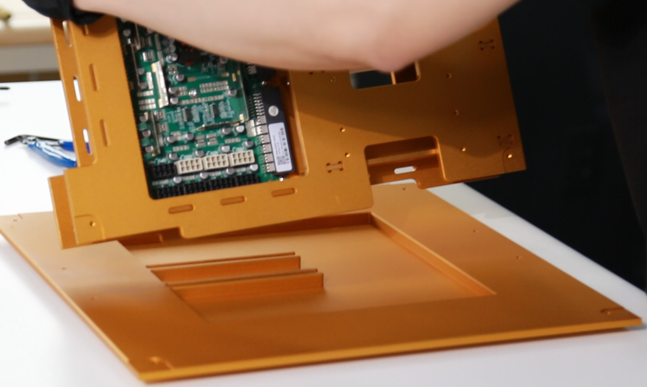
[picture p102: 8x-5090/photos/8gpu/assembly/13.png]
| 13 | Place all middle parts onto “Part 5 – Bottom”. |  |
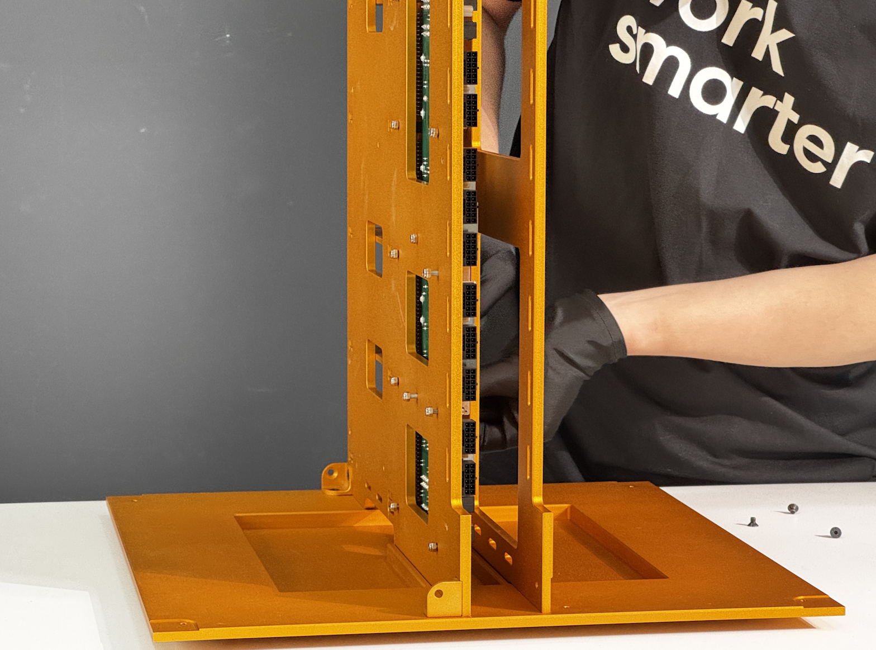
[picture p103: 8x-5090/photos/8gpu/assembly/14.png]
| 14 | Place all support mounts into position. |  |
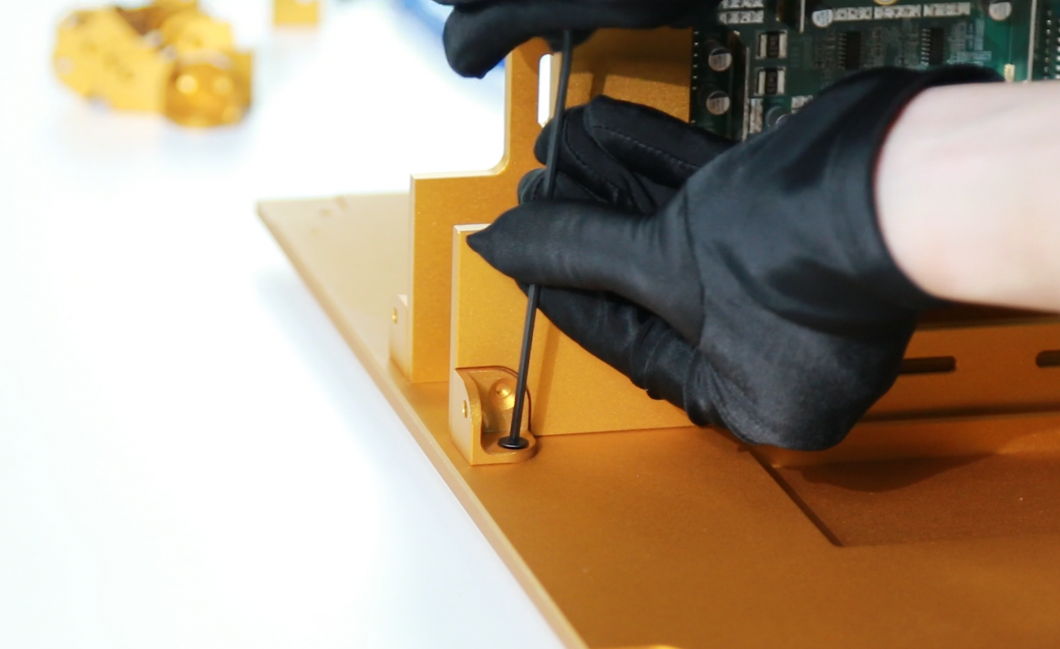
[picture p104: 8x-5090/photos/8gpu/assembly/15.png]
| 15 | Secure with M4 × 8 mm screws. |  |
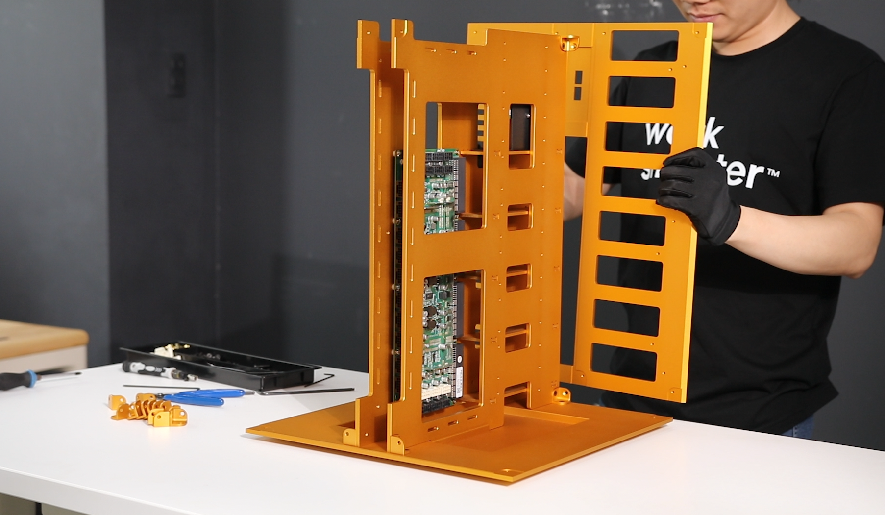
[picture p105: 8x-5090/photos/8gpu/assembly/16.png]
| 16 | Place “Part 4 – Back” into position and secure it with M4 screws. |  |
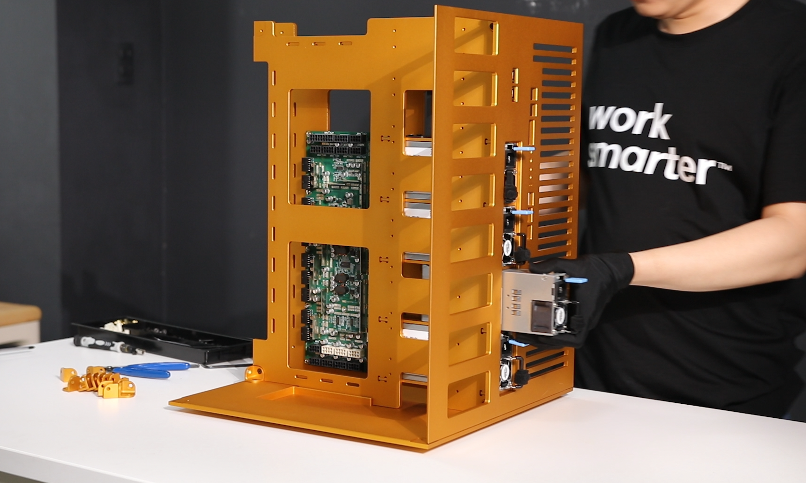
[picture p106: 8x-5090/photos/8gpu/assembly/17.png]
| 17 | Install all four PSUs into position and connect them to the PSU board. |  |
| 18 | Tighten all screws on the PSU board. |  |
| 19 | Install M4 × 15 mm copper spacers into the M4 holes on the other side. |  |
| 20 | Place the “Motherboard GENOA2D24G-2L+” into position. |  |
| 21 | Secure the motherboard to “Part 2 – CPU Plate” using M3 screws. |  |
| 22 | Place 20 mm plastic spacers under the PCI board and secure them with M4 screws. |  |
| 23 | Install the remaining components. |  |
| 24 | The MCIO→PCIe x16 adapters seated on their standoffs — one per GPU slot. |  |
| 25 | The frame with all eight PCIe adapters installed, seen from the front. |  |
| 26 | Place the assembled parts upright. |  |
| 27 | Connect the PCI board cable to the motherboard. |  |
| 28 | Use zip ties to organize cables. |  |
| 29 | Connect the power cable to the motherboard. |  |
| 30 | Connect MCIO cable to MCIO adapter |  |
| 31 | Place “Part 6 – Top” into position and secure it with M4 screws and the support plate. |  |
| 32 | Install 8 GPUs. |  |
| 33 | Secure the GPUs to the support rail. |  |
| 34 | Organize the power supply cables. |  |
| 35 | Connect the power supply cables. |  |
| 36 | Connect the fan board cable, then place the fan board into position. |  |
| 37 | Secure “Part 7 – Side”. |  |
| 38 | Repeat for the other side. |  |
| 39 | Connect the main power supply. |  |

---

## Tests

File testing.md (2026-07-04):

# Testing

Verify the hardware before you rely on it. Confirm every GPU is detected, linked at full PCIe width, and stable under load.

## Quick verification

- **Fast hardware check:** boot **WinPE from USB** to confirm all cards enumerate, or
- **Linux check:** install Linux + NVIDIA drivers, then:
  ```bash
  nvidia-smi      # every GPU listed, correct VRAM, expected power/temp
  nvtop           # live per-GPU utilization and memory
  ```

Confirm:
- [ ] All GPUs appear in `nvidia-smi` (count matches your build: 2 / 4 / 8).
- [ ] Each card reports its full VRAM.
- [ ] PCIe link width/speed is what you set in BIOS (no cards dropped to x1/x4).
- [ ] Temperatures and power draw are sane at idle and under load.

Once confirmed, install your working OS and put the box to work — [**Grid**](https://github.com/autonomous-ai/autonomous-grid) serves your models behind one endpoint.

## Reference

Per-build testing screenshots live in each build's `photos/.../testing/`.

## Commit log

2026-06-01 Add 2x-rtx5090 and 4x-rtx-pro-6000 build guides, update root README
    Moves private-autonomous-2x5090 and private-4xRTX-PRO-6000 from the
    migrate/ staging folder into top-level directories with clean kebab-case
    names. Adds an Other Builds table to the root README linking all three
    configurations.
    [GPU mount 1.step, GPU mount 2.step, Part 1 - Side.step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]
2026-06-01 Fix all repo links to point to autonomous-ai/autonomous-computer
    Replaces old AutonomousOfficial/8xGPUs and autonomous-AI-lab/2xGPUs
    references with the current repo. Converts absolute GitHub file links
    to relative paths.
2026-06-01 Lowercase root folder names, fix README paths and video playback
    Renames BOM→bom, Docs→docs, Photos→photos (and nested 8GPU, Assembly,
    Introduction, Preparing, EE, Testing), Step_Models→step_models,
    stl-Models→stl-models. Updates all README.md image and doc paths.
    Adds controls and width attributes to video tags so they are playable.
    [Ethernet mount.step, Ethernet mount.stl, GPU mount.step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]
2026-06-01 Restore animated SVG banners, remove dead video attachment URLs
2026-06-14 Restructure into Personal AI Computer configs (2x/4x/8x)
    - One product (Personal AI Computer), three configs: 2x Home / 4x Team / 8x On-prem business
    - Lift the 8-GPU build out of the repo root so all three are peers (entry-first)
    - New front-door README: own-your-intelligence -> pick-your-config -> what-it-runs -> quick start
    - Add /software (setup + testing now; local model-serving in progress)
    - Add CONTRIBUTING + share-your-build / build-question issue templates
    - Fix broken image paths (case mismatch broke 2x/8x galleries), parens-in-filename, stale LICENSE link, dead 4x badge URLs; 178/178 local links verified
    [Ethernet mount.step, Ethernet mount.stl, GPU mount 1.step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]
2026-07-04 README: one sharp intro; drop the redundant 'What it can run' section (#2)
    * README: merge the tagline and 'Why this exists' into one intro
    Both said the same thing — hardware no one can switch off vs. rented
    models cut off overnight. One paragraph now: the why, the what, the
    close.
    * README: drop 'What it can run' — the config table already covers it
    ---------
2026-07-04 README: replace the config table with three build photos
    Pick your build: 2x (Home), 4x (Team), 8x (On-prem business) — photo
    links straight to each guide. Specs live in the guides, not the
    landing. Drops the now-duplicate 'The configurations' list.
2026-07-04 README: title, why, video — in that order
    'Build your own Personal AI Computer' as the H1, the intro paragraph
    right under it, then the assembly video. Drops the badge row and the
    duplicate tagline block.
2026-07-04 Flatten the repo: builds at root, software as two files
    2x/ 4x/ 8x/ move out of builds/; setup.md and testing.md move out of
    software/. run-models.md is gone — Grid handles serving. The build
    card photos live in their build folders. README's Software section is
    now three steps: setup, testing, run Grid.
    [Ethernet mount.step, Ethernet mount.stl, GPU mount 1.step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]
2026-07-04 README: tighten quick start step 5
2026-07-05 Reorganize: fix post-flatten links, one skeleton for all three builds
    - Fix broken '← All builds' links (../../ pointed outside the repo after
    the flatten) and the broken MCIO image in the 2x prep doc.
    - Fix case-sensitive photo paths in the 8x housing guide that 404'd on
    GitHub, and rename the trailing-space/odd filenames they pointed at.
    - Rewrite the 2x/4x/8x READMEs on one skeleton: spec table, 5-step build
    list, board-specific BIOS notes (general BIOS list stays in setup.md),
    testing, cross-links. Drop the typing-SVG banners, the 8-badge walls
    (half showed zero: no releases exist), and the emoji headers.
    - Bring the 2x and 8x BOMs up to the 4x standard: sequential rows,
    de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
    [Part 4 - Back.stl, Part 4 - Black.stl]
2026-07-05 README: open with the why — three dated reasons to own your AI
    June's Fable 5 / GPT-5.6 government lockouts, Karp's July 1 CNBC point
    on frontier APIs absorbing customer IP, and Chamath's open-vs-closed
    cost math — then the full open-source stack: this repo (hardware) +
    Grid (software).
2026-07-05 README: cut the intro to two paragraphs
2026-07-05 README: sharper intro — Apple contrast, free inference, 'own the means of production'
2026-07-05 README: tighten the Grid mention
2026-07-05 README: 4x placeholder in the housing step
2026-07-05 Builds renamed by GPU: 2x-5090, 4x-5090 (new), 4x-6000, 8x-5090
    - Folders renamed to say what's inside; all internal links rewritten.
    - New 4x-5090 build (the dual-chamber desktop cube from the site) with
    its six studio photos and a guide-in-progress README.
    - Root README: four build sections, each with the exact six-image
    gallery from autonomous.ai/thinking/edgeai — hero, 2x2 grid,
    finished shot, CTA. 4x-6000 keeps its 5U hero.
    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
    [Ethernet mount.step, Ethernet mount.stl, GPU mount 1.step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]
2026-07-05 README: stack heading — end-to-end open-source
2026-07-05 README: the 1975 frame — the Personal AI Computer is the new computer
2026-07-05 README: trim housing note from 2x size line
2026-07-05 README: software step 2 in build context — serve your models
2026-07-05 README: Grid is 'the open orchestrator' — coin the category
2026-07-05 8x: trim housing step
2026-07-07 4x-5090: add housing CAD (STL + STEP)
    Organize the 4x-5090 housing files into stl-models/ and step_models/ with readmes. Wire the README, BOM, and assembly to the 4x's own housing (its own distinct cube, not the 2x case). Correct the dimensions to ~20x20x24 in (measured from the CAD) in the 4x and root READMEs. Ignore .DS_Store.
    Dimensions and the 66 lb weight are from the CAD/prior spec — pending confirmation.
    [3 Fan mount.step, 3 Fan mount.stl, 9 Fan mount.step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]
2026-07-08 4x-6000: merge BOM + component list, drop buy links, add photos
    Merge the electronics component list into the BOM as a single file with a component photo grid, and remove the purchase/source links. Component images are representative product photos (the GPUs are 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

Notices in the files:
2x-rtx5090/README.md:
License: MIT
